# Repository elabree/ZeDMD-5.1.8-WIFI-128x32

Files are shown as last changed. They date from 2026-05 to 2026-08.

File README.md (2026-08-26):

# The Arcade — powered by ZeDMD (WiFi Fork, 128×32, ESP32-S3-N16R8)

> 🇩🇪 **Deutschsprachige Anleitung:** [LIESMICH.md](LIESMICH.md)

**The Arcade** is an ESP32-S3 firmware for a 128×32 HUB75 LED matrix. It turns a pinball DMD panel into a standalone smart display with:

- **Clock + weather** — live data from your own weather station via MQTT (WeeWx), with Open-Meteo as automatic fallback; configurable field names, visual fallback indicator
- **GIF screensaver** — animated GIFs from SD card, sorted alphabetically or shuffled, with optional synchronised MP3 audio per GIF
- **Webradio** — internet radio via I2S amplifier (MAX98357A); station logos, track title, equaliser, L/R swap
- **Web UI** — full configuration and control from any browser on your local network; no app, no account, no cloud

---

> 📝 *This README is a personal project diary rather than a complete guide. It documents what worked for me — your setup may differ. No claim to completeness; errors and omissions are possible.*

---

> **This started as a personal hobby fork of [PPUC/ZeDMD](https://github.com/PPUC/ZeDMD) v5.1.8**
> and has since grown well beyond it — the clock, weather, and webradio features are original
> work built on top, not part of upstream ZeDMD. What *is* inherited from upstream is the core
> DMD protocol handling and the HUB75 display driver — that foundation is why this project
> stays under the same GPLv2-or-later license as ZeDMD itself, and why it remains listed as a
> GitHub fork of it rather than a standalone repo.
> It is shared with the community in the hope that it might be useful — but it comes with **absolutely no support, no warranty, and no guarantee of any kind**.
> Issues and pull requests may not be responded to. Emails and messages regarding this project will likely go unanswered — not out of disrespect, but simply because this is a spare-time project maintained by one person.
> **Use entirely at your own risk.**

---

> ⚠️ **Panel size: only tested with 128×32 (2× chained 64×32 tiles).** The codebase already
> has build environments for larger panels (`256x64` / `S3-N16R8_256x64`, via `ZEDMD_HD`) and
> the core DMD rendering scales automatically with `TOTAL_WIDTH`/`TOTAL_HEIGHT` — but this has
> **not been built or tested**. The weather overlay and GIF screensaver have hardcoded pixel
> positions sized for 128×32 that would need adapting first.
>
> If you do try a larger panel: pay **significantly more attention to power supply sizing**
> than you would for 128×32. A single 64×32 HUB75 tile can draw up to ~25W (5V/5A) at full
> white; going to 256×64 roughly **quadruples the pixel count** versus this project's default
> 128×32 setup, and current draw scales accordingly. Undersized power supplies on large HUB75
> chains cause voltage drop, ghosting/dimming artifacts, and in the worst case connector or
> wiring damage — plan for adequate power injection points along the chain, not just a single
> feed at one corner.

---

https://github.com/jens-b/ZeDMD-5.1.8-WIFI-128x32/raw/main/docs/images/ZeDMD_WiFi_128x32_demo.mp4

---

### Screenshots

| Clock + Weather | Weather Forecast | GIF Screensaver |
|:-:|:-:|:-:|
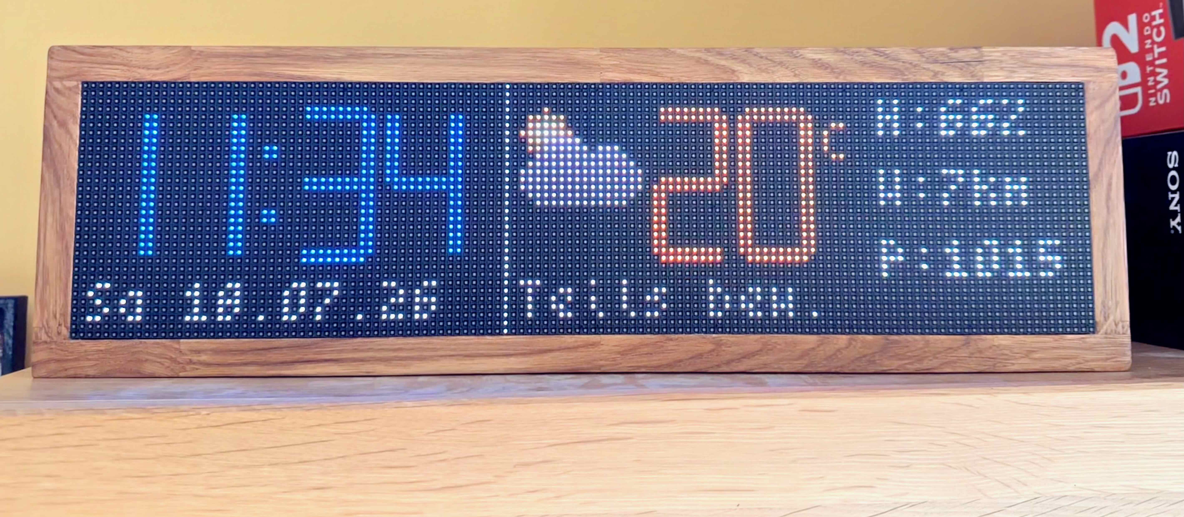
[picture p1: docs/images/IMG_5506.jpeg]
Clock
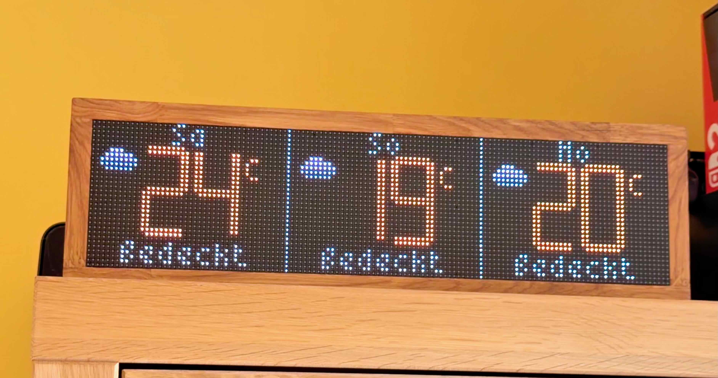
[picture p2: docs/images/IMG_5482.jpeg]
Forecast
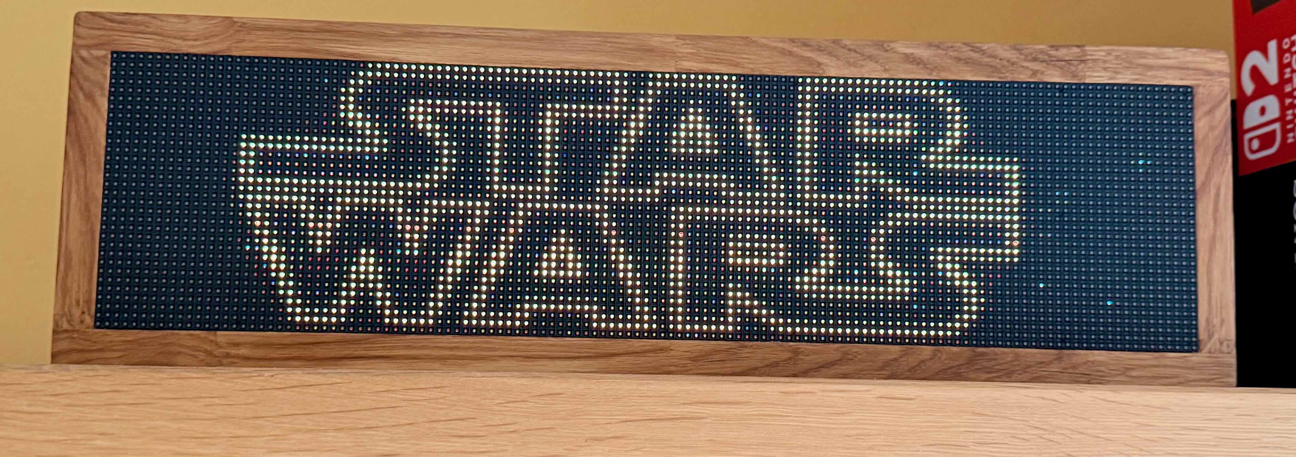
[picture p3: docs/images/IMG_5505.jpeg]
GIF
|  |  |  |

**Webradio — station name and logo on the display:**

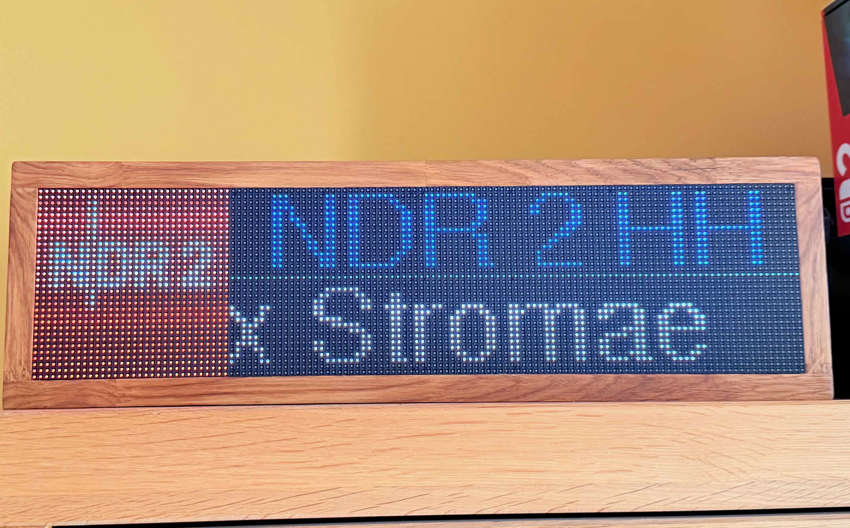
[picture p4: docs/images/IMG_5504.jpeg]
Webradio


**Internals / Back panel:**

| Inside | Back panel |
|:-:|:-:|
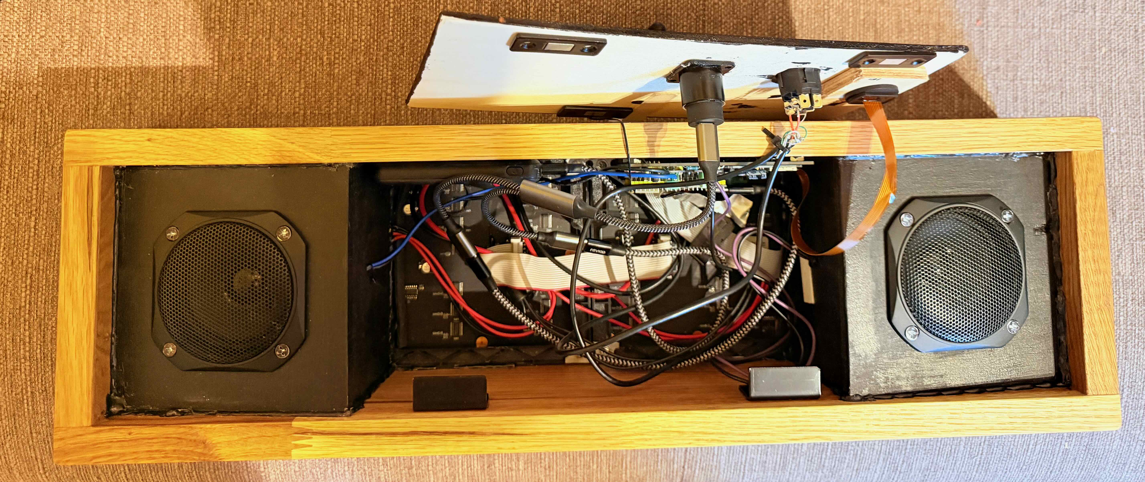
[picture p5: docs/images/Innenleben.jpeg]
Internals
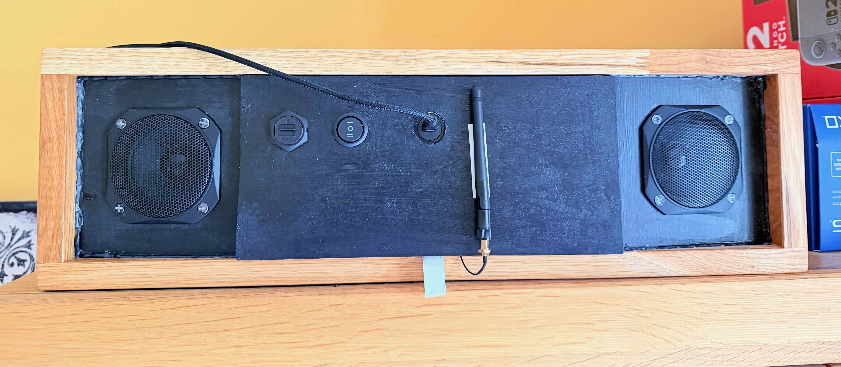
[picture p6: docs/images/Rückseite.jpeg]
Back panel
|  |  |

---

## 🆕 What's new in this release

### v1.7.0 *(this release)*

#### Critical stability fixes — watchdog now actively monitors the main task
A fundamental issue was present since the first WiFi firmware build: `enableLoopWDT()` was never called, meaning the Task Watchdog Timer (TWDT) never actually monitored the main loop task. All `esp_task_wdt_reset()` calls across the codebase were silent no-ops — the device relied only on the secondary IDLE-task starvation mechanism to detect hangs.

With `enableLoopWDT()` now correctly placed at the start of `setup()`, the TWDT actively monitors the loop task against the 5-second budget. This exposed three real hang points that are now fixed:

- **Large screensaver cache** — `TryLoadFolderCache()` reading 3 700+ lines without any watchdog reset caused a reboot loop on devices with many files. Fixed with a reset every 50 lines.
- **SoftAP countdown** — the 19-second WiFi-failure countdown ran without a single reset. Fixed.
- **NTP sync** — `clockInit()` calls `getLocalTime()` with a 5-second timeout, landing exactly on the WDT boundary. A reset is now issued before the call.

Devices that were showing repeated `TASK_WDT` reboot entries in `/diag` after upgrading from a previous firmware version should recover immediately with this release.

#### "The Arcade" startup logo
The boot logo has been updated from the generic PPUC logo to **The Arcade** branding. The crash-screen overlay was also corrected (it previously overwrote the logo during a first-boot crash sequence).

#### Radio icon reload fix
The **Reload Icons** action (`/icons_reload`) now also refreshes the radio icon slug cache. Previously, a newly uploaded station logo only appeared after a full reboot.

#### `/upload_asset` endpoint
A new endpoint accepts any PNG or RAW file and stores it directly in the LittleFS root. Useful for uploading custom boot logos or background assets without a full LittleFS flash.

#### Brightness save respects the display blank timer
Saving brightness via `/save_brightness` previously called `SetBrightness()` directly, which deactivated an active display-blank interval. It now goes through `ApplyBrightness()` and leaves the blank state untouched.

---

### v1.6.0

#### Weather icons — 17×17 pixel art, stored in LittleFS
The main weather icon (top-right of the clock/weather view) has been redrawn at **17×17** instead of 16×16. The odd size places the center on an exact pixel (8, 8) rather than between pixels — sun rays, moon crescent tips and fog lines are now perfectly symmetrical. Specific improvements per icon:

- **Sun** — cardinal rays narrowed to 1 px, lengthened to 3 px; diagonal rays extended toward the body for a more connected look
- **Moon** — wider crescent tips at top and bottom (3 px); crescent ends look rounded rather than pointed
- **Cloud bitmap** — extended from `uint16_t` (16 cols) to `uint32_t` (17 cols); all cloud-based icons benefit
- **Fog** — sixth stripe added at the bottom to fill the extra row
- **Rain / Drizzle / Showers** — drop positions adjusted for equal horizontal spacing

The 11 weather icons are now stored as **RGBA files in LittleFS** (`/icons_weather/`) instead of being hardcoded in the firmware. This means:
- Icons can be **replaced without reflashing** — upload new ones via `/upload_icon_weather`
- The icon set is consistent with the existing system (`/icons/` for emoji, `/icons_radio/` for station logos)
- First-time setup: upload the 11 `weather_*.rgba` files from `data/icons_weather/` after the initial flash

#### Temperature display — tighter minus sign
The minus sign for negative temperatures now **kerns closer to the digit**: for single-digit negatives (`−1` to `−9`) the minus is positioned where the tens digit would be; for two-digit negatives (`−10` to `−19`) it moves 2 px closer to the leading `1`. The result is a more natural, compact look on the 128×32 display.

#### Interactive weather location map
The **Weather (Open-Meteo)** section in `admin.html` now shows a **Leaflet / OpenStreetMap** map. Click anywhere on the map or drag the marker to set your coordinates — no manual lat/lon entry needed. City search is also available. The map initialises at the currently saved coordinates.

#### HUB75 library 3.0.14 + Line Decoder parameter
The ESP32-HUB75-MatrixPanel-DMA library has been updated from **3.0.12 to 3.0.14**. A new **Line Decoder** parameter is now exposed in the Panel section of the admin page — required for panels that use a shift-register-based row decoder instead of direct addressing (rare, but necessary for certain panel types). Default value is 0 (no effect on standard panels). Setting is saved to LittleFS and survives reboots.

#### Removed unused SDMMC build environment
The `S3-N16R8_128x32_wifi_sdmmc_webradio` PlatformIO environment has been removed from `platformio.ini`. It was not actively maintained and only added noise to the build configuration. The standard SPI SD build (`wifi_sd_webradio`) remains the only supported target.

#### 7-segment display styles
Four segment style presets are available under the **Display Settings** section of the web UI:

- **Default** — chamfered corners with junction clearing (original look)
- **Classic** — inner notch at segment junctions; chamfered inner corners
- **Classic 2** — early-build look: L-junction inner pixel + inner chamfer, "0" exempt
- **Modern** — plain rectangular segments, no chamfering

The active style is saved to LittleFS and survives reboots.

#### Glow effect *(beta)*
A **Glow β** button in Display Settings toggles a drop-shadow effect on the clock digits (2 px offset, 30 % brightness). Experimental — not persisted across reboots.

#### Equalizer range extended to ±12 dB
The Bass / Mid / Treble sliders now go from **−12 dB to +12 dB** (previously ±6 dB). Useful for speakers like the FRS8 where cutting bass and boosting treble significantly improves perceived audio clarity.

#### SD card firmware update
Place a `firmware.bin` in the `/UPDATE/` folder on the SD card — on the next boot it is flashed automatically and the file is deleted. A manual trigger button is also available on the **Admin** page for updating without a reboot.

---

### v1.5.3

#### Configurable MQTT field names
The JSON field names used to read weather data from your MQTT broker are now configurable in the admin panel — no reflash required. This matters if your WeeWx (or other weather station) uses non-standard field names. Default values match the standard WeeWx LOOP output: `outTemp_C`, `outHumidity`, `windSpeed_kph`, `barometer_mbar`. Settings are saved to LittleFS and survive reboots.

#### Visual fallback indicator for OpenMeteo data
When MQTT has been silent for more than 10 minutes, the weather display switches to Open-Meteo data as a fallback. All four weather values (temperature, humidity, wind, pressure) are now shown in **grey** instead of white during this fallback period — an immediate visual cue that the data is not coming from your local weather station. After 30 minutes without MQTT, the existing orange **"MQTT fehlt"** text appears as before.

#### Unknown weather code fallback icon
If Open-Meteo returns a WMO weather code that has no matching icon, the display now shows the **question mark icon** (`question.rgba` from the icon set) instead of the misleading cloudy icon that was used before. In practice this should never appear — all codes used by Open-Meteo are handled — but it makes the system more robust.

---

### v1.5.2

#### Tabbed Web UI
The main page has been reorganised into three tabs — **Screensaver**, **Display** and **Radio** — making it much easier to navigate on both desktop and mobile. SD card & storage info plus the Admin button remain always visible above the tabs.

#### Display Timer *(scheduled display off)*
Set a daily on/off schedule for the LED matrix — useful for automatically turning the display off at night. Configure From/Until times under the **Display** tab. A **"Display off / Display on"** button lets you instantly turn the display off and on without changing the timer settings.

#### Stereo / Mono toggle
The **Radio** tab now shows separate **Stereo** and **Mono** buttons next to the volume slider. Switch the audio output to mono without a firmware rebuild — useful if you only have one speaker connected or experience phase issues.

#### Station logos on the LED matrix
When a radio station starts playing, the matching station logo (if uploaded) is shown on the LED matrix alongside the station name and track title.

#### Boot text improvements
Status messages during boot ("booting", "loading...", "SD OK", "LittleFS OK") are now shown at the bottom-left of the display so they no longer overlap the boot logo.

#### Rescan buttons
A **Rescan** button appears in the screensaver file list and the GIF audio file list after an upload — or can be triggered manually at any time. Rescans the SD card and LittleFS without a reboot and updates the file list immediately.

#### SD card SPI speed — up to 40 MHz
On a proper PCB layout (no Dupont wires), the SD card is now initialised at 40 MHz first, with an automatic fallback chain (40 → 25 → 20 → 8 MHz). Previously the maximum was 8 MHz. Faster initialisation and file access, especially noticeable during GIF and audio scans.

#### Equalizer
A three-band **equaliser (Bass / Mid / Treble)** is now available in the **Radio** tab. Settings are saved to LittleFS and survive reboots and station switches.

#### Weather icons — further improvements
The 8×8 forecast icons (3-day view) have been completely redrawn. Three new icons added: drizzle, showers and snow now have their own symbols — previously they shared a generic rain icon. Total: 11 distinct weather icons.

#### L/R channel swap
If your left and right speakers are physically wired the wrong way around, a single **L/R Swap** button in the **Radio** tab swaps the audio channels in software — no rewiring needed. Settings survive reboots.

#### Custom branding
The boot screen and web UI header now show the **The Arcade** logo instead of the generic ZeDMD logo. The PPUC splash screen has been removed.

---

### v1.5.1

#### Weather Icons — native 16×16 pixel art
All 8 weather icons have been redrawn as native 16×16 pixel art — sharper and more detailed than the scaled-up 8×8 bitmaps used before. Each icon has a unique hand-crafted color gradient: sun with rays, crescent moon, cloud, rain drops, snow, lightning bolt, and partly-cloudy variants. The smaller 8×8 icons used in the 3-day forecast were further improved in v1.5.2.

#### SD Card — more robust initialisation
The SD card now retries with progressively slower SPI speeds (8 → 4 → 2 MHz, up to 6 attempts) before giving up. Previously a single failed mount attempt would mark the SD as unavailable for the entire session. This resolves intermittent boot failures with marginally connected or slow-to-mount SD cards.

#### Bug Fixes
- Emoji text: cursor position 0 was treated as falsy in JavaScript — the cursor is now correctly preserved when inserting an emoji at the very start of the input field
- Icon upload: interrupted uploads no longer leave orphaned `.tmp` files on LittleFS
- Icon folder scan: directory handle no longer leaks when a non-directory entry is encountered

---

### v1.5 and earlier

### Webradio
Stream internet radio stations directly through the ZeDMD's built-in speaker.
Requires a **MAX98357A I2S amplifier module** — see wiring below.

- Dedicated station manager at `/radio.html` — search stations via [radio-browser.info](https://www.radio-browser.info), save presets with logo icons
- **Country quick-select buttons** (🇩🇪 DE / 🇦🇹 AT / 🇨🇭 CH / 🇳🇱 NL / 🇫🇷 FR) load the top-100 stations for that country in one tap; Niedersachsen regional filter still available
- Station name, track title and station logo displayed in the web UI
- Volume control via slider on the main page and the radio page
- Station name and track title scroll on the LED matrix for 5 seconds when a station starts, then returns to the screensaver — tap "DMD 10s" to show it again
- Presets survive firmware updates (stored in LittleFS)
- Stable station switching — no more audio dropout on channel change
- Stream URLs from radio-browser.info are automatically normalised (removes `?ti=` playlist hints that caused the audio library to hang)
- **L/R channel swap** — if your left and right speakers are physically wired the wrong way around, a single button in the **Radio** tab swaps the audio channels in software — no rewiring needed

> **Technical note — audio library patch:** The L/R swap feature required modifying the `ESP32-audioI2S` library internally, because it does not provide this function out of the box. Rather than changing the library files by hand (which would be lost on every library update), a build-time patch script (`scripts/patch_audio_lib.py`) injects the change automatically on each compile. This script was developed with the help of **[Claude Code](https://claude.ai/code)** (AI coding assistant by Anthropic) — pinpointing the exact location inside the audio pipeline where samples could be swapped safely, and making the patch idempotent (safe to run repeatedly). I would not have attempted this alone.

> **⚠️ Weather API:** Open-Meteo is accessed via HTTP instead of HTTPS. TLS handshakes consistently caused memory-related crashes in the web radio build. Since Open-Meteo provides public data without requiring a login, HTTPS is not necessary here.

### GIF Preview in the browser
Click any GIF filename in the screensaver file list or the "currently shown" field to open a live animated preview directly in the browser — without touching the display. Favourite, ignore and play controls are available inside the preview.

> **Note:** Opening a GIF preview while webradio is playing may cause brief audio stuttering — SD card access and audio streaming share the same CPU core. This is a known limitation.

### GIF Audio
Play a matching MP3 file from the SD card in sync with an animated GIF screensaver. The filename must match the GIF (e.g. `demo.gif` → `demo.mp3`). Upload audio files via the main page or drop them in `/GifAudio/` on the SD card directly.

- File list is cached in LittleFS — after the first boot scan, subsequent reboots load instantly (same mechanism as the screensaver file cache)
- Paginated file list in the web UI with previous/next buttons (20 files per page)
- Scan can be aborted via the **"Cancel Scan"** button that appears after an upload

> ⚠️ **First-boot scan time:** Depending on how many files are in `/GifAudio/`, the initial scan over SPI can take a very long time. Progress is shown on the display ("GifAudio XXXX"). After the scan the list is cached in LittleFS — every subsequent reboot loads in seconds.

> **Note:** GIF audio plays once per GIF cycle — looping is not yet implemented.

### SDMMC Board Support *(not actively maintained)*
Added support for boards with an **onboard SD card via SDMMC interface** (1-bit mode) — no external SPI module required. See pin table below for the required HUB75 cable changes.

> **Note:** This build variant is not actively maintained. Development focus is on the standard SPI SD build (`wifi_sd_webradio`). The SDMMC variant may work but is not tested with each release.

### GIF Screensaver Order
- **A-Z toggle** — switch between alphabetical and random playback order directly on the main page
- **Reshuffle button** — re-randomise the GIF order at any time without a full reload

### Configurable Timezone
The NTP clock timezone can now be set directly on the admin page — no firmware rebuild required.
A dropdown covers the most common zones (Central Europe, UK, UTC, US East/Central/Mountain/Pacific); a **Custom** option accepts any POSIX timezone string for full flexibility. The setting is stored in LittleFS and survives reboots.

### SD Card Mount / Eject
The main page now shows a **Mount / Eject** toggle button next to the SD card status bar.
- **⏏ Eject** (grey) — safely unmounts the SD card so it can be removed while the device stays powered
- **⏻ Mount** (green) — remounts the card after reinsertion; updates the screensaver file list and GIF audio cache automatically

### Stability & Bug Fixes
This release includes a comprehensive overhaul of memory management and task safety:

- **Admin page no longer crashes** — root cause identified via coredump analysis: lwIP assertion in AsyncTCP 3.3.5 triggered by the Basic Auth handshake. Fixed by updating AsyncTCP to 3.4.10
- Fixed race condition on station switching — audio no longer reverts to the previous station
- Weather data (MQTT + HTTP) now safely synchronized between CPU cores
- SD card directory listing moved out of network callbacks — no more audio stuttering during web access
- Weather HTTP response buffered in PSRAM — eliminates large internal SRAM spike during fetch
- All file uploads are now atomic (`.tmp` + rename) — interrupted uploads no longer leave corrupt files
- `screensaverFiles` array protected by mutex against concurrent web access
- Audio task priority raised above the web server task — reduces stream dropouts under concurrent web traffic

---

## 🧪 Experimental Features

> These features are functional but still being polished. Use at your own risk and expect rough edges.

---

### Batocera WiFi streaming

By default, Batocera's DMD server only streams to a single USB-connected DMD. To stream to a WiFi ZeDMD at the same time, a second `dmdserver` instance needs to be set up manually.

A full step-by-step guide — including dual-DMD marquee control, attract/playing modes, and troubleshooting — is available here:

📄 **[docs/batocera-dual-dmd.md](docs/batocera-dual-dmd.md)** (EN) | **[docs/batocera-dual-dmd-DE.md](docs/batocera-dual-dmd-DE.md)** (DE)

> ⚠️ Tested with Batocera **v42**. Batocera **>v42** may have introduced changes that break this setup. Verify carefully before updating Batocera.

---

### Batocera game start/stop trigger

`scripts/batocera_game_start.sh` and `scripts/batocera_game_stop.sh` trigger GIF audio playback on ZeDMD when a game starts or stops on Batocera. The DMD itself continues to receive live frames from the emulator as usual — these scripts only control the audio layer.

> ⚠️ Not yet fully tested end-to-end — the `/gif_audio_play` endpoint works, but the Batocera-side trigger has not been verified in a real game session.

**How it works:**
- On game start: Batocera sends the ROM name to ZeDMD → ZeDMD plays the matching MP3 from `/GifAudio/` on the SD card
- On game stop: ZeDMD stops audio playback
- Naming convention: ROM filename without extension → `medieval_madness.zip` → `medieval_madness.mp3`

**Setup:**
1. Open both scripts and set `IP_ZEDMD` to your ZeDMD's fixed IP address
2. Copy to Batocera:
   ```bash
   scp scripts/batocera_game_start.sh root@batocera.local:/userdata/system/scripts/gameStart.sh
   scp scripts/batocera_game_stop.sh root@batocera.local:/userdata/system/scripts/gameStop.sh
   ```
3. Place matching MP3 files on the SD card under `/GifAudio/`

> ⚠️ **If a `gameStart.sh` already exists on Batocera** (e.g. from another project), do **not** replace it — append the `curl` call from the script to the existing file instead.

---

### Batocera audio extraction script

`scripts/extract_gif_audio.sh` extracts the first N seconds of audio from Batocera scraped game videos and saves them as MP3 files ready for ZeDMD.

> ⚠️ Tested on Batocera only. Requires `ffmpeg` and `python3` available on the Batocera system.

**Prerequisites:**
- Batocera with SSH access
- `ffmpeg` installed on Batocera (check: `which ffmpeg`)
- `python3` installed on Batocera (check: `which python3`)
- Scraped game videos in `gamelist.xml` (`/userdata/roms/<system>/`)

**Usage (run via SSH on Batocera):**
```bash
ssh root@batocera.local "bash /tmp/extract_gif_audio.sh [options]"
```

| Option | Default | Description |
|---|---|---|
| `--system` | `mame` | ROM system folder name |
| `--limit` | `10` | Max number of files to extract |
| `--duration` | `15` | Clip length in seconds |
| `--out` | `/userdata/zedmd/gif_audio` | Output directory |
| `--game` | *(all)* | Filter by partial game name |

**Workflow:**
1. Copy the script to Batocera: `scp scripts/extract_gif_audio.sh root@batocera.local:/tmp/`
2. Run it via SSH (see above)
3. Open the output folder in Finder: **Network → batocera → share → zedmd → gif_audio**
4. Upload the MP3 files via **`http://<ZeDMD-IP>/`** → GIF-Audio section

---

### Display Text

Send a custom text message to the LED matrix directly from the web UI.

- Static or scrolling display — short texts are shown centered, longer texts scroll automatically
- Color picker for free RGB color selection
- Configurable display duration (5–60 seconds)
- Instantly interrupts any running screensaver or GIF and restores it afterwards
- **Emoji picker** — 34 emojis (❤️ ⭐ 🔥 😊 🎉 and more) rendered as pixel-art icons directly in the scrolling text; icons are stored as RGBA files in LittleFS (`/icons/`)

---

### Stereo Audio

Stereo output using **two MAX98357A modules** — one for the left channel, one for the right.

The SD pin is a voltage-level channel-select strap. The values below were measured and confirmed to work with MAX98357A breakout boards that already have a **1 MΩ resistor from SD to Vin** onboard. If your board has a different onboard resistor, these values will not apply — always check your board's schematic and measure before connecting.

* **Module L (Left Channel):** Connect a **100 kΩ** resistor from SD to VCC **(5V)**.
* **Module R (Right Channel):** Connect a **390 kΩ** resistor from SD to VCC **(5V)**.

The ESP32-audioI2S library outputs stereo I2S natively when playing stereo source files. Each module automatically decodes its designated channel based on the SD pin voltage.

| MAX98357A Pin | ESP32-S3 | Notes |
|---|---|---|
| BCLK | **GPIO 9** | shared — both modules |
| LRC (WSEL) | **GPIO 14** | shared — both modules |
| DIN | **GPIO 21** | shared — both modules |
| SD — Module L | **100 kΩ to VCC** | → **Left channel** |
| SD — Module R | **390 kΩ to VCC** | → **Right channel** |
| VIN | **5V** *(recommended)* | each module separately |
| GND | **GND** | each module separately |

> ⚠️ The resistor values above are verified at **5V only**. For 3.3V supply the right-channel value changes to approx. **210 kΩ** (untested). 3.3V supply is **not recommended** — it increases distortion and loads the 3.3V rail.

> ⚠️ **DISCLAIMER:**
> These resistor values were determined experimentally with a specific MAX98357A breakout board variant that has a 1 MΩ onboard resistor from SD to Vin. Other board variants may require different values. **Always consult the MAX98357A datasheet, check your board's actual schematic, and measure voltages before connecting.**
> **Use entirely at your own risk — no warranty or liability of any kind.**

---

## 🔜 Planned Features

### Custom PCB by [elabree](https://github.com/elabree) ✅
A dedicated carrier board designed and built by [elabree](https://github.com/elabree) — tested and confirmed working with this firmware. The board hosts the ESP32-S3-DevKitC-1-N16R8, an SD card module socket, and two MAX98357A stereo amplifier sockets on a single clean PCB.

Two revisions are available:
- **Rev1.1** — for original Espressif ESP32-S3-DevKitC (0.9″ pin row spacing)
- **Rev1.2** — for most clone boards (1″ pin row spacing)

KiCad sources and Gerber files for ordering at JLCPCB: [KiCad/ZeDMD_WiFi/](https://github.com/jens-b/ZeDMD-5.1.8-WIFI-128x32/tree/main/KiCad/ZeDMD_WiFi) (included in this repository).

A big thank-you to elabree for designing and contributing this board to the project — this would not have happened without his work.

### Code cleanup *(on my list)*
The code has grown organically and is honestly a bit messy in places — I know. I'm planning to clean things up at some point, but no promises on when. It works, which counts for something.

---

## What's different from original ZeDMD

This fork is **WiFi-only** and targets the **ESP32-S3-N16R8** with a **128×32 LED matrix**.

### All added features

- **WiFi OTA firmware update** — flash new firmware directly via browser (`/admin.html`); firmware version with build ID and branch shown on admin page (format: `5.1.8-jb (date) [abc1234@main]`)
- **Screensaver** — GIF/RAW slideshow with clock and weather display (Open-Meteo, plain HTTP for RAM efficiency)
- **Screensaver management** — favorites, ignore list, alphabetical/random order, strict timer, pause/resume
- **GIF Preview** — click any filename to open an animated browser preview; favorite/ignore/play controls inside the preview
- **GIF Audio** — play a matching MP3 from `/GifAudio/` on the SD card in sync with the screensaver GIF; `scripts/extract_gif_audio.sh` extracts audio from Batocera video files
- **Improved web interface** — file management, per-file favorite/ignore buttons, pagination with wrap-around
- **Admin page** — WiFi, display, transport, MQTT, weather settings
- **Webradio** — internet radio via I2S amplifier (MAX98357A); station search via [radio-browser.info](https://www.radio-browser.info); preset management with logo icons; LED matrix shows station info for 5 s on start, "DMD 10s" button for on-demand display
- **Config Export/Import** — full configuration backup and restore via browser (`/config_transfer.html`)
- **Display Text** — send custom text with emojis to the LED matrix via the web UI; static or scrolling with color selection and configurable duration (5–60 s); 34 emojis available via built-in picker
- **LittleFS icon system** — three icon folders: `/icons/` (20×20 emoji/question), `/icons_weather/` (17×17 weather icons, uploadable via `/upload_icon_weather`), `/icons_radio/` (32×32 station logos); splash assets via `/upload_asset`
- **Display Timer** — schedule daily on/off times for the LED matrix (e.g. off at 23:00, on at 07:00); "Display off / Display on" button for instant manual control
- **Tabbed web UI** — main page organised into Screensaver / Display / Radio tabs; SD card & admin always visible
- **Stereo Audio** *(experimental)* — two MAX98357A modules for true stereo output; channel selection via SD-pin resistor strapping (5V only, values verified); Stereo/Mono toggle in the web UI

---

## Hardware — ESP32-S3-N16R8 Note

### 💡 Power supply

The ZeDMD can draw a noticeable amount of current — especially when bright GIFs are displayed, webradio is streaming, and WiFi is active all at once. A laptop USB port or a basic phone charger may not deliver enough stable power for this, which can lead to unexpected reboots or an unstable display.

**If things seem unreliable: use a decent 5V / 2A USB power adapter** (the kind that comes with a good phone or tablet). How much power is actually needed varies quite a bit depending on the content — dark GIFs with no audio use much less than a bright screensaver at full volume.

---

### 🧠 On the verge of a nervous breakdown — what this little chip is actually doing

At any given moment, the ESP32-S3 in this build is simultaneously:

- driving a 128×32 HUB75 LED matrix over DMA
- serving a full web UI with live updates over WiFi
- streaming and decoding webradio (MP3/AAC) over I2S in a dedicated FreeRTOS task
- reading and playing animated GIFs from an SD card
- playing matching MP3 files in sync with those GIFs
- fetching live weather data and rendering icons
- handling MQTT, OTA, file uploads, and a paginated file browser for 2 000+ files
- maintaining a LittleFS cache, crash logs, and boot diagnostics

All of this on a chip with **327 KB of internal SRAM** — of which the WiFi stack, TCP server, and audio buffers claim most at runtime, leaving sometimes less than **1 KB free** at peak load. The 8 MB PSRAM handles the large caches and pixel buffers, but anything touching WiFi or TCP must live in internal SRAM — and that is genuinely tight.

The firmware works hard to keep things stable: PSRAM-backed caches, careful buffer sizing, staggered HTTP requests, and a heap monitor that logs free memory every 30 seconds. But this is a device running at the edge of what its hardware class was designed for — and it shows, in the best possible way.

---

### ⚠️ Missing 5V on VIN pin (IN-OUT solder bridge)

Some ESP32-S3-N16R8 boards do not provide 5V on the VIN pin out of the box.
If your ZeDMD powers up but the LED matrix stays dark or behaves unexpectedly, check the **IN-OUT solder bridge** near the 5V/GND pins.

**Fix:** Close the IN-OUT bridge with a small solder blob to route 5V from USB to the VIN pin.

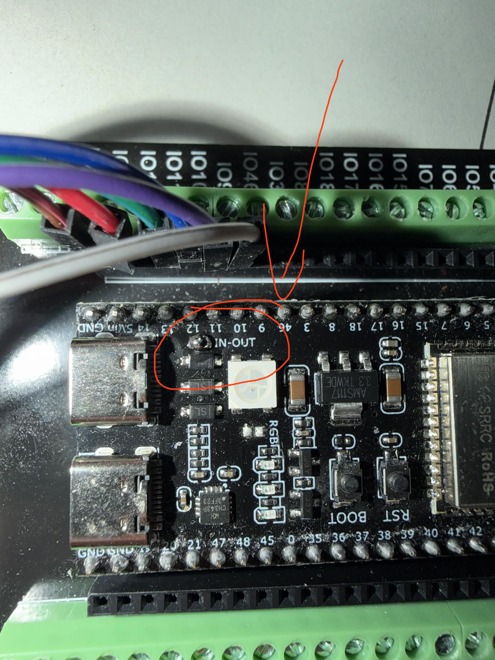
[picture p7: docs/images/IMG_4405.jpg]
IN-OUT bridge location

IN-OUT close-up

> ⚠️ Modifying hardware is at your own risk!

For other known hardware issues and general ZeDMD documentation see the **[original ZeDMD README](https://github.com/PPUC/ZeDMD#readme)**.

---

## SD Card

The screensaver GIF/RAW files can be stored on a microSD card connected via SPI.

**Tested module:**
[Micro SD Card Module SPI (Amazon)](https://www.amazon.de/dp/B0D8Q8N7NQ)

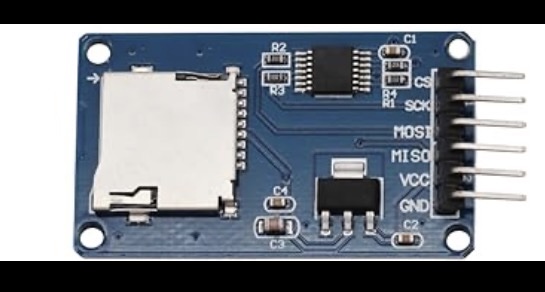
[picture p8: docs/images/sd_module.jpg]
SD Card Module


**Wiring ESP32-S3-N16R8:**

| SD Module | ESP32-S3 Pin |
|---|---|
| VCC | **3.3V** or **5V** ¹ |
| GND | GND |
| MISO | GPIO 13 |
| MOSI | GPIO 11 |
| SCK | GPIO 12 |
| CS | GPIO 10 |

> ¹ Most common SPI SD modules accept both 3.3V and 5V on VCC (they have an onboard regulator).
> Check your module's datasheet. If in doubt, use **3.3V** — the ESP32-S3 GPIO pins are **not** 5V-tolerant.

**Format:** FAT32, files in subfolders (e.g. `/MyGIFs/`). GIF and RAW files supported.

**First-boot scan performance**

> ⚠️ The first scan of a large GIF library can take a very long time — a folder with ~5 400 files takes approximately **35 minutes** over SPI. This is a fundamental SPI/FAT32 limitation: the Arduino SD library opens every file individually to read its name, and FAT32 directories with many entries cannot be indexed.
>
> **After the first scan the file list is cached in LittleFS** (`sc_*.bin`). Every subsequent reboot loads the cache in seconds — no SD scan needed.
>
> **Tips to keep scan times acceptable:**
> - Use **multiple smaller subfolders** instead of one large one (e.g. 5 × 1 000 files instead of 1 × 5 000) — each folder is scanned independently and cached separately.
> - Use a **dedicated upload folder** (small, freshly uploaded files only) — the web UI's "Upload folder" picker lets you target it specifically without touching the large library folder.
> - A planned future optimisation is an **SD-side index file** (`.index` per folder) that replaces directory traversal with a single sequential read — reducing scan time from minutes to under a second regardless of file count.

---

## Web Interface

Access via `http://<IP>/` (main page) and `http://<IP>/admin.html` (admin page).

### Admin page settings

| Section | Description |
|---|---|
| **Firmware Update (OTA)** | Flash new firmware via browser — no USB needed |
| **WiFi** | SSID, password, port |
| **Display** | RGB order, scaling mode, brightness |
| **Transport** | USB / WiFi UDP / TCP / SPI, UDP delay, USB packet size |
| **Panel** | Clock phase, I2S speed, latch blanking, refresh rate, driver |
| **MQTT** | Server IP and port for weather integration |
| **Weather (Open-Meteo)** | Latitude/longitude for local weather display |
| **Update Web Files** | Upload index.html / admin.html without full filesystem flash |
| **Upload Weather Icons** | Upload 17×17 RGBA icons to LittleFS `/icons_weather/` via `/upload_icon_weather` |
| **Upload Assets** | Upload PNG/RAW splash images to LittleFS root via `/upload_asset` |
| **Config Export/Import** | Full config backup/restore via `/config_transfer.html` |
| **Information** | Firmware version, build date and git hash, debug info |

---

## Pin Assignment ESP32-S3-N16R8

### HUB75 LED Matrix

| Signal | GPIO | Note |
|---|---|---|
| R1 | 4 | |
| G1 | 5 | |
| B1 | 6 | |
| R2 | 7 | |
| G2 | 15 | |
| B2 | 16 | |
| A | 18 | |
| B | 8 | |
| C | 3 | |
| D | 42 | |
| E | 1 | not used - only for 256×64 |
| OE | 2 | |
| LAT | 40 | `wifi_sd_webradio` |
| LAT | **46** | `wifi_sdmmc_webradio` — rewire! |
| CLK | 41 | `wifi_sd_webradio` |
| CLK | **17** | `wifi_sdmmc_webradio` — rewire! |

> HUB75 LAT/CLK only need to be moved on the **SDMMC board**, because GPIO 40/41 are used internally for the SD card there.

### SD Card

| Signal | GPIO | Build |
|---|---|---|
| CS | 10 | `wifi_sd_webradio` (SPI) |
| MOSI | 11 | `wifi_sd_webradio` (SPI) |
| SCK  | 12 | `wifi_sd_webradio` (SPI) |
| MISO | 13 | `wifi_sd_webradio` (SPI) |
| DATA | 40 | `wifi_sdmmc_webradio` (SDMMC onboard) |
| CLK  | 39 | `wifi_sdmmc_webradio` (SDMMC onboard) |
| CMD  | 38 | `wifi_sdmmc_webradio` (SDMMC onboard) |

### Buttons

| Function | GPIO |
|---|---|
| UP | 0  |
| DOWN | 45 |
| FORWARD  | 48 |
| BACKWARD | 47 |

### Webradio (optional)

Requires an **I2S amplifier module** and a small speaker.

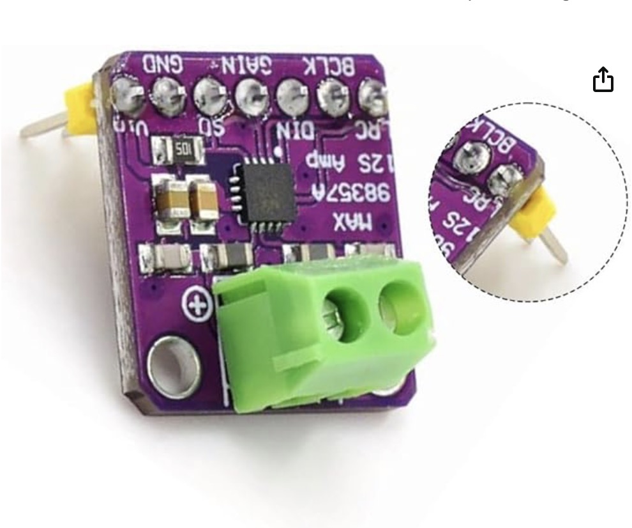
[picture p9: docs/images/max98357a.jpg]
MAX98357A module


**Tested amplifier: MAX98357A**
- Breakout module (e.g. Adafruit #3006 or common clones)
- Speaker: **8 Ω / 3 W** — e.g. **Visaton FSR 7** (77 mm, good sound for the size)
- Output power: up to 3 W — adequate for a cabinet at moderate volume

### MAX98357A Wiring — Mono (SD and SDMMC builds)

| MAX98357A Pin | ESP32-S3 | Notes |
|---|---|---|
| VIN | **5V** | 5V gives more headroom; 3.3V works but lower volume |
| GND | GND | |
| BCLK | **GPIO 9** | I2S Bit Clock |
| LRC (WSEL) | **GPIO 14**  | I2S Word Select (L/R) |
| DIN | **GPIO 21**  | I2S Data |
| GAIN | **GND** | GND = 15 dB gain (max); floating = 12 dB; 3.3V = 9 dB |
| SD (Shutdown) | 3.3V or floating | Floating = on; GND = mute |

> Class-D mono amplifier. Connect speaker to OUT+/OUT− only — **not** to GND (differential/BTL output).

### Build / Environment Overview

| Setup | Environment | Extra hardware |
|---|---|---|
| Existing board + SPI SD module | `S3-N16R8_128x32_wifi_sd_webradio` | Connect MAX98357A |

### Webradio — Configuration

Open `http://<IP>/` after flashing — radio controls appear directly on the main page:

| Control | Description |
|---|---|
| **▶ / ■** | Play last preset / Stop |
| **Station buttons** | Start a saved preset directly |
| **Volume** | Slider on the main page and on `/radio.html` |
| **DMD 10s** | Show station info on the LED matrix for 10 seconds; auto-hides after 5 s when a station starts |

Full preset management at **`http://<IP>/radio.html`**.
Presets are stored in LittleFS (`/radio_presets.json`) and survive firmware updates.
Config transfer between boards: `http://<IP>/config_transfer.html`

---

## Weather (Open-Meteo)

Weather and 3-day forecast fetched from [Open-Meteo](https://open-meteo.com/) — free, no API key required.
Set your coordinates in `admin.html` → **Weather (Open-Meteo)**.

### ⚠️ Why HTTP, not HTTPS

The audio codec (MP3/AAC) occupies ~50 KB of internal SRAM at runtime. A TLS handshake needs an additional ~30–40 KB of contiguous internal SRAM — a guaranteed out-of-memory crash on the webradio build. Since Open-Meteo serves fully public weather data with no authentication tokens, plain HTTP is completely safe here.

> `http://api.open-meteo.com/v1/forecast` — explicitly supported by Open-Meteo for embedded/IoT devices.

---

## Installation

### First flash (USB, one time only)

The first flash must include the LittleFS filesystem image — otherwise the web interface won't load after boot. Use the merged image approach:

```bash
pio run                              # build firmware
pio run -t buildfs                   # build LittleFS image from data/
python3 scripts/merge_firmware.py    # create merged flash image
```

Then flash the resulting `*_merged.bin` from `~/Desktop/Firmwares/`:

```bash
esptool.py --chip esp32s3 --port /dev/cu.usbmodem* --baud 460800 \
  write_flash --no-compress 0x0 "ZeDMD_..._merged.bin"
```

> ⚠️ **`--no-compress` is required.** The LittleFS partition occupies 6.5 MB of flash. Without `--no-compress`, esptool compresses the transfer — this causes a timeout on the large partition and the ESP hangs mid-flash. Always use `--no-compress` for the full merged image.

### After first boot

The web interface loads immediately. Upload updated HTML files if needed:
**`http://<IP>/admin.html`** → "Update Web Files"

### Future firmware updates (OTA, no USB needed)

Browser → **`http://<IP>/admin.html`** → "Firmware Update (OTA)"

---

## Credits

- **[Markus Kalkbrenner / PPUC](https://github.com/PPUC/ZeDMD)** — original ZeDMD project
- **[elabree](https://github.com/elabree)** — PCB design: carrier board for DevKit + SD + MAX98357A ([KiCad files](https://github.com/jens-b/ZeDMD-5.1.8-WIFI-128x32/tree/main/KiCad))
- **Niels (My Son)** — coding assistance & inspiration & moral support
- **[Claude Sonnet](https://anthropic.com)** — coding assistance

---

## Commercial Use

This project is licensed under GPL v2 — commercial use is permitted under those terms.

---

## License

Same as the original project — see [LICENSE](LICENSE).

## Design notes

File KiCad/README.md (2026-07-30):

# ZeDMD_WiFi PCB
This is a carrier board for the ESP32-S3-DevKitC-1-N16R8 with the following features:
- ZeDMD compatible HUB75 connector for RGB Matrix Panels and 4 push-buttons
- 5V terminal block with 2 different use cases:
  - Output for the RGB panels, using power from USB-C (a jumper on J5 selects between the DevKit or USB-C breakout at J8)
  - Input for the DevKit, in case the RGB panels are on an external supply (jumper on J6)
- A socket (J2) for a Micro SD Card module. Note that this module needs to have a 5V - 3.3V regulator. Always check that the pinout of your module corresponds to the [schematics diagram](ZeDMD_WiFi/docs/ZeDMD_WiFi.pdf)
- Two sockets (J1 and J3) for MAX98357A amplifier modules (Adafruit i2s class-d mono-amp). A jumper on J4 selects between 3 power options (Devkit 3.3V, Devkit USB-C 5V, USB-C breakout at J8).
- A socket ()J8 for a USB-C breakout board for MAX98357A power. It can also be used if there is no other power source for the Devkit, or to power the RGB panels when selected by a jumper on J5.

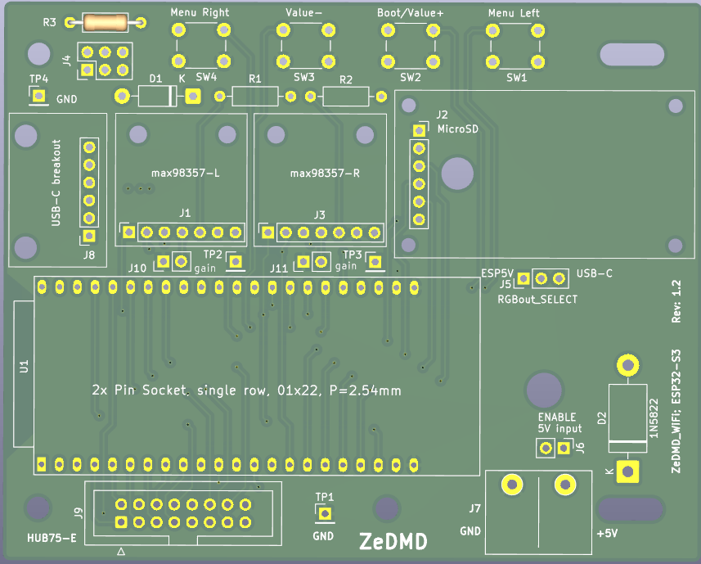
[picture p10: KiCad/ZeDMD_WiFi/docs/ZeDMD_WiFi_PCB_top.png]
ZeDMD_WiFi_PCB_top


## Power budget
The power supply voltage is +5V.

### USB-C limitation
The maximum current USB-C can deliver at 5V is 3A (Pmax = 15W). It does not matter that a USB-C PD port is able to deliver more power because that means using a higher voltage. This is not possible with this design!

### RGB matrix panel
Two 64x32 RGB matrix panels draw 5A (25W) at 100% intensity. Since these panels are designed for daylight operation, this intensity is really high. Usually no more than 50% is needed (2.5A, 12.5W). This leaves sufficient power (0.5A; 2.5W) for the DevKit and SD card.

### MAX98357A modules
The required power for the amplifiers depends on the supply voltage (3.3V or 5V) and the connected speakers. If there is insufficient power avalable, the supply may dip during loud sounds causing clipping at the output. This may damage the speakers. Also, the amplifiers have a volume dependent distortion which is less at 5V for the same volume.

#### Power needs for 2 MAX98357A modules:
| Vin | Rspeaker | Pout_max | Iin (Pin)  |
| --- | --- | --- | --- |
| 3.3V| 8 ohm | 0.9 W | 0.6 A (2 W) |
| 3.3V| 4 ohm | 1.6 W | 1.1 A (3.6 W) |
| 5V  | 8 ohm | 1.8 W | 0.9 A (4.5 W) |
| 5V  | 4 ohm | 3.2 W | 1.6 A (8 W) |

### Power supply Recommendations
1. If USB-C is the preferred way to power everything: Then it is best to use the USB-C breakout power the RGB matrix panel (3W for the LED's); place a jumper at J5 2-3. A second USB-C cable on the DevKit powers the SD card and the amplifier modules; place a jumper at J4 3-4.
2. The best alternative is a 5V Meanwell (clone) switchmode power supply (SMPS). Connect the RGB matrix panels directly to this supply. If the DevKit is powered with USB-C there must be no jumpers on J5 & J6, the USB-C breakout is not needed, choose a 25W power supply in this case.
3. It is also an option to use a 5V SMPS for everything in case there is no USB-C connection. Then, J7 is used as the +5V supply input for the DevKit, SD card and amplifier modules. A 40W power supply feeds the RGB matrix panels directly, with an additional cable to J7. Place a jumper at J6, no jumper at J5!
*Note that options 2 and 3 allow full brighness of the RGB panels*

## Options
The general recommendation is: only mount the parts you will be using. So, if you don't need speaker outputs, don't mount the amplifier modules. If you don't use the push buttons, there is no need to mount them.

### RGBout at J7
Diode D2 will cause a voltage drop of 0.7 V to reduce voltage at the panels. The main reason is that some RGB panels do not work correctly at 5V. If the RGB panels work correctly at 5V, a wire bridge can be used instead of the diode.
A jumper on J5 is needed to select the power source.

### 5Vin at J7
As explained a jumper (or wire bridge) at J6 is only needed if the DevKit does not have an USB-C connection. In that case J7 becomes the 5V input.

### MAX_Vin
J4 selects the power source for the amplifier modules. The best option is a jumper between pins 3-4 (+5V from DevKit)

### MAX98357A gain
J10 and J11 can be used to select the amplifier gain. The default gain is 9dB if nothing is connected. For 12dB place a jumper or wire bridge. A 100k resistor can be placed for even more gain (15dB).
*Note that this only adjusts the volume, it will not increase the maximum output power.* TP2 and TP3 are connected to Vin. These testpoints are normally not needed. But these can be used to decrease the gain if needed...

## More information
[Licensed under the TAPR Open Hardware License (www.tapr.org/OHL)](LICENSE.txt)
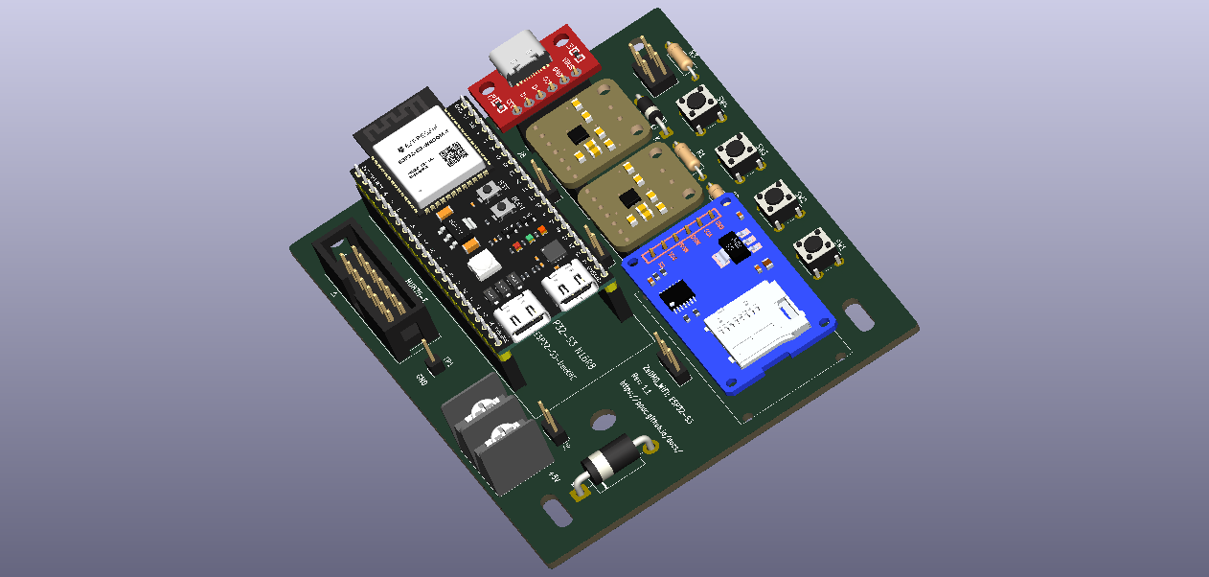
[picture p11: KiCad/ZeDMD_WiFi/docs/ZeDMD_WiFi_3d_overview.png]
ZeDMD_WiFi_PCB_top

[info](ZeDMD_WiFi/docs)

## Gerber and Drill files for PCB ordering
1. The Espressif ESP32-S3-DevKitC has 0.9" distance between rows: [production_Rev1.1.zip](/KiCad/ZeDMD_WiFi/production_Rev1.1.zip)
2. Most clones have 1" distance between rows: [production_Rev1.2.zip](/KiCad/ZeDMD_WiFi/production_Rev1.2.zip)
Example [ordering information](ZeDMD_WiFi/docs/ZeDMD_WiFi_JLCPCB_ordering.png)

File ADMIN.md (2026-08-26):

# ZeDMD Developer Reference

Entwickler-Dokumentation für das ZeDMD-5.1.8 WiFi 128×32 Projekt.

---

## Hardware

| Komponente | Details |
|---|---|
| SoC | ESP32-S3-N16R8 (16 MB Flash, 8 MB PSRAM) |
| Display | 128×32 HUB75 LED-Matrix (RGB888, 3 Byte/Pixel = 12.288 Byte/Frame) |
| SD-Karte | SPI-Bus: SCK=12, MISO=13, MOSI=11, CS=10 |
| Audio (I2S) | **2× MAX98357A (Stereo)**, Pins: BCK=9, WS=14, DATA=21 — Kanalwahl per SD-Pin-Widerstand gegen 5V: L=100 kΩ, R=390 kΩ (Breakout-Boards haben 1 MΩ onboard SD→Vin) |
| Display-Bus | ESP32-S3 LCD-Peripheral mit DMA (kein Software-Bitbanging) |

### Entwickler-Board v2

Abweichende SD/I2S-Pins — in `platformio_override.ini` als separates Environment `wifi_sd_webradio_devboard_v2` definiert (nicht im Repo).

---

## Flash-Partitionen

```
nvs        data/nvs        0x9000     20 KB   WiFi-Credentials, NVS-Variablen
otadata    data/ota        0xE000      8 KB   OTA-Boot-Slot-Auswahl
app0       app/ota_0      0x10000   3200 KB   Firmware-Slot A
app1       app/ota_1     0x330000   3200 KB   Firmware-Slot B (OTA-Target)
spiffs     data/spiffs   0x650000   9916 KB   LittleFS (Icons, HTML, Settings)
coredump   data/coredump 0xFDF000    128 KB   Panic-Coredump (fest reserviert)
```

---

## Build-System

### Umgebungen

```bash
pio run          # beide Environments bauen (default_envs in platformio_override.ini)
```

Niemals `-e` verwenden — immer beide Environments bauen.

### Build-Workflow (Pflicht-Reihenfolge)

```bash
# 1. Test-Build: prüft Kompilierung
pio run

# 2. Commit (erst nach grünem Build)
git commit -m "..."

# 3. Release-Build: bettet korrekten Git-Hash ein
pio run

# 4. Firmware kopieren
HASH=$(git rev-parse --short HEAD)
BRANCH=$(git rev-parse --abbrev-ref HEAD | sed 's|/|-|g')
cp .pio/build/S3-N16R8_128x32_wifi_sd_webradio/firmware.bin \
   ~/Desktop/Firmwares/ZeDMD_5.1.8-jb_S3-N16R8_128x32_wifi_sd_webradio_${BRANCH}_${HASH}.bin
cp .pio/build/S3-N16R8_128x32_wifi_sd_webradio/firmware.elf \
   ~/Desktop/Firmwares/ZeDMD_5.1.8-jb_S3-N16R8_128x32_wifi_sd_webradio_${BRANCH}_${HASH}.elf
# analog für devboard_v2
ls -t ~/Desktop/Firmwares/*.elf | tail -n +3 | xargs rm -f   # max 2 ELFs behalten
```

> **Warum ELF archivieren?** Coredumps sind nur mit dem ELF der exakt gleichen Firmware analysierbar. Nach jedem Rebuild wird das ELF überschrieben.

### Upload-Regeln

| Was | Wie |
|---|---|
| Firmware (`src/`) | PlatformIO flashen via USB |
| HTML/CSS/JS (`data/`) | `POST /upload_file` im Browser — kein Datenverlust, kein PlatformIO |
| Einzelne LittleFS-Dateien (`.raw`, `.png`, `.html`, …) | **ESP Connect Tool** — verbindet direkt mit LittleFS, lädt einzelne Dateien hoch ohne Datenverlust. Kein `uploadfs` (löscht alle Einstellungen!) |
| Icons (`data/icons/`) | `POST /upload_icon` oder `/upload_icon_small` |
| GIFs/Screensaver | `POST /upload_screensaver` oder direkt auf SD |

---

## Architektur

### Speicher-Strategie

```
Interner Heap (~214 KB dynamisch):
  - HTTP-Server-Puffer, FreeRTOS-Task-Stacks
  - Temporäre Puffer (<10 KB pro Allokation)
  - NIEMALS String += in Schleifen — führt zu Fragmentierung

PSRAM (8 MB, ~7.4 MB frei):
  - renderBuffer[]      3×  12.288 Byte  (~36 KB, Triple-Buffering Pixel-Daten RGB888)
  - screensaverFiles    N×    128 Byte   (~350 KB bei 2800 GIFs, via heap_caps_realloc wachsend)
  - cachedSDFolders     variabel JSON    (wenige KB, SD-Ordnerliste)
  - cachedGifAudioFiles variabel JSON    (bis ~300 KB während Scan, danach realloc auf Exactgröße)
  - logBuffer           80×   120 Byte  (~10 KB Ringpuffer)
  - uncompressBuffer         2.048 Byte  (UDP-Dekompression)
  - gifReadAheadBuf          4.096 Byte  (nur während GIF-Wiedergabe aktiv)
```

**Regel:** Alle Caches und Listen die >10 KB sein können → `heap_caps_malloc(..., MALLOC_CAP_SPIRAM)`.  
JSON-Aufbau in Schleifen → direkt per `snprintf` in PSRAM-Puffer, nie per Arduino `String +=`.

### Display-Pipeline

```
UDP/TCP-Paket → Dekodierung → renderBuffer[currentRenderBuffer]
                                      ↓
                              FillPanelRaw(buf)
                                      ↓
                          DMA → HUB75 LED-Matrix
```

- `NUM_RENDER_BUFFERS = 3` (Triple-Buffering für ruckelfreie Ausgabe)
- `currentRenderBuffer` / `lastRenderBuffer` — kein Mutex in `loop()` (bewusste Design-Entscheidung für maximale FPS)
- `renderBuffer[]` wird **vor** `LittleFS.begin()` allokiert (PSRAM-Allokation früh, vor Display-Init)

### FreeRTOS

| Task | Core | Prio | Stack | Beschreibung |
|---|---|---|---|---|
| loopTask (Arduino) | Core 1 | 1 | 32 KB | setup() + loop(), HTTP-Responses, Screensaver, Display |
| radioTask | Core 0 | 11 | 16 KB | ESP32-audioI2S Webradio-Streaming (intern) |
| async_tcp | Core 0 | 10 | ~8 KB | AsyncWebServer / AsyncTCP |
| mqttTask | Core 0 | 1 | 8 KB | MQTT-Reconnect + mqttClient.loop() |
| Task_ReadSerial | Core 0/1 | 1 | 4–8 KB | Serielle ZeDMD-Protokoll-Kommunikation |
| Display-Refresh | Core 0 | — | — | DMA-gesteuert, kein FreeRTOS-Task |

**WDT-Budget:** `CONFIG_ESP_TASK_WDT_PANIC=y` — TASK_WDT löst Panic aus.  
In `setup()` nach jeder längeren Operation `esp_task_wdt_reset()` aufrufen.  
LittleFS-Writes können auch ohne Schleife >5 s dauern (Flash-Fragmentierung).

### Screensaver-Cache

```cpp
char (*screensaverFiles)[128]  // PSRAM, via heap_caps_realloc wachsend
uint16_t screensaverCount      // aktuelle Anzahl
```

Wird in `loop()` nach `screensaverReloadNeeded == true` via `LoadScreensaver()` befüllt.  
Kein Mutex für Lese-Zugriff in `loop()` — bewusst (ruckelfreie GIF-Wiedergabe + UDP-Throughput).  
Mutex nur für Web-Handler-Zugriff (`screensaverFilesMutex`).

### GIF-Audio-Cache

```cpp
char* cachedGifAudioFiles  // PSRAM, JSON-String: [{"name":"foo.mp3","size":12345},...]
```

Wird **nicht** in `loop()` befüllt, sondern einmalig beim Start via `TryLoadGifAudioCache()` aus LittleFS (`/gif_audio_cache.bin`) geladen. Nur bei Cache-Miss: vollständiger SD-Scan in `BuildGifAudioCache()` (~130 s bei 1958 Dateien), danach `SaveGifAudioCache()` schreibt kompaktes `name|size\n`-Format zurück nach LittleFS.

**Besonderheiten:**
- `/gif_audio_files`-Endpoint sendet `cachedGifAudioFiles` **direkt** als HTTP-Response — kein Serialisierungsschritt
- Alphabetische Sortierung erfolgt **clientseitig** per `localeCompare` in `gifAudioLoad()` (FAT-Verzeichnisreihenfolge ≠ alpha)
- `f.name()` muss via `strncpy` **vor** `f.close()` kopiert werden — SdFat2 invalidiert den internen Namenspuffer beim Close
- Architektur-Unterschied zu Screensaver: kein struct-Array, kein wahlfreier Index-Zugriff — geplantes Refactoring: P4 #58

**Invalidierung:**
- `InvalidateGifAudioCache()` löscht `/gif_audio_cache.bin` auf LittleFS → nächster `TryLoadGifAudioCache()`-Aufruf schlägt fehl → Neu-Scan
- RAM-Pointer `cachedGifAudioFiles` bleibt bis zum abgeschlossenen Scan mit alten Daten (oder `"[]"`) gefüllt

---

## Boot-Sequenz

```
setup()
  ├─ renderBuffer[] allokieren (PSRAM, vor LittleFS)
  ├─ LittleFS.begin() + lfsTotal/lfsUsed cachen (verhindert TASK_WDT via /fs_info)
  ├─ diagBoot()               — Crash-Log schreiben falls letzter Boot ein Crash war
  ├─ esp_task_wdt_reset()
  ├─ Display-Init + DisplayLogo() + "booting"-Text   — Logo sofort sichtbar (~2s)
  ├─ esp_task_wdt_reset()
  ├─ CleanupTmpFiles()
  ├─ Load*() × 8              — Settings aus LittleFS (kann 10+ s dauern)
  ├─ esp_task_wdt_reset()
  ├─ LoadIcons()              — RGBA-Icons aus LittleFS + radioIconSlugsLoad() (~6s bei 219 Icons)
  ├─ InitSDCard()
  ├─ GetSDFolders()           — SD-Ordner in PSRAM cachen
  └─ screensaverReloadNeeded = true

loop()
  ├─ screensaverReloadNeeded → LoadScreensaver()
  ├─ Screensaver-Tick
  ├─ Radio-Update
  ├─ Wetter-Update
  └─ sdFoldersRefreshNeeded → GetSDFolders()
```

---

## LittleFS-Inhalt (`data/`-Ordner)

Der `data/`-Ordner wird via `pio run -t buildfs` in `littlefs.bin` gepackt und ist Teil der Merged Firmware. Ein frisches Gerät bekommt damit alles auf einmal.

| Pfad | Inhalt | Anzahl |
|---|---|---|
| `data/index.html` | Web-UI Hauptseite | 1 Datei |
| `data/radio.html` | Web-UI Radio-Sektion | 1 Datei |
| `data/icons/` | 20×20 RGBA Emoji-Icons (Lauftext, Wetter) | 38 Dateien |
| `data/icons_small/` | 10×10 RGBA Emoji-Icons (kleine Darstellung) | 38 Dateien |
| `data/icons_radio/` | 32×32 RGBA Sender-Logos | 219 Dateien |

> **Wichtig:** Alle Icons und Logos liegen im Repo unter `data/`. Das Merged-Image enthält alles — kein manueller Upload nach dem Erstflash nötig.

---

## Scripts (`scripts/`-Ordner)

| Script | Sprache | Was es tut |
|---|---|---|
| `merge_firmware.py` | Python | Erstellt All-in-One Flash-Image (Bootloader + Partitionen + Firmware + LittleFS) für Erstflash per USB. Aufruf: `python3 scripts/merge_firmware.py [ENV]` |
| `upload_icons.sh` | Bash | Lädt alle RGBA-Icons aus `data/icons/`, `data/icons_small/` und `data/icons_radio/` per HTTP auf ein laufendes Gerät hoch. Aufruf: `./scripts/upload_icons.sh <IP>` |
| `convert_icons.py` | Python | Konvertiert Emoji-GIFs (aus `~/Downloads/zedmd-emoji-gifs/`) und Wetter-GIFs in RGBA-Binärdateien für `data/icons/` und `data/icons_small/`. Benötigt Pillow. |
| `make_radio_logos.py` | Python | Konvertiert DAB+-Logos (ZIPs, radioart-Ordner, manuelle PNGs) in 32×32 RGBA-Dateien für `data/icons_radio/`. Mapping via `radioart_map.csv`. |
| `extract_gif_audio.sh` | Bash | Läuft direkt auf Batocera per SSH. Extrahiert Audio-Clips aus gescrapten Spielvideos als MP3 für den `/GifAudio/`-Ordner auf der SD-Karte. |
| `batocera_game_start.sh` | Bash | Ablage auf Batocera als `/userdata/system/scripts/gameStart.sh`. Triggert beim Spielstart den `/gif_audio_play`-Endpoint des ZeDMD. IP im Script anpassen. |
| `batocera_game_stop.sh` | Bash | Ablage auf Batocera als `/userdata/system/scripts/gameStop.sh`. Stoppt GIF-Audio beim Spielende. |
| `copy_firmware.py` | Python | PlatformIO `extra_scripts`-Hook: bettet Git-Hash und Branch als C-Defines in den Build ein. Wird automatisch von PlatformIO aufgerufen, nie manuell. |
| `patch_audio_lib.py` | Python | PlatformIO `extra_scripts`-Hook: patcht `ESP32-audioI2S` bei GCC14 (min()-Typkonflikt). Wird automatisch aufgerufen. |
| `adjust_raw_img.py` | Python | Hilfstool: lädt eine 256×64 RGB-RAW-Datei und erlaubt Bildanpassungen. Für Entwicklung/Debug. |
| `display_raw_img.py` | Python | Hilfstool: zeigt eine 128×32 RGB-RAW-Datei an (ppuc.raw). Für Entwicklung/Debug. |
| `radioart_map.csv` | CSV | Mapping-Tabelle DAB+-Service-ID (hex) → Slug für `make_radio_logos.py`. |

---

## Icons

### Große Icons (20×20 RGBA)

- Pfad auf LittleFS: `/icons/<name>.rgba`
- Geladen beim Boot via `LoadIcons()` in `iconTable[]` (PSRAM)
- Genutzt für: Emoji-Lauftext, Wetter-Icons

### Kleine Icons (10×10 RGBA)

- Pfad auf LittleFS: `/icons_small/<name>.rgba`
- Werden **nicht** beim Boot geladen (zu viele, werden nicht genutzt)
- Dateien bleiben auf LittleFS, können on-demand gelesen werden

### Wetter-Icons — WMO-Code-Mapping

OpenMeteo liefert einen `weather_code` (WMO-Standard, Teilmenge). Das Display wählt daraus ein Icon:

| WMO-Code(s) | Beschreibung | Icon-Nr | Icon-Datei |
|---|---|---|---|
| 0, 1 (Tag) | Sonnig / Heiter | 0 | *(gezeichnet)* |
| 0, 1 (Nacht) | Klar | 6 | *(Mond, gezeichnet)* |
| 2 (Tag) | Teils bewölkt | 1 | *(gezeichnet)* |
| 2 (Nacht) | Teils bew. (Nacht) | 7 | *(Mond+Wolke, gezeichnet)* |
| 3 | Bedeckt | 2 | *(gezeichnet)* |
| 45, 48 | Nebel | 10 | *(gezeichnet)* |
| 51–57 | Nieselregen | 3 | *(gezeichnet)* |
| 61–67 | Regen | 8 | *(gezeichnet)* |
| 71–77 | Schnee | 4 | *(gezeichnet)* |
| 80–82 | Schauer | 9 | *(gezeichnet)* |
| 85–86 | Schneeschauer | 4 | *(gezeichnet)* |
| 95+ | Gewitter | 5 | *(gezeichnet)* |
| alle anderen | Unbekannt | 255 | `icons/question.rgba` |

Der aktuelle `weather_code` erscheint im Log als `Wetter: Code=<n> isDay=<0/1>` bei jedem OpenMeteo-Fetch (~alle 15 Min.).

**Priorität:** MQTT liefert Temperatur, Luftfeuchtigkeit, Wind, Druck mit höchster Priorität. OpenMeteo liefert immer: `weather_code` (Icon) + Forecast. OpenMeteo liefert Messwerte nur wenn MQTT >10 Min. still war (grau auf Display) oder nicht konfiguriert ist.

### Radio-Icons (on-demand)

- Pfad auf **LittleFS**: `/icons_radio/<slug>.rgba`
- Slug-Liste wird beim Boot via `radioIconSlugsLoad()` in PSRAM gecacht (256 × 32 Byte)
- Beim Senderwechsel: Fuzzy-Match gegen PSRAM-Cache, dann einzelnes RGBA-File-Read aus LittleFS
- Slug aus Sendername: Kleinbuchstaben, Sonderzeichen → `_`

---

## Crash-Analyse

### Diagnose-Endpoints

```bash
curl http://<IP>/diag                  # Boot-Statistik + verfügbare Crash-Slots
curl http://<IP>/crashlog?n=0          # Crash-Log Slot 0 (letzter Serial-Log des Absturz-Boots)
curl -o coredump.bin http://<IP>/coredump   # Roher ELF-Coredump
```

### Coredump analysieren

```bash
~/.platformio/penv/bin/python -m esp_coredump info_corefile \
  --core coredump.bin --core-format raw \
  --gdb ~/.platformio/tools/toolchain-xtensa-esp-elf/bin/xtensa-esp32s3-elf-gdb \
  ~/Desktop/Firmwares/ZeDMD_5.1.8-jb_S3-N16R8_128x32_wifi_sd_webradio_main_<HASH>.elf
```

> Coredump und ELF **müssen von derselben Firmware-Version** stammen — SHA256 muss übereinstimmen.

### addr2line für Backtrace-Adressen

```bash
~/.platformio/tools/toolchain-xtensa-esp-elf/bin/xtensa-esp32s3-elf-addr2line \
  -e ~/Desktop/Firmwares/<name>.elf -f 0x<ADRESSE>
```

### Diagnose-Reset

```bash
curl -X POST http://<IP>/reset_diag       # Boot-Zähler zurücksetzen
curl -X POST http://<IP>/delete_crashlogs # Crash-Logs löschen
```

> **Coredump-Partition:** Immer 128 KB reserviert. Löschen gibt keinen Flash-Platz frei — nächster Crash überschreibt automatisch.

---

## Bekannte Constraints & Design-Entscheidungen

| Thema | Entscheidung | Grund |
|---|---|---|
| Kein Mutex in `loop()` für screensaverFiles | Bewusst | Ruckelfreie GIF-Wiedergabe + UDP-Throughput |
| `icons_small` nicht beim Boot laden | Bewusst | 38 Dateien × ~200 ms = 8 s Boot-Overhead, aktuell nicht genutzt |
| `delay()` in SD-Scan vermeiden | Pflicht | SPI-Kontextverlust bei `vTaskDelay()` → Scan-Hänger |
| Arduino `String +=` in Schleifen | Verboten | Heap-Fragmentierung → OOM-Crashes bei 1000+ Dateien |
| `#define` in `.cpp` für Bibliotheks-Konfiguration | Funktioniert nicht | Immer `build_flags` in `platformio.ini` nutzen |
| SD-Scan alle 50 Dateien `esp_task_wdt_reset()` | Pflicht | WDT-Budget bei großen Sammlungen |
| `f.name()` vor `f.close()` via `strncpy` kopieren | Pflicht | SdFat2-internen Puffer invalidiert `f.close()` — `const char*` danach ungültig (Bug: 1958 Dateien → nur 805 gespeichert) |

---

## API-Referenz (Web-Endpoints)

### Diagnose

| Endpoint | Methode | Beschreibung |
|---|---|---|
| `/diag` | GET | Boot-Zähler, Reset-Grund, Crash-Slots (JSON) |
| `/crashlog?n=0` | GET | Crash-Log Slot 0–9 |
| `/coredump` | GET | Roher ELF-Coredump (128 KB) |
| `/debug_info` | GET | IP, SSID, Heap, PSRAM, Uptime |
| `/log` | GET | Letzter In-Memory-Ringpuffer |
| `/fs_info` | GET | LittleFS-Speicherinfo (JSON) |
| `/sd_info` | GET | SD-Karten-Info (JSON) |

### Wartung

| Endpoint | Methode | Beschreibung |
|---|---|---|
| `/reset_diag` | POST | Diagnose-Zähler zurücksetzen |
| `/delete_crashlogs` | POST | Alle Crash-Logs löschen |
| `/restart` | POST | Gerät neu starten |
| `/reset_wifi` | POST | WLAN löschen → Access Point |
| `/eject_sd` | POST | SD sicher auswerfen |
| `/mount_sd` | POST | SD neu einbinden |

### Konfiguration

| Endpoint | Methode | Beschreibung |
|---|---|---|
| `/export_config` | GET | Alle Einstellungen als JSON |
| `/import_config` | POST | Einstellungen aus JSON wiederherstellen |
| `/get_version` | GET | Firmware-Version + Git-Hash |
| `/ota` | POST | OTA-Firmware-Update (Binary als Body) |

### Dateiverwaltung

| Endpoint | Methode | Beschreibung |
|---|---|---|
| `/upload_file` | POST | Datei in LittleFS (HTML, Icons, Logo) |
| `/upload_screensaver` | POST | GIF auf SD |
| `/upload_sd` | POST | Beliebige Datei auf SD |
| `/upload_icon` | POST | 20×20 RGBA Icon in LittleFS |
| `/upload_icon_small` | POST | 10×10 RGBA Icon in LittleFS |
| `/upload_icon_radio` | POST | Sender-Icon auf SD |
| `/delete_screensaver?file=` | GET | GIF von SD löschen |
| `/delete_sd_file?file=` | GET | SD-Datei löschen |
| `/sd_files?folder=` | GET | Dateiliste eines SD-Ordners |
| `/sd_folders` | GET | Alle SD-Ordner (aus PSRAM-Cache) |

### Display & Screensaver

| Endpoint | Methode | Beschreibung |
|---|---|---|
| `/screensaver_status` | GET | Aktueller Pfad, Index, Gesamtanzahl |
| `/screensaver_files?offset=0` | GET | Dateiliste paginiert (20/Seite) |
| `/screensaver_folder_count` | GET | Anzahl geladener Dateien |
| `/screensaver_pause` | POST | Anhalten / Fortsetzen |
| `/screensaver_reshuffle` | POST | Zufallsreihenfolge neu mischen |
| `/screensaver_rescan` | POST | Alle Ordner-Caches invalidieren + Neu-Scan erzwingen |
| `/set_screensaver_paths` | POST | Aktive Quellen konfigurieren |
| `/display_text` | POST | Text anzeigen (`text=`, `r=`, `g=`, `b=`, `scroll=`, `duration=`) |
| `/display_text_stop` | POST | Text-Anzeige beenden |
| `/display_timer` | GET | Timer-Status lesen (`enabled`, `from`, `until`, `blank`) |
| `/display_timer` | POST | Timer konfigurieren (`enabled=1`, `from=23:00`, `until=07:00`) |
| `/display_blank` | POST | Display sofort aus/ein (`blank=1` / `blank=0`; ohne Parameter: Toggle) |
| `/play_file` | POST | GIF/RAW direkt abspielen |
| `/gif_preview?file=` | GET | Erstes Frame als PNG |

### GIF-Audio

| Endpoint | Methode | Beschreibung |
|---|---|---|
| `/gif_audio_files` | GET | Dateiliste (JSON aus PSRAM) |
| `/gif_audio_upload` | POST | MP3 in `/GifAudio/` auf SD |
| `/gif_audio_delete` | POST | MP3 löschen |
| `/gif_audio_rescan` | POST | Cache invalidieren + Neu-Scan erzwingen |
| `/cancel_gif_audio_scan` | POST | Laufenden Scan abbrechen |

---

*Letzte Aktualisierung: 2026-07-17*

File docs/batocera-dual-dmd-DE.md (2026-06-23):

# Batocera Dual-DMD Einrichtung — USB + WiFi ZeDMD

> ⚠️ **Experimentell** — getestet mit Batocera **v42**. Vor einem Batocera-Update sorgfältig prüfen.
>
> Diese Anleitung ist ein persönliches Setup-Protokoll. Es funktioniert auf meinem Cabinet — Hardware und Batocera-Version können bei dir abweichen. Keine Garantie, kein Support.

---

## Übersicht

Batoceras eingebauter DMD-Server (`dmd_real`) unterstützt standardmäßig nur ein einzelnes USB-DMD. Diese Anleitung fügt eine **zweite dmdserver-Instanz** hinzu, die gleichzeitig an ein WiFi-ZeDMD (128×32) streamt.

```
USB-DMD   → 256×64 px, Standard-Port   (dmd-play --hd)
WiFi-DMD  → 128×32 px, Port 9001       (dmd-play -p 9001)
```

Beide DMDs zeigen beim Durchblättern das Marquee des gewählten Spiels. Beim Spielstart übernimmt `zedmd_marquee.sh` mit Arcade-typischem Verhalten (Insert Coin, Now Playing usw.).

---

## Benötigte Dateien

**Scripts:**

| Datei | Zweck |
|---|---|
| `postshare.sh` | Boot-Script — startet beide dmdserver + Screensaver |
| `zedmd_marquee.sh` | Marquee-Steuerung (gameStart/gameStop-Hook) |
| `game-selected.sh` | Marquee beim Durchblättern der Spielliste |
| `system-selected.sh` | Marquee beim Durchblättern der Systemliste |

**GIF-Animationen:**

| Datei | Größe | Verwendung |
|---|---|---|
| `screensaver.gif` | beliebig | Bootbild (automatisch skaliert auf beiden DMDs) |
| `insert-coin.gif` | 256×64 | Attract-Modus — USB-DMD |
| `now-playing-128x32.gif` | 128×32 | Spielmodus — WiFi-DMD |
| `press1or2.gif` | 256×64 | Credit-Anzeige — USB-DMD |
| `press1or2_128x32.gif` | 128×32 | Credit-Anzeige — WiFi-DMD (optional) |

**Config:**

| Datei | Zweck |
|---|---|
| `config_real2.ini` | Konfiguration für die zweite dmdserver-Instanz (WiFi-DMD) |

---

## Ordnerstruktur auf Batocera

```
/boot/
└── postshare.sh

/userdata/system/
├── scripts/
│   └── zedmd_marquee.sh
├── services/
│   └── (dmd_real2 existiert nicht — WiFi-dmdserver wird von postshare.sh gestartet)
└── dmd/
    ├── screensaver.gif
    ├── insert_coin/
    │   ├── insert-coin.gif               (256×64)
    │   └── now-playing-128x32.gif        (128×32)
    ├── press1or2.gif                     (256×64)
    ├── press1or2_128x32.gif              (128×32, optional)
    ├── systems/
    │   └── mame.png / snes.png ...
    └── games/
        └── mame/
            ├── dkong.gif                 ← Spielmarquee USB-DMD (256×64)
            └── 128x32/
                └── dkong.gif             ← Spielmarquee WiFi-DMD (128×32)

/userdata/system/configs/emulationstation/scripts/
├── game-selected/
│   └── game-selected.sh
└── system-selected/
    └── system-selected.sh

/userdata/system/configs/dmdserver/
└── config_real2.ini                      ← WiFi-DMD-Server-Config
```

---

## Schritt 1 — Zweiten DMD-Service einrichten (WiFi-DMD)

> ℹ️ **Aktuelle Implementierung:** Das Service-Script `/userdata/system/services/dmd_real2` wird **nicht verwendet**. Der WiFi-dmdserver wird ausschließlich von `postshare.sh` gestartet (Schritt 2). In `batocera.conf` steht `dmd_real2` als aktivierter Service — das ist harmloser Ballast, da kein Script vorhanden ist.
>
> **Warum kein Service-Script?** User-Services starten über `S99userservices` — viel zu spät. `postshare.sh` läuft als `S12` und zeigt damit Inhalte schon während des Bootens. Ein reines Service-Script würde das WiFi-DMD beim Boot stumm lassen.
>
> Der folgende Abschnitt dokumentiert den Service-Script-Ansatz als **Referenz** für ein späteres Neuaufsetzen oder eine Migration auf Batocera >v42.

**Original-Service kopieren:**
```bash
cp /usr/share/batocera/services/dmd_real /userdata/system/services/dmd_real2
```

**`dmd_real2` bearbeiten:**
```bash
nano /userdata/system/services/dmd_real2
```

```sh
#!/bin/sh
PIDFILE=/var/run/dmd_server_real2.pid

start() {
    echo -n "Starting second dmd-server (WiFi): "
    ARGS="-c /userdata/system/configs/dmdserver/config_real2.ini"
    start-stop-daemon -S -b -q -m -p $PIDFILE --exec /usr/bin/dmdserver -- ${ARGS} >/dev/null &
    echo "done"
}

stop() {
    echo -n "Stopping second dmd-server (WiFi): "
    /usr/bin/dmd-play --port 9001 --clear
    start-stop-daemon -K -q -p $PIDFILE
    echo "done"
}

status() {
    start-stop-daemon --status -q -p $PIDFILE && echo "started" || echo "stopped"
}

case "$1" in
    start)  start  ;;
    stop)   stop   ;;
    status) status ;;
esac
```

> ⚠️ Der Port (9001) wird in `config_real2.ini` definiert, **nicht** als Kommandozeilen-Argument.

**Config-Datei erstellen** unter `/userdata/system/configs/dmdserver/config_real2.ini` — Port 9001 und die WiFi-IP des ZeDMD eintragen.

**Service aktivieren:**
Batocera-Menü → System-Einstellungen → Services → `dmd_real2` aktivieren

---

## Schritt 2 — Boot-Script (`postshare.sh`)

Das Boot-Script sorgt dafür, dass beide DMDs direkt beim Start ein Bild anzeigen. Es läuft als `S12` — früh im Boot-Prozess, lange vor `S99` wo die Services starten.

`/boot/postshare.sh`:

```bash
#!/bin/bash
LOGFILE="/userdata/system/dmd.log"
echo "postshare started" >> "$LOGFILE"

# Auf USB-DMD-Gerät warten (ttyACM)
TIMEOUT=10
COUNTER=0
PATTERN="/dev/ttyACM*"
while [ -z "$(ls $PATTERN 2>/dev/null)" ] && [ $COUNTER -lt $TIMEOUT ]; do
  sleep 1; ((COUNTER++))
done

if [ -z "$(ls $PATTERN 2>/dev/null)" ]; then
  echo "Error: no ttyACM device found." >> "$LOGFILE"
  exit 1
fi

DEVICE=$(ls $PATTERN | head -n 1)
echo "Device $DEVICE ready" >> "$LOGFILE"

# USB-DMD-Server starten
pkill dmdserver
sleep 1
/usr/bin/dmdserver &
echo "dmdserver (USB) started" >> "$LOGFILE"
sleep 2

# WiFi-DMD-Server starten (mit PID-Datei — verhindert Doppelstart durch Service)
WLAN_PIDFILE=/var/run/dmd_server_real2.pid
if ! start-stop-daemon --status -q -p $WLAN_PIDFILE 2>/dev/null; then
    start-stop-daemon -S -b -q -m -p $WLAN_PIDFILE \
        --exec /usr/bin/dmdserver -- \
        -c /userdata/system/configs/dmdserver/config_real2.ini >/dev/null
    echo "dmdserver (WiFi) started" >> "$LOGFILE"
    sleep 2
else
    echo "dmdserver (WiFi) already running" >> "$LOGFILE"
fi

# Screensaver auf beiden DMDs
nohup /usr/bin/dmd-play --hd -f /userdata/system/dmd/screensaver.gif >/dev/null 2>&1 &
echo "bootlogo USB sent" >> "$LOGFILE"

nohup /usr/bin/dmd-play -p 9001 -f /userdata/system/dmd/screensaver.gif >/dev/null 2>&1 &
echo "bootlogo WiFi sent" >> "$LOGFILE"
```

```bash
chmod +x /boot/postshare.sh
```

> Der WiFi-dmdserver wird hier mit der **gleichen PID-Datei** wie der `dmd_real2`-Service gestartet. Wenn `S99userservices` später versucht `dmd_real2` zu starten, findet `start-stop-daemon` die vorhandene PID-Datei und überspringt den Start — verhindert eine doppelte Instanz.

---

## Schritt 3 — Marquee-Scripts

### `game-selected.sh` — beim Durchblättern der Spielliste

Pfad: `/userdata/system/configs/emulationstation/scripts/game-selected/game-selected.sh`

Sucht ein Marquee in dieser Reihenfolge:
1. `/userdata/system/dmd/games/<system>/<rom>.gif/png` (exakter Name)
2. `/userdata/system/dmd/games/<system>/<rommin>.gif/png` (vereinfachter Name)
3. Batocera-API (gescraptes Marquee)
4. Spielname als Text
5. Leeren (blank)

Für das WiFi-DMD wird zusätzlich nach einer optimierten 128×32-Version im Unterordner `128x32/` gesucht.

> ⚠️ Wenn `/tmp/zedmd_mode` existiert (Spiel läuft), lässt `game-selected.sh` das WiFi-DMD in Ruhe — `zedmd_marquee.sh` hat die Kontrolle.

### `system-selected.sh` — beim Durchblättern der Systemliste

Pfad: `/userdata/system/configs/emulationstation/scripts/system-selected/system-selected.sh`

Sucht nach:
1. `/userdata/system/dmd/systems/<system>.gif/png`
2. Batocera-API (System-Logo)
3. Leeren (blank)

---

## Schritt 4 — Marquee-Steuerung (`zedmd_marquee.sh`)

Pfad: `/userdata/system/scripts/zedmd_marquee.sh`
```bash
chmod +x /userdata/system/scripts/zedmd_marquee.sh
```

> ℹ️ **Wie wird das Script aufgerufen?** Nicht über ES-Hooks (`game-start` / `game-end`), sondern durch Batoceras **`emulatorlauncher`** — dieser ruft beim Spielstart und -ende automatisch alle ausführbaren Scripts in `/userdata/system/scripts/` auf:
>
> ```
> Spielstart:  zedmd_marquee.sh gameStart <system> <systemname> <emulator> <rompath>
> Spielende:   zedmd_marquee.sh gameStop
> ```
>
> Beispiel MAME: `zedmd_marquee.sh gameStart mame mame mame /userdata/roms/mame/1942.zip`
>
> Im Script relevant: `$1` = Aktion, `$2` = System, `$5` = ROM-Pfad. Das Script läuft als Hintergrundprozess und überwacht per `evtest` die Joystick-Eingaben bis zum Spielende.

**Marquee-Suchreihenfolge — USB-DMD:**
1. `/userdata/system/dmd/games/<system>/<rom>.gif/png`
2. `/userdata/roms/<system>/images/<rom>-marquee.png`
3. `/userdata/roms/<system>/images/<rom>.png`
4. `/userdata/system/dmd/systems/<system>.png`

**Marquee-Suchreihenfolge — WiFi-DMD (128×32):**
1. `/userdata/system/dmd/games/<system>/128x32/<rom>.gif/png` ← bevorzugt
2. `/userdata/system/dmd/games/<system>/<rom>.gif/png`
3. Fallback: gleiches Bild wie USB-DMD (automatisch skaliert)

---

## Anzeigemodi

### ATTRACT-Modus *(Spiel gestartet, noch kein Credit)*
| DMD | Anzeige |
|-----|---|
| USB-DMD | wechselt alle 4s: Spielmarquee ↔ `insert-coin.gif` |
| WiFi-DMD | zeigt: Spielmarquee (128×32 wenn verfügbar) |

### CREDIT-Modus *(Münze eingeworfen)*
| DMD | Anzeige |
|-----|---|
| USB-DMD | `press1or2.gif` |
| WiFi-DMD | `press1or2_128x32.gif` (Fallback: `press1or2.gif`) |

Vorheriger Zustand (ATTRACT/PLAYING) wird gespeichert und nach dem Credit wiederhergestellt.

### PLAYING-Modus *(Start gedrückt, Credit vorhanden)*
| DMD | Anzeige |
|-----|---|
| USB-DMD | Spielmarquee (statisch) |
| WiFi-DMD | wechselt alle 4s: `now-playing-128x32.gif` ↔ Spielmarquee |

---

## Zustandsautomat

```
ATTRACT ──[Münze]──► CREDIT ──[Start, Credits > 0]──► PLAYING
   ▲                   │                                  │
   └──[Start,          │                                  │
   Credits=0,          │ [Start, Credits=0,               │
   war ATTRACT]        │  war ATTRACT]                    │
                       └──────────────────────────────────┘

PLAYING ──[Münze]──► CREDIT ──[Start, Credits > 0]──► PLAYING
                       │
                       │ [Start, Credits=0, war PLAYING]
                       └──────────────────────────────► PLAYING
```

`/tmp/zedmd_prev_mode` speichert den Zustand vor dem Wechsel in CREDIT.

---

## Controller-Belegung

| Taste | Aktion |
|---|---|
| `BTN_BASE3` | Münze einwerfen (Credit +1) |
| `BTN_BASE4` / `BTN_START` | Spiel starten (Credit −1 → PLAYING); kein Credit → zurück zu ATTRACT oder PLAYING |

---

## Temporäre Laufzeit-Dateien

| Datei | Zweck |
|---|---|
| `/tmp/zedmd_lock` | Verhindert mehrere Script-Instanzen |
| `/tmp/zedmd_mode` | Aktueller Zustand (ATTRACT / CREDIT / PLAYING) |
| `/tmp/zedmd_prev_mode` | Zustand vor dem letzten CREDIT |
| `/tmp/zedmd_path` | Marquee-Pfad — USB-DMD |
| `/tmp/zedmd_path_128` | Marquee-Pfad — WiFi-DMD (128×32) |
| `/tmp/zedmd_credit_log` | Credits (eine Zeile = 1 Credit) |

Alle Dateien werden beim Spielende automatisch gelöscht.

---

## Abhängigkeiten

| Tool | Zweck |
|---|---|
| `dmd-play` | DMD-Wiedergabe-Tool |
| `dmdserver` | DMD-Server (läuft zweimal: USB + WiFi) |
| `evtest` | Joystick-Event-Auslesen |
| `udevadm` | Geräteerkennung |
| `nc` | Port-Check (netcat) |
| `wget` + `jq` | Batocera-API-Abfragen (Marquee-Pfade) |

---

## Fehlerbehebung

### Doppelte WiFi-dmdserver-Instanz
**Ursache:** `postshare.sh` und `dmd_real2`-Service versuchen beide den Server zu starten.
**Lösung:** `postshare.sh` nutzt die gleiche PID-Datei wie der Service → zweiter Start wird automatisch übersprungen.

### gameStop räumt `/tmp/zedmd_*` nicht auf
**Ursache:** `pkill -9 -f zedmd_marquee.sh` hat das Script beendet bevor `rm` laufen konnte.
**Lösung:** Immer erst aufräumen, dann beenden — oder `/tmp/zedmd_lock` nutzen um Mehrfachstarts zu verhindern.

### Mehrere Script-Instanzen laufen gleichzeitig
**Ursache:** Batocera ruft Scripts mehrfach auf (z.B. bei ROM-Varianten).
**Lösung:** Lock-Mechanismus über `/tmp/zedmd_lock`.

### WiFi-DMD zeigt falsches Bild während das Spiel läuft
**Ursache:** `game-selected.sh` und `zedmd_marquee.sh` senden gleichzeitig.
**Lösung:** `game-selected.sh` prüft `/tmp/zedmd_mode` → überspringt WiFi-DMD wenn Spiel läuft.

### Kein Marquee für Spiele ohne eigene DMD-Datei
**Lösung:** `find_marquee_path()` durchsucht auch Batoceras Standard-Medienpfade:
`/userdata/roms/<system>/images/<rom>-marquee.png`

### WiFi-DMD friert ein (GIF endet, kein Loop)
**Ursache:** `--once`-Flag in `dmd-play` → GIF wird nur einmal abgespielt.
**Lösung:** `--once` entfernen → GIF läuft in Dauerschleife.

---

## Logging

```bash
# Boot-Log
cat /userdata/system/dmd.log

# Laufende Prozesse
ps aux | grep dmdserver | grep -v grep
ps aux | grep dmd-play  | grep -v grep
ps aux | grep zedmd     | grep -v grep

# Beide dmdserver-Instanzen unterscheiden sich nur am Argument:
#   /usr/bin/dmdserver                            ← USB-DMD  (Port 6789, dmd_real Service)
#   /usr/bin/dmdserver -c .../config_real2.ini    ← WiFi-DMD (Port 9001, postshare.sh)
#
# Nur die WiFi-Instanz prüfen:
pgrep -a -f config_real2.ini

# Aktueller Zustand
cat /tmp/zedmd_mode
cat /tmp/zedmd_path
cat /tmp/zedmd_credit_log

# Port 9001 prüfen
nc -z localhost 9001 && echo "OK" || echo "ERROR"

# WiFi-DMD manuell testen
dmd-play -p 9001 -f /userdata/system/dmd/screensaver.gif

# Temporäre Dateien zurücksetzen
rm -f /tmp/zedmd_*
```

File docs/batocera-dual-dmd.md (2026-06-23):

# Batocera Dual-DMD Setup — USB + WiFi ZeDMD

> ⚠️ **Experimental** — tested with Batocera **v42**. Verify carefully before updating Batocera.
>
> This guide is a personal setup diary. It worked on my cabinet — your hardware and Batocera version may differ. No warranty, no support.

---

## Overview

Batocera's built-in DMD server (`dmd_real`) supports only a single USB-connected DMD out of the box. This guide adds a **second DMD server instance** that streams to a WiFi ZeDMD (128×32) in parallel.

```
USB-DMD   → 256×64 px, default port   (dmd-play --hd)
WiFi-DMD  → 128×32 px, port 9001      (dmd-play -p 9001)
```

Both DMDs show the selected game's marquee while browsing. On game start, `zedmd_marquee.sh` takes over with arcade-style behaviour (Insert Coin, Now Playing, etc.).

---

## Required Files

**Scripts:**

| File | Purpose |
|---|---|
| `postshare.sh` | Boot script — starts both DMD servers + screensaver |
| `zedmd_marquee.sh` | Marquee controller (gameStart/gameStop hook) |
| `game-selected.sh` | Marquee when scrolling the game list |
| `system-selected.sh` | Marquee when scrolling the system list |

**GIF animations:**

| File | Size | Usage |
|---|---|---|
| `screensaver.gif` | any | Boot screen (auto-scaled on both DMDs) |
| `insert-coin.gif` | 256×64 | Attract mode — USB-DMD |
| `now-playing-128x32.gif` | 128×32 | Playing mode — WiFi-DMD |
| `press1or2.gif` | 256×64 | Credit display — USB-DMD |
| `press1or2_128x32.gif` | 128×32 | Credit display — WiFi-DMD (optional) |

**Config:**

| File | Purpose |
|---|---|
| `config_real2.ini` | Config for the second DMD server (WiFi-DMD) |

---

## Folder Structure on Batocera

```
/boot/
└── postshare.sh

/userdata/system/
├── scripts/
│   └── zedmd_marquee.sh
├── services/
│   └── (dmd_real2 does not exist — WiFi dmdserver is started by postshare.sh)
└── dmd/
    ├── screensaver.gif
    ├── insert_coin/
    │   ├── insert-coin.gif               (256×64)
    │   └── now-playing-128x32.gif        (128×32)
    ├── press1or2.gif                     (256×64)
    ├── press1or2_128x32.gif              (128×32, optional)
    ├── systems/
    │   └── mame.png / snes.png ...
    └── games/
        └── mame/
            ├── dkong.gif                 ← game marquee USB-DMD (256×64)
            └── 128x32/
                └── dkong.gif             ← game marquee WiFi-DMD (128×32)

/userdata/system/configs/emulationstation/scripts/
├── game-selected/
│   └── game-selected.sh
└── system-selected/
    └── system-selected.sh

/userdata/system/configs/dmdserver/
└── config_real2.ini                      ← WiFi DMD server config
```

---

## Step 1 — Set Up the Second DMD Service (WiFi-DMD)

> ℹ️ **Actual implementation:** The service script `/userdata/system/services/dmd_real2` is **not used** in the current setup. The WiFi dmdserver is started exclusively by `postshare.sh` (Step 2). The entry `dmd_real2` in `batocera.conf` as an enabled service is harmless leftover — since no script file exists, nothing happens at boot.
>
> **Why no service script?** User services start via `S99userservices` — far too late in the boot process. `postshare.sh` runs as `S12` and therefore displays content during the very early boot phase. A pure service-script approach would leave the WiFi-DMD blank until EmulationStation is nearly ready.
>
> The section below documents the service-script approach as a **reference** for a future reinstall or migration to Batocera >v42.

**Copy the original service:**
```bash
cp /usr/share/batocera/services/dmd_real /userdata/system/services/dmd_real2
```

**Edit `dmd_real2`:**
```bash
nano /userdata/system/services/dmd_real2
```

```sh
#!/bin/sh
PIDFILE=/var/run/dmd_server_real2.pid

start() {
    echo -n "Starting second dmd-server (WiFi): "
    ARGS="-c /userdata/system/configs/dmdserver/config_real2.ini"
    start-stop-daemon -S -b -q -m -p $PIDFILE --exec /usr/bin/dmdserver -- ${ARGS} >/dev/null &
    echo "done"
}

stop() {
    echo -n "Stopping second dmd-server (WiFi): "
    /usr/bin/dmd-play --port 9001 --clear
    start-stop-daemon -K -q -p $PIDFILE
    echo "done"
}

status() {
    start-stop-daemon --status -q -p $PIDFILE && echo "started" || echo "stopped"
}

case "$1" in
    start)  start  ;;
    stop)   stop   ;;
    status) status ;;
esac
```

> ⚠️ The port (9001) is defined in `config_real2.ini`, **not** as a command-line argument.

**Create the config file** at `/userdata/system/configs/dmdserver/config_real2.ini` — enter port 9001 and your ZeDMD's WiFi IP address.

**Enable the service:**
Batocera menu → System Settings → Services → enable `dmd_real2`

---

## Step 2 — Boot Script (`postshare.sh`)

The boot script ensures both DMDs show an image right from startup. It runs as `S12` — early in the boot process, long before `S99` where services start.

`/boot/postshare.sh`:

```bash
#!/bin/bash
LOGFILE="/userdata/system/dmd.log"
echo "postshare started" >> "$LOGFILE"

# Wait for USB-DMD device (ttyACM)
TIMEOUT=10
COUNTER=0
PATTERN="/dev/ttyACM*"
while [ -z "$(ls $PATTERN 2>/dev/null)" ] && [ $COUNTER -lt $TIMEOUT ]; do
  sleep 1; ((COUNTER++))
done

if [ -z "$(ls $PATTERN 2>/dev/null)" ]; then
  echo "Error: no ttyACM device found." >> "$LOGFILE"
  exit 1
fi

DEVICE=$(ls $PATTERN | head -n 1)
echo "Device $DEVICE ready" >> "$LOGFILE"

# Start USB-DMD server
pkill dmdserver
sleep 1
/usr/bin/dmdserver &
echo "dmdserver (USB) started" >> "$LOGFILE"
sleep 2

# Start WiFi-DMD server (with PID file — prevents double-start by service)
WLAN_PIDFILE=/var/run/dmd_server_real2.pid
if ! start-stop-daemon --status -q -p $WLAN_PIDFILE 2>/dev/null; then
    start-stop-daemon -S -b -q -m -p $WLAN_PIDFILE \
        --exec /usr/bin/dmdserver -- \
        -c /userdata/system/configs/dmdserver/config_real2.ini >/dev/null
    echo "dmdserver (WiFi) started" >> "$LOGFILE"
    sleep 2
else
    echo "dmdserver (WiFi) already running" >> "$LOGFILE"
fi

# Screensaver on both DMDs
nohup /usr/bin/dmd-play --hd -f /userdata/system/dmd/screensaver.gif >/dev/null 2>&1 &
echo "bootlogo USB sent" >> "$LOGFILE"

nohup /usr/bin/dmd-play -p 9001 -f /userdata/system/dmd/screensaver.gif >/dev/null 2>&1 &
echo "bootlogo WiFi sent" >> "$LOGFILE"
```

```bash
chmod +x /boot/postshare.sh
```

> The WiFi dmdserver is started here using the **same PID file** as the `dmd_real2` service. When `S99userservices` later tries to start `dmd_real2`, `start-stop-daemon` finds the existing PID file and skips the start — preventing a duplicate instance.

---

## Step 3 — Marquee Scripts

### `game-selected.sh` — while scrolling the game list

Path: `/userdata/system/configs/emulationstation/scripts/game-selected/game-selected.sh`

Searches for a marquee in this order:
1. `/userdata/system/dmd/games/<system>/<rom>.gif/png` (exact name)
2. `/userdata/system/dmd/games/<system>/<rommin>.gif/png` (simplified name)
3. Batocera API (scraped marquee)
4. Game name as text
5. Clear (blank)

For the WiFi-DMD, it additionally checks for an optimised 128×32 version in the `128x32/` subfolder.

> ⚠️ If `/tmp/zedmd_mode` exists (game is running), `game-selected.sh` leaves the WiFi-DMD alone — `zedmd_marquee.sh` is in control.

### `system-selected.sh` — while scrolling the system list

Path: `/userdata/system/configs/emulationstation/scripts/system-selected/system-selected.sh`

Searches for:
1. `/userdata/system/dmd/systems/<system>.gif/png`
2. Batocera API (system logo)
3. Clear (blank)

---

## Step 4 — Marquee Controller (`zedmd_marquee.sh`)

Path: `/userdata/system/scripts/zedmd_marquee.sh`
```bash
chmod +x /userdata/system/scripts/zedmd_marquee.sh
```

> ℹ️ **How is the script called?** Not via ES hooks (`game-start` / `game-end`), but by Batocera's **`emulatorlauncher`** — which automatically calls all executable scripts in `/userdata/system/scripts/` on game start and end:
>
> ```
> Game start:  zedmd_marquee.sh gameStart <system> <systemname> <emulator> <rompath>
> Game end:    zedmd_marquee.sh gameStop
> ```
>
> Example for MAME: `zedmd_marquee.sh gameStart mame mame mame /userdata/roms/mame/1942.zip`
>
> In the script: `$1` = action, `$2` = system, `$5` = ROM path. The script runs as a background daemon and monitors joystick input via `evtest` until the game ends.

**Marquee search order — USB-DMD:**
1. `/userdata/system/dmd/games/<system>/<rom>.gif/png`
2. `/userdata/roms/<system>/images/<rom>-marquee.png`
3. `/userdata/roms/<system>/images/<rom>.png`
4. `/userdata/system/dmd/systems/<system>.png`

**Marquee search order — WiFi-DMD (128×32):**
1. `/userdata/system/dmd/games/<system>/128x32/<rom>.gif/png` ← preferred
2. `/userdata/system/dmd/games/<system>/<rom>.gif/png`
3. Fallback: same image as USB-DMD (auto-scaled)

---

## Display Modes

### ATTRACT mode *(game started, no credit yet)*
| DMD | Display |
|-----|---|
| USB-DMD | alternates every 4s: game marquee ↔ `insert-coin.gif` |
| WiFi-DMD | shows: game marquee (128×32 if available) |

### CREDIT mode *(coin inserted)*
| DMD | Display |
|-----|---|
| USB-DMD | `press1or2.gif` |
| WiFi-DMD | `press1or2_128x32.gif` (fallback: `press1or2.gif`) |

Previous state (ATTRACT/PLAYING) is saved and restored after credit.

### PLAYING mode *(start pressed, credit available)*
| DMD | Display |
|-----|---|
| USB-DMD | game marquee (static) |
| WiFi-DMD | alternates every 4s: `now-playing-128x32.gif` ↔ game marquee |

---

## State Machine

```
ATTRACT ──[Coin]──► CREDIT ──[Start, Credits > 0]──► PLAYING
   ▲                  │                                  │
   └──[Start,         │                                  │
   Credits=0,         │ [Start, Credits=0,               │
   was ATTRACT]       │  was ATTRACT]                    │
                      └──────────────────────────────────┘

PLAYING ──[Coin]──► CREDIT ──[Start, Credits > 0]──► PLAYING
                      │
                      │ [Start, Credits=0, was PLAYING]
                      └──────────────────────────────► PLAYING
```

`/tmp/zedmd_prev_mode` stores the state before entering CREDIT.

---

## Controller Mapping

| Button | Action |
|---|---|
| `BTN_BASE3` | Insert coin (Credit +1) |
| `BTN_BASE4` / `BTN_START` | Start game (Credit −1 → PLAYING); no credit → back to ATTRACT or PLAYING |

---

## Runtime Temp Files

| File | Purpose |
|---|---|
| `/tmp/zedmd_lock` | Prevents multiple script instances |
| `/tmp/zedmd_mode` | Current state (ATTRACT / CREDIT / PLAYING) |
| `/tmp/zedmd_prev_mode` | State before last CREDIT |
| `/tmp/zedmd_path` | Marquee path — USB-DMD |
| `/tmp/zedmd_path_128` | Marquee path — WiFi-DMD (128×32) |
| `/tmp/zedmd_credit_log` | Credits (one line = 1 credit) |

All files are automatically deleted on gameStop.

---

## Dependencies

| Tool | Purpose |
|---|---|
| `dmd-play` | DMD playback tool |
| `dmdserver` | DMD server (runs twice: USB + WiFi) |
| `evtest` | Joystick event reading |
| `udevadm` | Device detection |
| `nc` | Port check (netcat) |
| `wget` + `jq` | Batocera API queries (marquee paths) |

---

## Troubleshooting

### Duplicate WiFi dmdserver instance
**Cause:** `postshare.sh` and `dmd_real2` service both try to start the server.
**Fix:** `postshare.sh` uses the same PID file as the service → second start is skipped automatically.

### gameStop doesn't clean up `/tmp/zedmd_*`
**Cause:** `pkill -9 -f zedmd_marquee.sh` killed the script before `rm` could run.
**Fix:** Always clean up first, then kill — or use `/tmp/zedmd_lock` to prevent multiple starts.

### Multiple script instances running simultaneously
**Cause:** Batocera calls scripts multiple times (e.g. ROM variants).
**Fix:** Lock mechanism via `/tmp/zedmd_lock`.

### WiFi-DMD shows wrong image while game is running
**Cause:** `game-selected.sh` and `zedmd_marquee.sh` sending simultaneously.
**Fix:** `game-selected.sh` checks `/tmp/zedmd_mode` → skips WiFi-DMD if game is running.

### No marquee for games without a custom DMD file
**Fix:** `find_marquee_path()` also searches Batocera's standard media paths:
`/userdata/roms/<system>/images/<rom>-marquee.png`

### WiFi-DMD freezes (GIF ends, no loop)
**Cause:** `--once` flag in `dmd-play` → GIF plays only once.
**Fix:** Remove `--once` → GIF loops continuously.

---

## Logging

```bash
# Boot log
cat /userdata/system/dmd.log

# Running processes
ps aux | grep dmdserver | grep -v grep
ps aux | grep dmd-play  | grep -v grep
ps aux | grep zedmd     | grep -v grep

# Both dmdserver instances differ only by argument:
#   /usr/bin/dmdserver                            ← USB-DMD  (port 6789, dmd_real service)
#   /usr/bin/dmdserver -c .../config_real2.ini    ← WiFi-DMD (port 9001, postshare.sh)
#
# Check only the WiFi instance:
pgrep -a -f config_real2.ini

# Current state
cat /tmp/zedmd_mode
cat /tmp/zedmd_path
cat /tmp/zedmd_credit_log

# Check port 9001
nc -z localhost 9001 && echo "OK" || echo "ERROR"

# Manual WiFi-DMD test
dmd-play -p 9001 -f /userdata/system/dmd/screensaver.gif

# Reset temp files
rm -f /tmp/zedmd_*
```

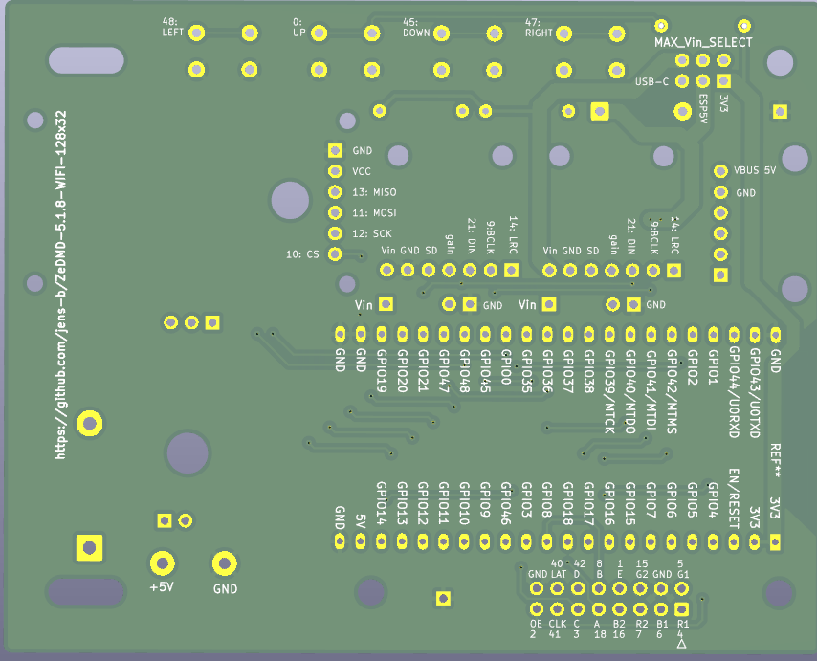
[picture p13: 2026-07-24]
KiCad/ZeDMD_WiFi/docs/ZeDMD_WiFi_PCB_bottom.png

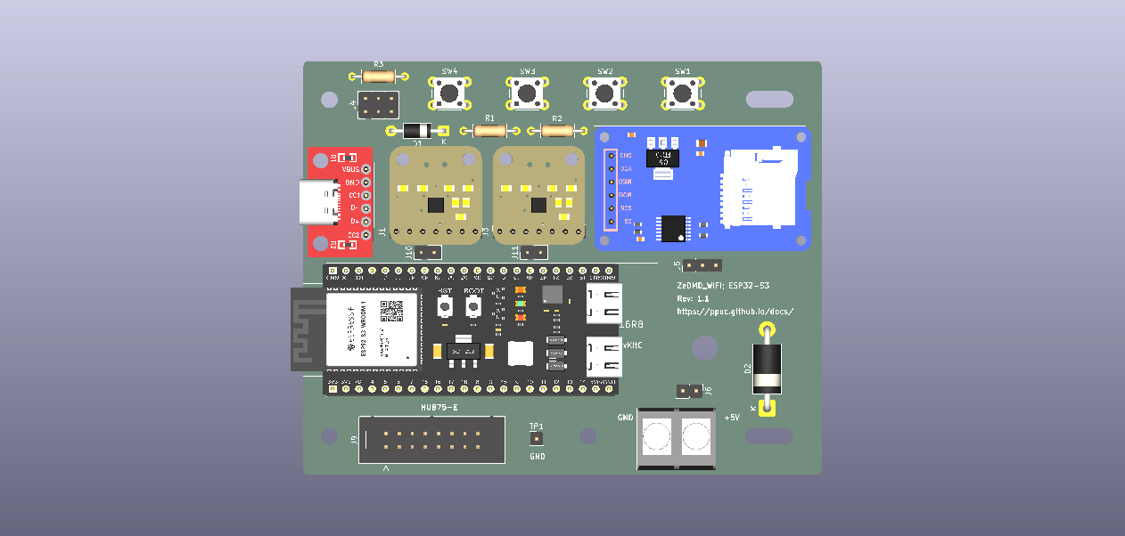
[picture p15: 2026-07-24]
KiCad/ZeDMD_WiFi/docs/ZeDMD_WiFi_3d_top.png

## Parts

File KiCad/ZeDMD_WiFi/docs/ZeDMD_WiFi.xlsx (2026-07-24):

Reference | Qty | Value | DNP | Footprint | Beschrijving | LCSC
D1 | 1 | 1N5819 |  | Diode_THT:D_DO-41_SOD81_P10.16mm_Horizontal | 40V 1A Schottky Barrier Rectifier Diode, DO-41
D2 | 1 | 1N5822 |  | Diode_THT:D_DO-201AD_P15.24mm_Horizontal | 40V 3A Schottky Barrier Rectifier Diode, DO-201AD
J1 | 1 | max98357-L |  | Connector_PinSocket_2.54mm:PinSocket_1x07_P2.54mm_Vertical | Pin socket, single row, 01x07, P=2.54mm
J2 | 1 | MicroSD |  | Connector_PinSocket_2.54mm:PinSocket_1x06_P2.54mm_Vertical | Pin socket, single row, 01x06, P=2.54mm
J3 | 1 | max98357-R |  | Connector_PinSocket_2.54mm:PinSocket_1x07_P2.54mm_Vertical | Pin socket, single row, 01x07, P=2.54mm
J4 | 1 | MAX_Vin_SELECT |  | Connector_PinHeader_2.54mm:PinHeader_2x03_P2.54mm_Vertical | Pin header, P=2.54mm, double row, 02x03, odd/even pin numbering scheme (row 1 odd numbers, row 2 even numbers)
J5 | 1 | RGBout_SELECT |  | Connector_PinHeader_2.54mm:PinHeader_1x03_P2.54mm_Vertical | Pin header, single row, 01x03, P=2.54mm
J6 | 1 | 5Vin_OPTION |  | Connector_PinHeader_2.54mm:PinHeader_1x02_P2.54mm_Vertical | Pin header, single row, 01x02, P=2.54mm
J7 | 1 | KF7.62 Barrier Terminal Block 2P |  | ZeDMD_WiFi:KF7.62_2P | Generic screw terminal, single row, 01x02, script generated (kicad-library-utils/schlib/autogen/connector/)
J8 | 1 | USB-C breakout |  | Connector_PinSocket_2.54mm:PinSocket_1x06_P2.54mm_Vertical | Pin socket, single row, 01x06, P=2.54mm
J9 | 1 | Conn_02x08_Odd_Even |  | Connector_IDC:IDC-Header_2x08_P2.54mm_Vertical | 2x8p IDC Boxed Header, vertical, P=2.54mm
J10,J11 | 2 | Conn_01x02_Pin |  | Connector_PinHeader_2.54mm:PinHeader_1x02_P2.54mm_Vertical | Generic connector, single row, 01x02, script generated
R1 | 1 | 100k |  | Resistor_THT:R_Axial_DIN0207_L6.3mm_D2.5mm_P10.16mm_Horizontal | Resistor
R2 | 1 | 390k |  | Resistor_THT:R_Axial_DIN0207_L6.3mm_D2.5mm_P10.16mm_Horizontal | Resistor
R3 | 1 | 10k |  | Resistor_THT:R_Axial_DIN0207_L6.3mm_D2.5mm_P10.16mm_Horizontal | Resistor
SW1 | 1 | Menu Left |  | Button_Switch_THT:SW_PUSH_6mm | Tactile Pushbutton Switch Momentary 4pin 6*6*6mm
SW2 | 1 | Boot/Value+ |  | Button_Switch_THT:SW_PUSH_6mm | Tactile Pushbutton Switch Momentary 4pin 6*6*6mm
SW3 | 1 | Value- |  | Button_Switch_THT:SW_PUSH_6mm | Tactile Pushbutton Switch Momentary 4pin 6*6*6mm
SW4 | 1 | Menu Right |  | Button_Switch_THT:SW_PUSH_6mm | Tactile Pushbutton Switch Momentary 4pin 6*6*6mm
TP1,TP4 | 2 | GND |  | Connector_PinHeader_2.54mm:PinHeader_1x01_P2.54mm_Vertical | test point
TP2,TP3 | 2 | Vin |  | Connector_PinHeader_2.54mm:PinHeader_1x01_P2.54mm_Vertical | test point
U1 | 1 | ESP32-S3-DevKitC |  | PCM_Espressif:ESP32-S3-DevKitC | 2x Pin Socket, single row, 01x22, P=2.54mm

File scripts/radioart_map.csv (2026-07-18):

# Mapping: DAB+ Service-ID (hex) → Slug (muss zum ICY-Sendernamen passen)
# Slug-Regel: Sendername lowercase | Sonderzeichen → '_' | führende/nachfolgende '_' entfernen
# Fuzzy-Matcher in der Firmware toleriert Abweichungen (Token-Splitting | threshold ≥ 100 Punkte)
#
# Format: hex_id | slug
# Hex-IDs aus DAB+-Ensembles (Quelle: wohnort.org + Radioart-Ordner)
# === NRW / WDR-Ensemble ===
DF95 | wdr_maus
D391 | 1live
DF91 | 1live_diggi
D592 | wdr_2_owl
D792 | wdr_2_rhein_ruhr
D393 | wdr_3
D794 | wdr_4_rhein_ruhr
D395 | wdr_5
DF96 | wdr_event
D496 | wdrcosmo
# === Niedersachsen / NDR ===
D381 | ndr_1_niedersachsen
D881 | ndr_1_nds_bs
D481 | ndr_1_nds_han
D581 | ndr_1_nds_lg
D681 | ndr_1_nds_ol
D781 | ndr_1_nds_os
D382 | ndr_2
D882 | ndr_2_nds
D383 | ndr_kultur
D384 | ndr_info
D884 | ndr_info_nds
DF84 | ndr_info_spezial
D387 | ndr_schlager
D354 | ndr_blue
D385 | n_joy
# Privatradios Niedersachsen
D388 | ffn
D788 | ffn
D389 | antenne_nds
D38A | radio_21
D0DB | 89_0_rtl
1A85 | antenne_schlager
# === Bundesweit — Deutschlandradio ===
D210 | dlf
D220 | dlf_kultur
D230 | dlf_nova
D240 | dradio_dok_deb
# === Bundesweit — DR Deutschland (Block 5C) ===
17FA | absolut_relax
1A45 | energy
1A64 | erf_plus
D75B | klassik_radio
15DD | radio_bob
D01C | radio_horeb
10C3 | schlagerparadies
100D | schwarzwaldradio
15DC | sunshine_live
# === Bundesweit — Antenne Deutschland ===
1057 | 80s80s
12E9 | 90s90s
1219 | absolut_bella
121C | absolut_germany
DC1A | absolut_hot
121A | absolut_oldie
1218 | absolut_top_2000
1259 | aidaradio
12C8 | ballermann_radio
1258 | beats_radio
1299 | brillux_radio
122A | nostalgie
121D | oldie_antenne
121B | rock_antenne
1229 | rtl_radio
1298 | toggo_radio

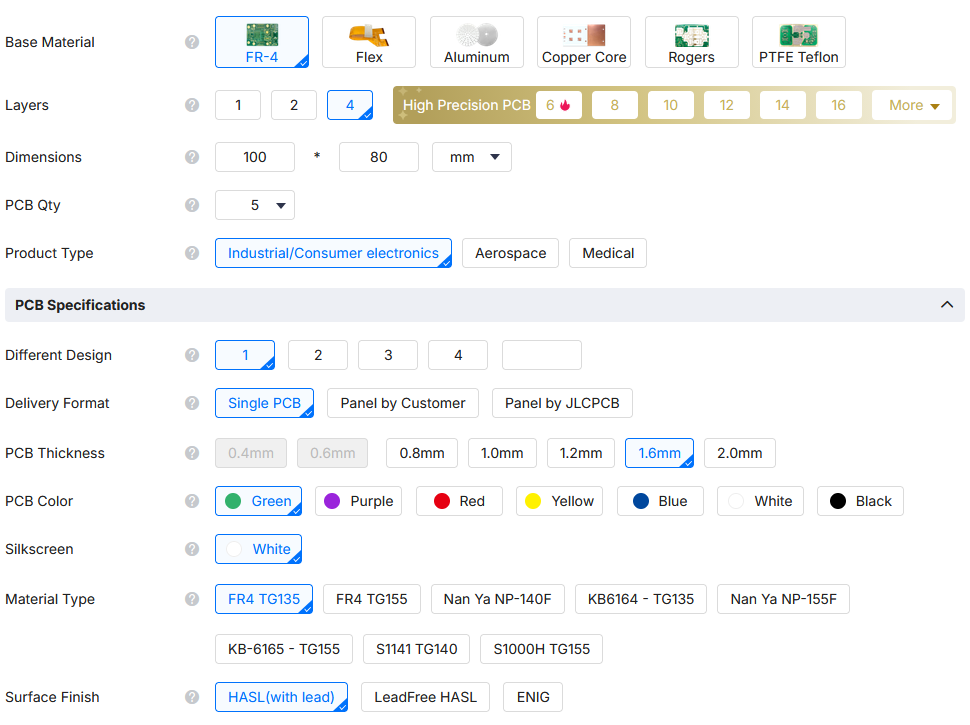
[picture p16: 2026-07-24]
KiCad/ZeDMD_WiFi/docs/ZeDMD_WiFi_JLCPCB_ordering.png

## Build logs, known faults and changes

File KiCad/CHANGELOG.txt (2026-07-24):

2026-06-21  elabree	Rev1.1	Initial Version
2026-07-12  elabree	Rev1.2	Changed spacing between the DevKit pinheader rows from 0.9"to 1"

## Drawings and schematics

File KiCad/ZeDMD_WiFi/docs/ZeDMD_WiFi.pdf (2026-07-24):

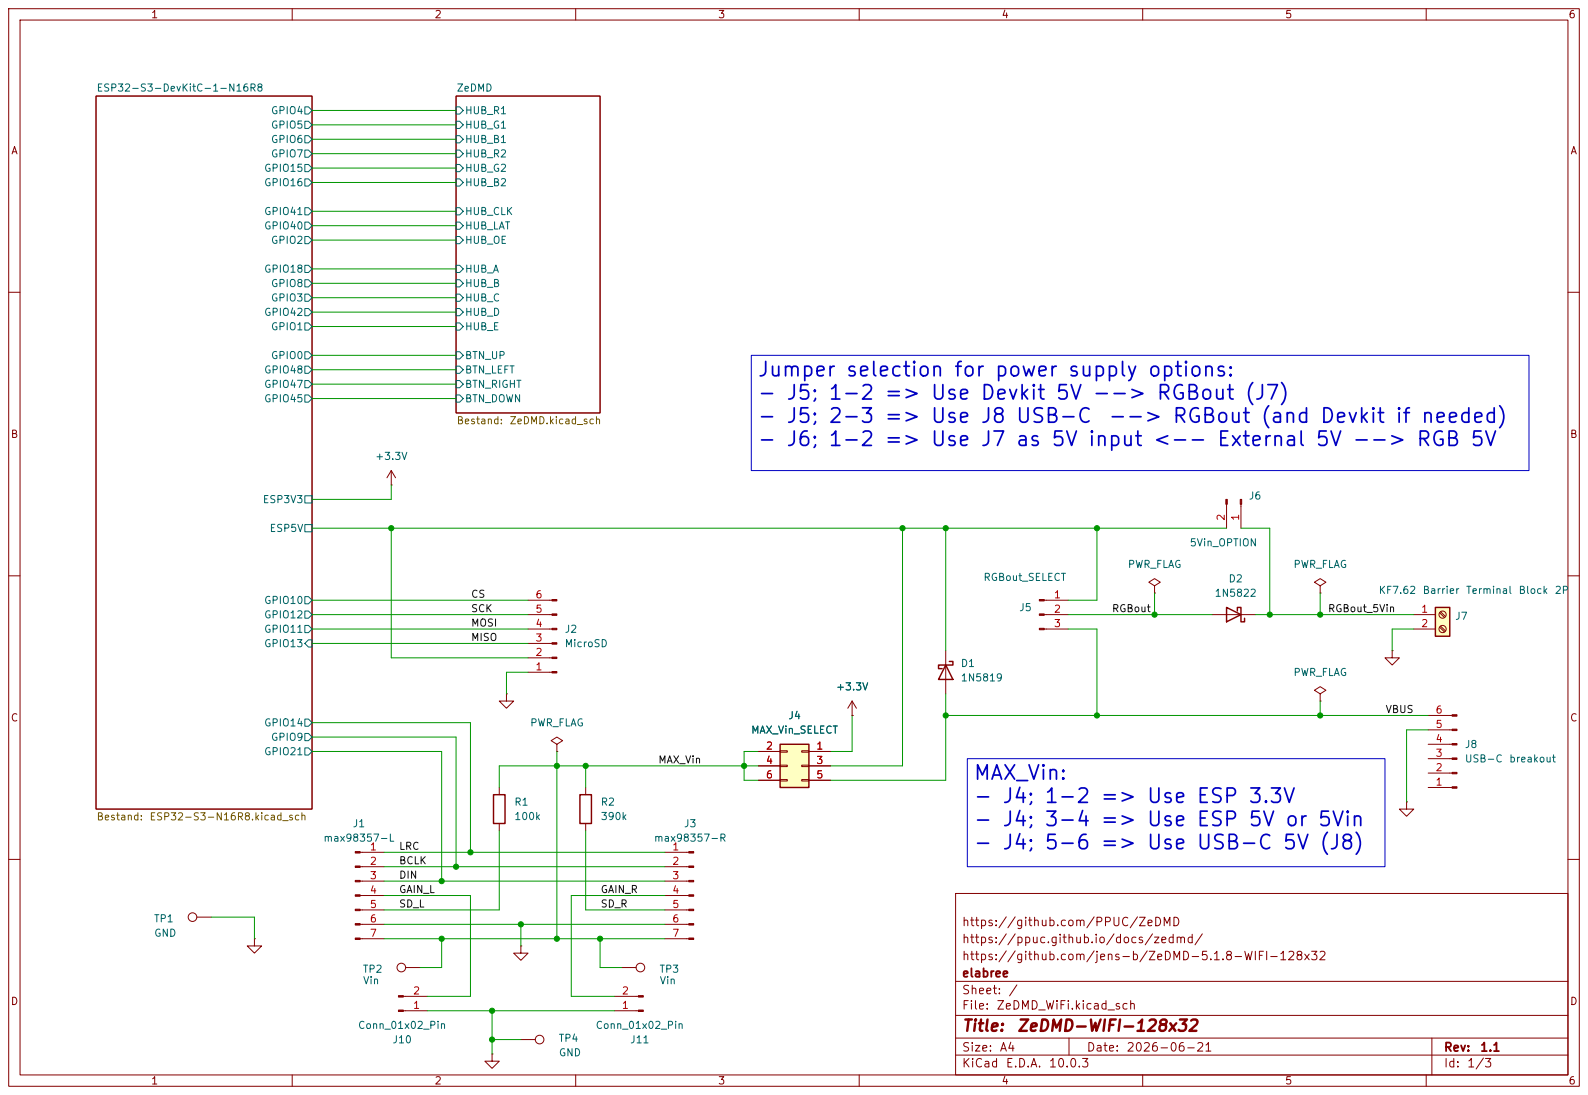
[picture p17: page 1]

Jumper selection for power supply options: - J5; 1-2 => Use Devkit 5V --> RGBout (J7) - J5; 2-3 => Use J8 USB-C --> RGBout (and Devkit if needed) - J6; 1-2 => Use J7 as 5V input <-- External 5V --> RGB 5V

J4 MAX_Vin_SELECT+3.3V

4 4 | | 3 3

https://github.com/PPUC/ZeDMD
https://ppuc.github.io/docs/zedmd/
https://github.com/jens-b/ZeDMD-5.1.8-WIFI-128x32
elabree
Sheet: /
File: ZeDMD_WiFi.kicad_sch
Title: ZeDMD-WIFI-128x32

Size: A4 | Rev: 1.1
KiCad E.D.A. 10.0.3 | Id: 1/3

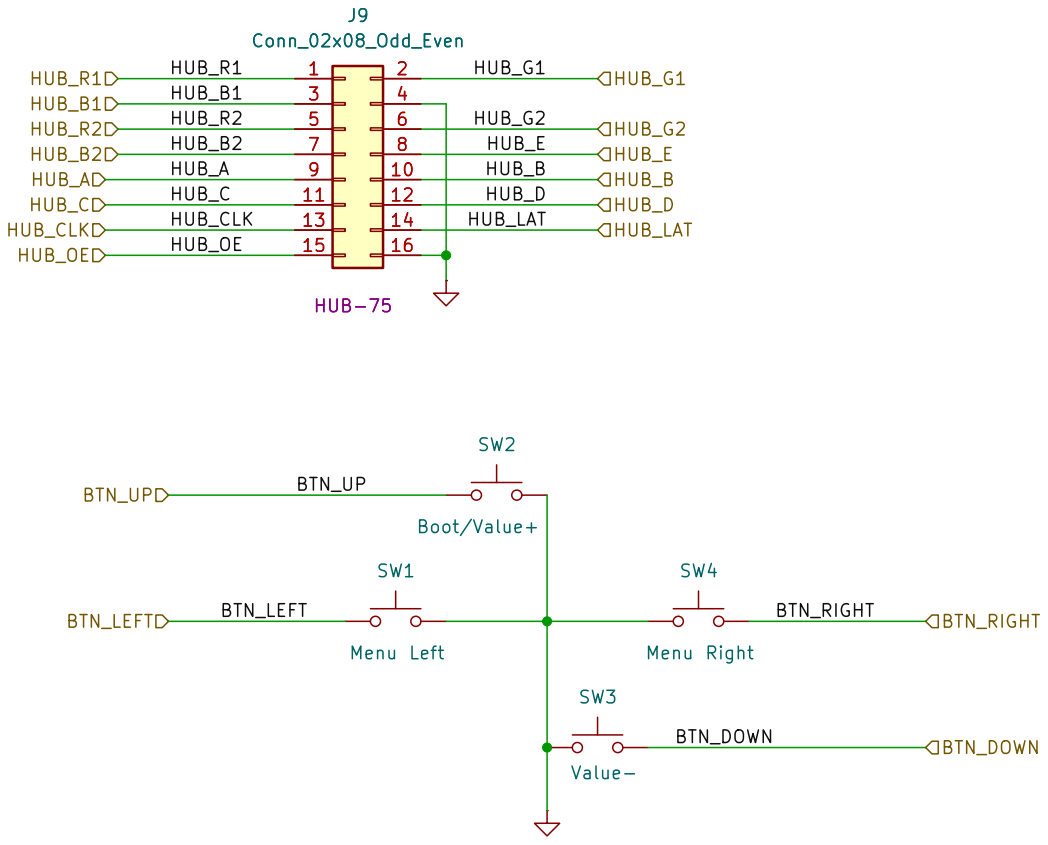
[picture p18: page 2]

https://github.com/PPUC/ZeDMD
https://ppuc.github.io/docs/zedmd/
https://github.com/jens-b/ZeDMD-5.1.8-WIFI-128x32
elabree
Sheet: /ZeDMD/
File: ZeDMD.kicad_sch
Title: HUB75

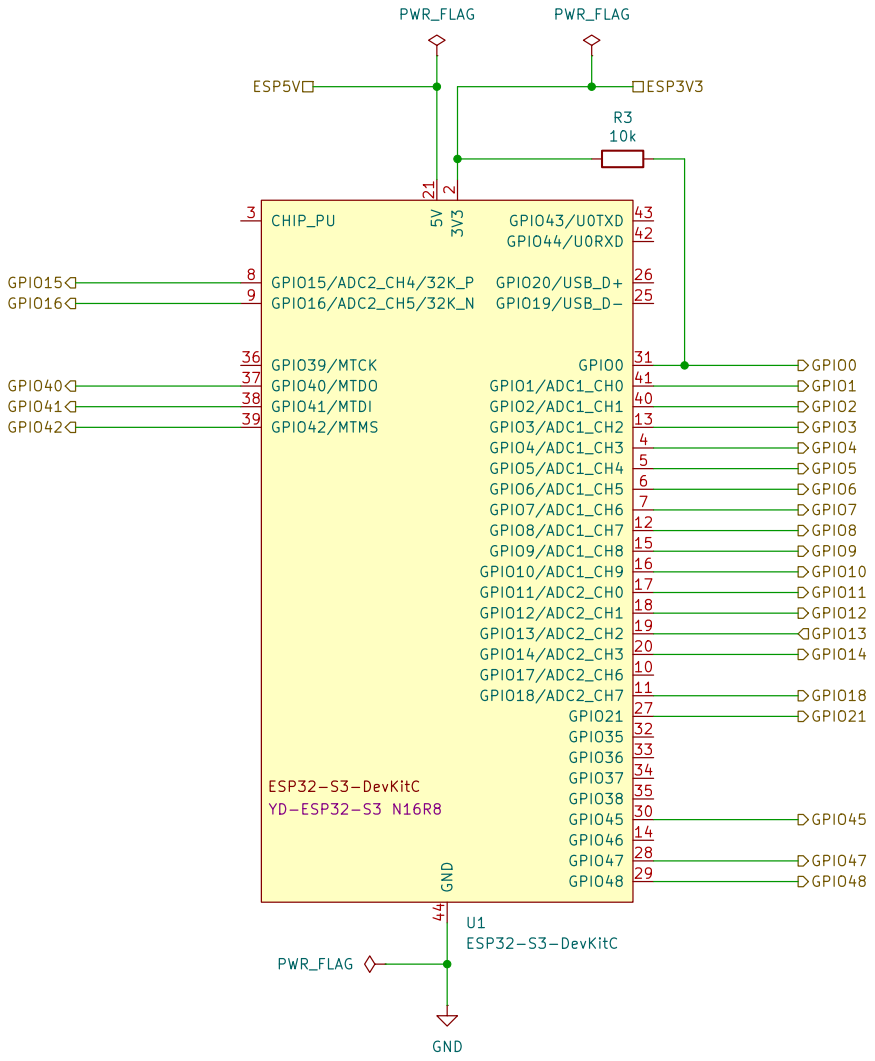
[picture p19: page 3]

https://github.com/PPUC/ZeDMD
https://ppuc.github.io/docs/zedmd/
https://github.com/jens-b/ZeDMD-5.1.8-WIFI-128x32
elabree
Sheet: /ESP32-S3-DevKitC-1-N16R8/
File: ESP32-S3-N16R8.kicad_sch
Title: YD-ESP32-S3 N16R8

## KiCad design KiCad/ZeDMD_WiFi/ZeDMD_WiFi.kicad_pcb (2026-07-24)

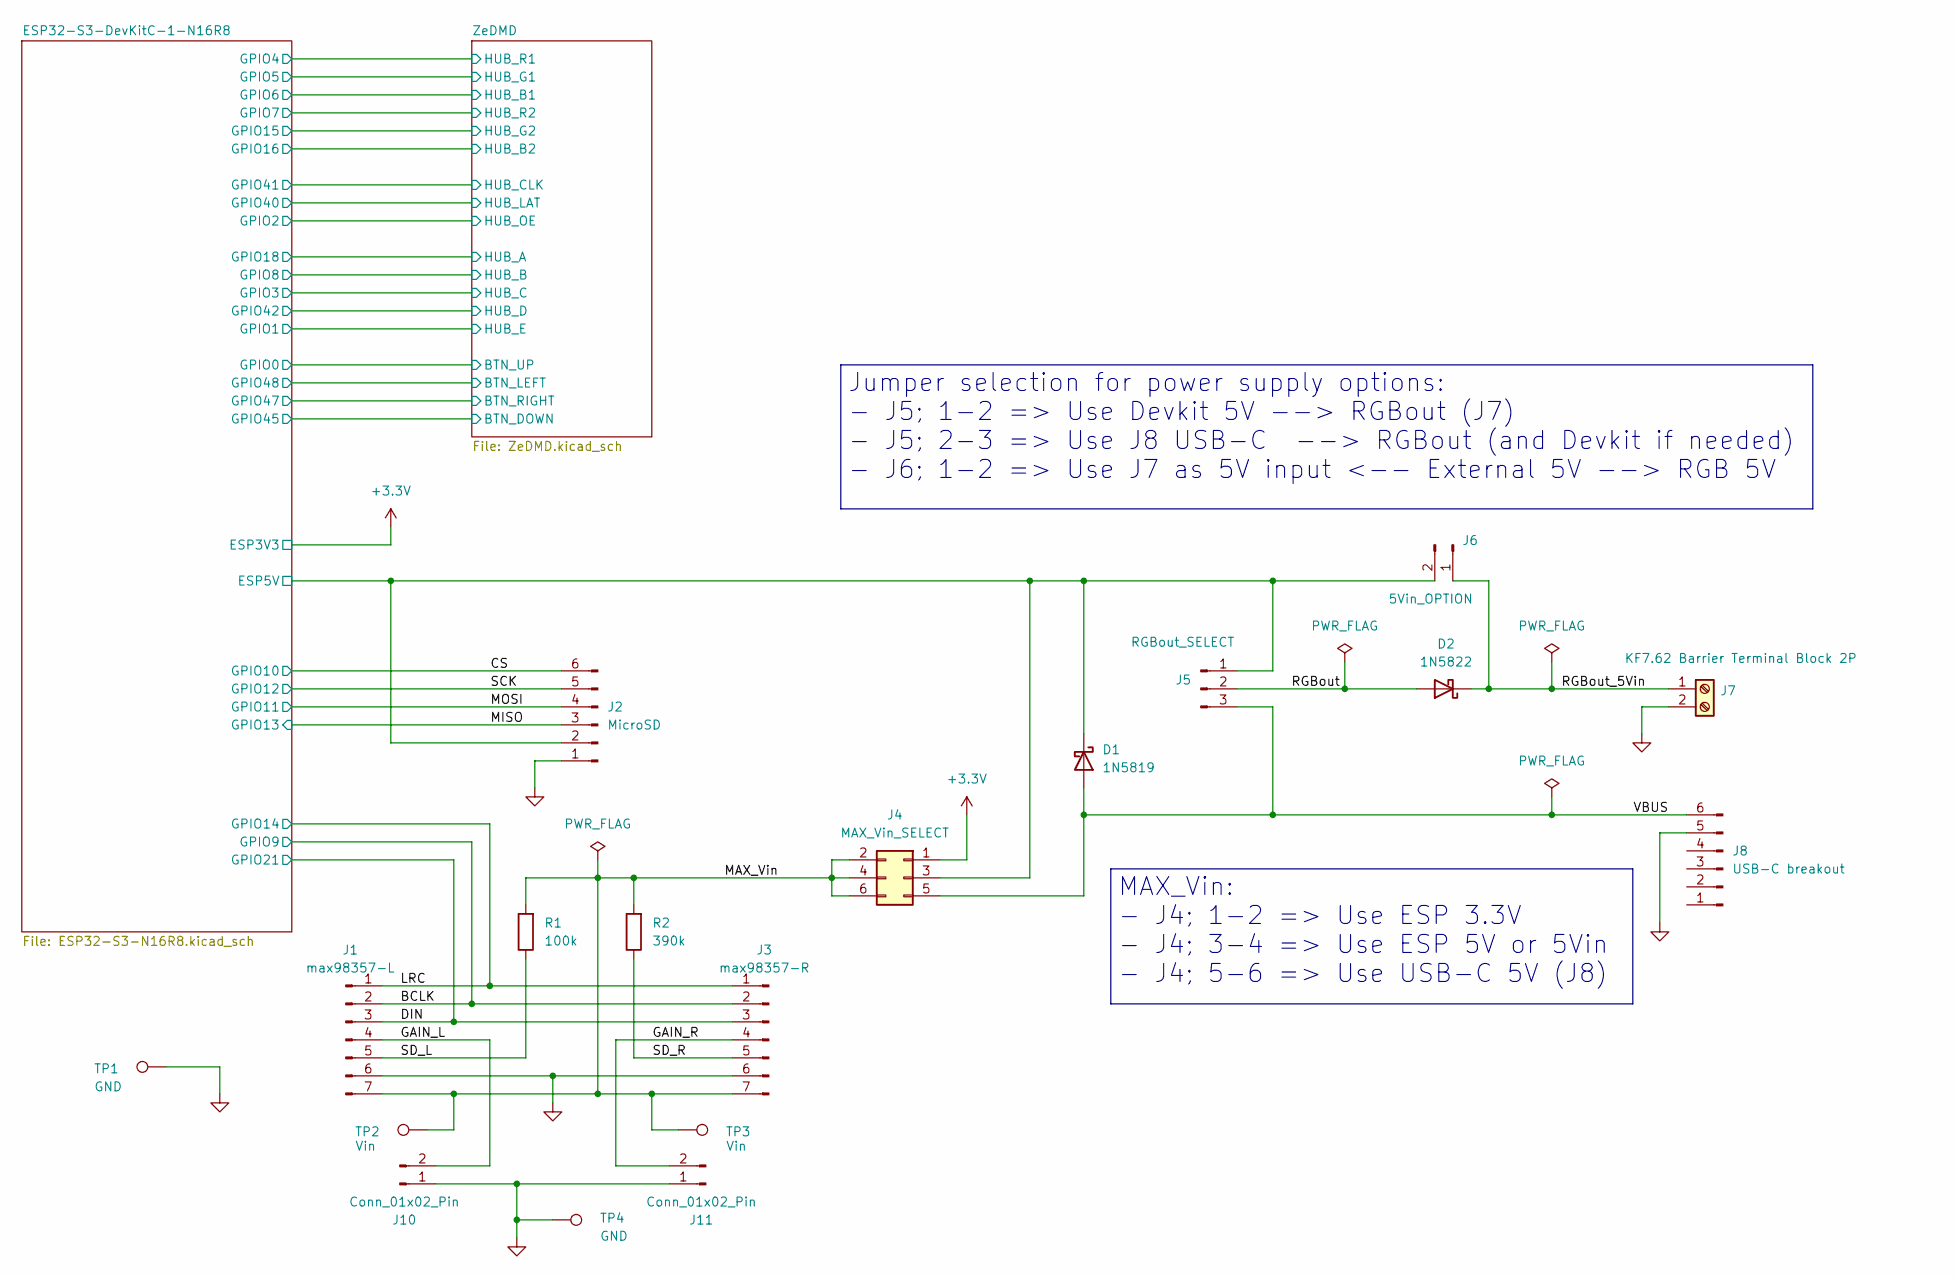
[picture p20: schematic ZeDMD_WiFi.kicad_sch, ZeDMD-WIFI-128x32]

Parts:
D1: 1N5819; D_DO-41_SOD81_P10.16mm_Horizontal
D2: 1N5822; D_DO-201AD_P15.24mm_Horizontal
J1: max98357-L; PinSocket_1x07_P2.54mm_Vertical
J2: MicroSD; PinSocket_1x06_P2.54mm_Vertical
J3: max98357-R; PinSocket_1x07_P2.54mm_Vertical
J4: MAX_Vin_SELECT; PinHeader_2x03_P2.54mm_Vertical
J5: RGBout_SELECT; PinHeader_1x03_P2.54mm_Vertical
J6: 5Vin_OPTION; PinHeader_1x02_P2.54mm_Vertical
J7: KF7.62 Barrier Terminal Block 2P; KF7.62_2P; Voltage 5V
J8: USB-C breakout; PinSocket_1x06_P2.54mm_Vertical
J10, J11: Conn_01x02_Pin; PinHeader_1x02_P2.54mm_Vertical
R1: 100k; R_Axial_DIN0207_L6.3mm_D2.5mm_P10.16mm_Horizontal
R2: 390k; R_Axial_DIN0207_L6.3mm_D2.5mm_P10.16mm_Horizontal
TP1, TP4: GND; PinHeader_1x01_P2.54mm_Vertical
TP2, TP3: Vin; PinHeader_1x01_P2.54mm_Vertical

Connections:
+3.3V: J4.1; also elsewhere on the board
/BCLK: J1.2, J3.2; also elsewhere on the board
/CS: J2.6 (CS); also elsewhere on the board
/DIN: J1.3, J3.3; also elsewhere on the board
/ESP32-S3-DevKitC-1-N16R8/ESP5V: D1.1 (K), J2.2 (VCC), J4.3, J5.1, J6.2; also elsewhere on the board
/GAIN_L: J1.4, J10.2
/GAIN_R: J3.4, J11.2
/LRC: J1.1, J3.1; also elsewhere on the board
/MAX_Vin: J1.7, J3.7, J4.2, J4.4, J4.6, R1.2, R2.2, TP2.1 (1_1), TP3.1 (1_1)
/MISO: J2.3 (MISO); also elsewhere on the board
/MOSI: J2.4 (MOSI); also elsewhere on the board
/RGBout: D2.2 (A), J5.2
/RGBout_5Vin: D2.1 (K), J6.1, J7.1
/SCK: J2.5 (SCK); also elsewhere on the board
/SD_L: J1.5, R1.1
/SD_R: J3.5, R2.1
/VBUS: D1.2 (A), J4.5, J5.3, J8.6
GND: J1.6, J2.1 (GND), J3.6, J7.2, J8.5, J10.1, J11.1, TP1.1 (1_1), TP4.1 (1_1); also elsewhere on the board

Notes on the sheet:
MAX_Vin: - J4; 1-2 => Use ESP 3.3V - J4; 3-4 => Use ESP 5V or 5Vin - J4; 5-6 => Use USB-C 5V (J8)
Jumper selection for power supply options: - J5; 1-2 => Use Devkit 5V --> RGBout (J7) - J5; 2-3 => Use J8 USB-C --> RGBout (and Devkit if needed) - J6; 1-2 => Use J7 as 5V input <-- External 5V --> RGB 5V

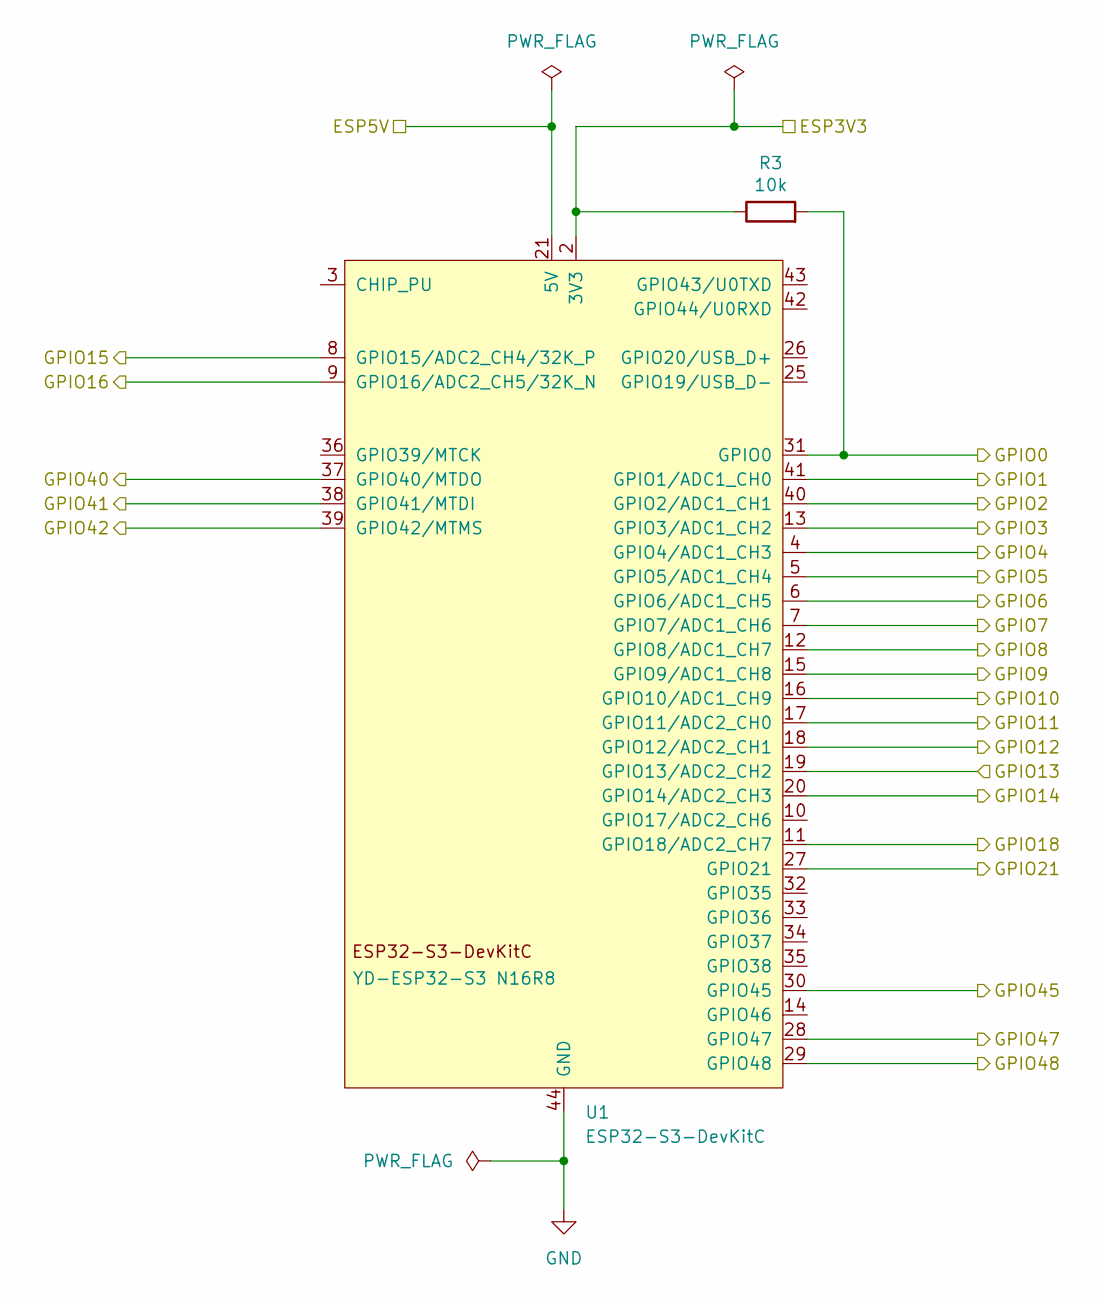
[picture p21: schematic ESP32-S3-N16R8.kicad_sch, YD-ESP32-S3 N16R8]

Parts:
R3: 10k; R_Axial_DIN0207_L6.3mm_D2.5mm_P10.16mm_Horizontal
U1: ESP32-S3-DevKitC

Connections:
+3.3V: R3.1, U1.1 (3V3), U1.2 (3V3); also elsewhere on the board
/BCLK: U1.15 (GPIO9/ADC1_CH8); also elsewhere on the board
/CS: U1.16 (GPIO10/ADC1_CH9); also elsewhere on the board
/DIN: U1.27 (GPIO21); also elsewhere on the board
/ESP32-S3-DevKitC-1-N16R8/ESP5V: U1.21 (5V); also elsewhere on the board
/LRC: U1.20 (GPIO14/ADC2_CH3); also elsewhere on the board
/MISO: U1.19 (GPIO13/ADC2_CH2); also elsewhere on the board
/MOSI: U1.17 (GPIO11/ADC2_CH0); also elsewhere on the board
/SCK: U1.18 (GPIO12/ADC2_CH1); also elsewhere on the board
/ZeDMD/BTN_DOWN: U1.30 (GPIO45); also elsewhere on the board
/ZeDMD/BTN_LEFT: U1.29 (GPIO48); also elsewhere on the board
/ZeDMD/BTN_RIGHT: U1.28 (GPIO47); also elsewhere on the board
/ZeDMD/BTN_UP: R3.2, U1.31 (GPIO0); also elsewhere on the board
/ZeDMD/HUB_A: U1.11 (GPIO18/ADC2_CH7); also elsewhere on the board
/ZeDMD/HUB_B: U1.12 (GPIO8/ADC1_CH7); also elsewhere on the board
/ZeDMD/HUB_B1: U1.6 (GPIO6/ADC1_CH5); also elsewhere on the board
/ZeDMD/HUB_B2: U1.9 (GPIO16/ADC2_CH5/32K_N); also elsewhere on the board
/ZeDMD/HUB_C: U1.13 (GPIO3/ADC1_CH2); also elsewhere on the board
/ZeDMD/HUB_CLK: U1.38 (GPIO41/MTDI); also elsewhere on the board
/ZeDMD/HUB_D: U1.39 (GPIO42/MTMS); also elsewhere on the board
/ZeDMD/HUB_E: U1.41 (GPIO1/ADC1_CH0); also elsewhere on the board
/ZeDMD/HUB_G1: U1.5 (GPIO5/ADC1_CH4); also elsewhere on the board
/ZeDMD/HUB_G2: U1.8 (GPIO15/ADC2_CH4/32K_P); also elsewhere on the board
/ZeDMD/HUB_LAT: U1.37 (GPIO40/MTDO); also elsewhere on the board
/ZeDMD/HUB_OE: U1.40 (GPIO2/ADC1_CH1); also elsewhere on the board
/ZeDMD/HUB_R1: U1.4 (GPIO4/ADC1_CH3); also elsewhere on the board
/ZeDMD/HUB_R2: U1.7 (GPIO7/ADC1_CH6); also elsewhere on the board
GND: U1.22 (GND), U1.23 (GND), U1.24 (GND), U1.44 (GND); also elsewhere on the board

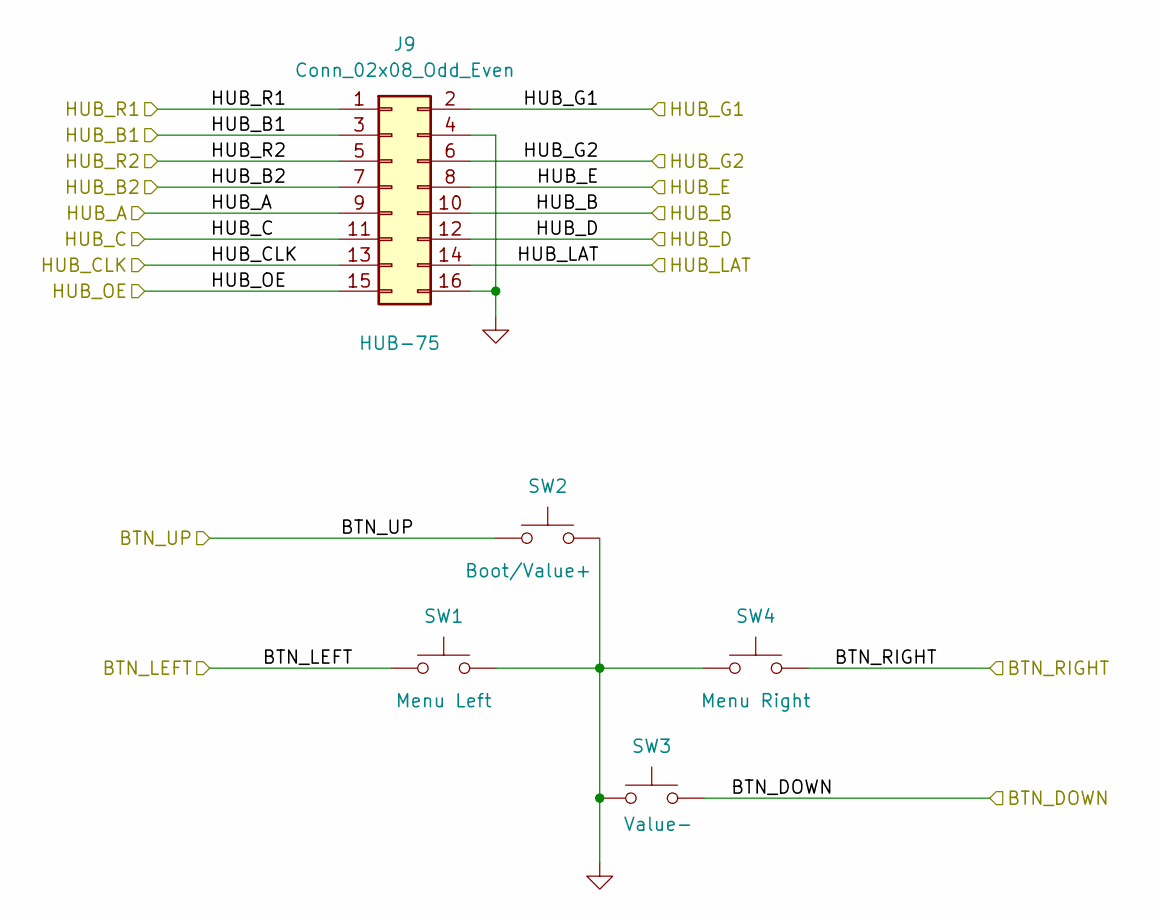
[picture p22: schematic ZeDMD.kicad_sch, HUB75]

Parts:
J9: Conn_02x08_Odd_Even; IDC-Header_2x08_P2.54mm_Vertical; JLCPCB Rotation Offset 270
SW1: Menu Left; SW_PUSH_6mm
SW2: Boot/Value+; SW_PUSH_6mm
SW3: Value-; SW_PUSH_6mm
SW4: Menu Right; SW_PUSH_6mm

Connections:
/ZeDMD/BTN_DOWN: SW3.1; also elsewhere on the board
/ZeDMD/BTN_LEFT: SW1.1; also elsewhere on the board
/ZeDMD/BTN_RIGHT: SW4.1; also elsewhere on the board
/ZeDMD/BTN_UP: SW2.1; also elsewhere on the board
/ZeDMD/HUB_A: J9.9; also elsewhere on the board
/ZeDMD/HUB_B: J9.10; also elsewhere on the board
/ZeDMD/HUB_B1: J9.3; also elsewhere on the board
/ZeDMD/HUB_B2: J9.7; also elsewhere on the board
/ZeDMD/HUB_C: J9.11; also elsewhere on the board
/ZeDMD/HUB_CLK: J9.13; also elsewhere on the board
/ZeDMD/HUB_D: J9.12; also elsewhere on the board
/ZeDMD/HUB_E: J9.8; also elsewhere on the board
/ZeDMD/HUB_G1: J9.2; also elsewhere on the board
/ZeDMD/HUB_G2: J9.6; also elsewhere on the board
/ZeDMD/HUB_LAT: J9.14; also elsewhere on the board
/ZeDMD/HUB_OE: J9.15; also elsewhere on the board
/ZeDMD/HUB_R1: J9.1; also elsewhere on the board
/ZeDMD/HUB_R2: J9.5; also elsewhere on the board
GND: J9.4, J9.16, SW1.2, SW2.2, SW3.2, SW4.2; also elsewhere on the board

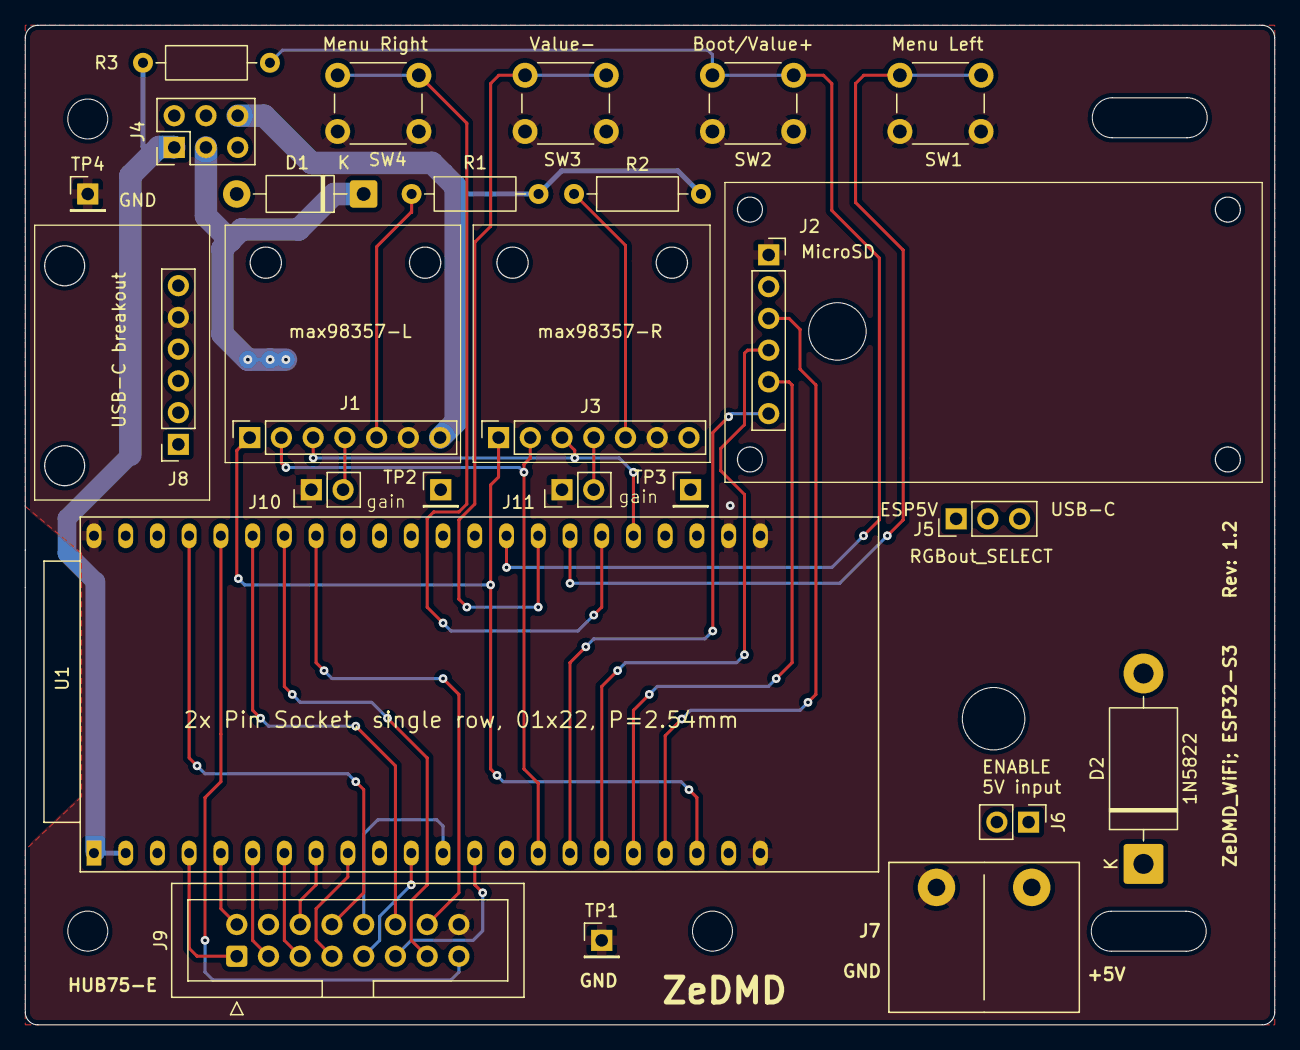
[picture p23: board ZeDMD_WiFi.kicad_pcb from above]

Board: 4 copper layers, 100.0 x 80.0 mm, 25 parts (0 on the bottom side), 36 nets.

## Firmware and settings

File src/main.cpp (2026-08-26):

#include <Arduino.h>
#include <algorithm>
#include <memory>
#include <AsyncUDP.h>
#include <Bounce2.h>
#include <ESPAsyncWebServer.h>
#include <ESPmDNS.h>
#include <LittleFS.h>
#include <WiFi.h>
#include <HTTPClient.h>
#ifdef ZEDMD_WIFI
#include <PubSubClient.h>
#include <Update.h>
#endif

#include <cstring>
#include <AnimatedGIF.h>
#ifdef WEBRADIO_ENABLED
#include "radio.h"
#endif
#ifdef ZEDMD_WIFI
#include "weather.h"
#include "clock.h"
#endif
#include "sd_interface.h"
#ifdef SD_MMC_BUILD
  #define SD_MMC_CLK_PIN  39
  #define SD_MMC_CMD_PIN  38
  #define SD_MMC_DATA_PIN 40
#else
  #include <SPI.h>
  // SD card SPI pins
  #ifdef CONFIG_IDF_TARGET_ESP32S3
    // ESP32-S3 pins (HUB75 occupies other pins) — overridable via build_flags
    #ifndef SD_MOSI
    #define SD_MOSI 11
    #endif
    #ifndef SD_MISO
    #define SD_MISO 13
    #endif
    #ifndef SD_SCK
    #define SD_SCK  12
    #endif
    #ifndef SD_CS
    #define SD_CS   10
    #endif
  #elif defined(ZEDMD_WIFI)
    // Standard ESP32 WiFi Build
    #define SD_MOSI 18
    #define SD_MISO 21
    #define SD_SCK  2
    #define SD_CS   33
  #else
    // Standard ESP32 USB build — no SD card
    #define SD_MOSI 18
    #define SD_MISO 21
    #define SD_SCK  2
    #define SD_CS   33
  #endif
#endif

#include "displayDriver.h"  // Base class for all display drivers
#include "esp_log.h"
#include "esp_partition.h"
#include "esp_task_wdt.h"
#include "freertos/FreeRTOS.h"
#include "freertos/portmacro.h"
#include "freertos/semphr.h"
#include "freertos/task.h"
#include "miniz/miniz.h"
#include "panel.h"
#include "version.h"
#include <time.h>  // NTP / time

// To save RAM only include the driver we want to use.
#ifdef DISPLAY_RM67162_AMOLED
#include "displays/Rm67162Amoled.h"
#else
#include "displays/LEDMatrix.h"
#endif

#define N_FRAME_CHARS 5
#define N_CTRL_CHARS 5
#define N_ACK_CHARS (N_CTRL_CHARS + 1)
#define N_INTERMEDIATE_CTR_CHARS 4
#ifdef BOARD_HAS_PSRAM
#define NUM_BUFFERS 128  // Number of buffers
#ifdef DISPLAY_RM67162_AMOLED
// @fixme double buffering doesn't work on Lilygo Amoled
#define NUM_RENDER_BUFFERS 1
#else
#define NUM_RENDER_BUFFERS 2
#endif
#define BUFFER_SIZE 1152
#else
#define NUM_BUFFERS 12  // Number of buffers
#define NUM_RENDER_BUFFERS 1
#define BUFFER_SIZE 1152
#endif
#if defined(ARDUINO_ESP32_S3_N16R8) || defined(DISPLAY_RM67162_AMOLED)
// USB CDC
#define SERIAL_BAUD 115200
#define USB_PACKAGE_SIZE 512
#else
#define SERIAL_BAUD 921600
#define USB_PACKAGE_SIZE 32
#endif
#define SERIAL_TIMEOUT \
  8  // Time in milliseconds to wait for the next data chunk.

#define CONNECTION_TIMEOUT 5000

#ifdef ARDUINO_ESP32_S3_N16R8
#define UP_BUTTON_PIN 0
#define DOWN_BUTTON_PIN 45
#define FORWARD_BUTTON_PIN 48
#define BACKWARD_BUTTON_PIN 47
#elif defined(DISPLAY_RM67162_AMOLED)
#define UP_BUTTON_PIN 0
#define FORWARD_BUTTON_PIN 21
#else
#define UP_BUTTON_PIN 21
#define FORWARD_BUTTON_PIN 33
#endif

#define LED_CHECK_DELAY 1000  // ms per color

#define RC 0
#define GC 1
#define BC 2

enum {
  TRANSPORT_USB = 0,
  TRANSPORT_WIFI_UDP = 1,
  TRANSPORT_WIFI_TCP = 2,
  TRANSPORT_SPI = 3
};

const uint8_t FrameChars[5]
    __attribute__((aligned(4))) = {'F', 'R', 'A', 'M', 'E'};
const uint8_t CtrlChars[6]
    __attribute__((aligned(4))) = {'Z', 'e', 'D', 'M', 'D', 'A'};
uint8_t numCtrlCharsFound = 0;

AsyncWebServer *server;
AsyncServer *tcp;
AsyncUDP *udp;
DisplayDriver *display;

// Buffers for storing data
uint8_t *buffers[NUM_BUFFERS];
mz_ulong bufferSizes[NUM_BUFFERS] __attribute__((aligned(4))) = {0};
bool bufferCompressed[NUM_BUFFERS] __attribute__((aligned(4))) = {0};

// The uncompress buffer should be bug enough
uint8_t* uncompressBuffer = nullptr;  // allocated in PSRAM (setup)
uint8_t *renderBuffer[NUM_RENDER_BUFFERS];
uint8_t currentRenderBuffer __attribute__((aligned(4)));
uint8_t lastRenderBuffer __attribute__((aligned(4)));
char tmpStringBuffer[33] __attribute__((aligned(4))) = {0};
bool payloadCompressed __attribute__((aligned(4)));
uint16_t payloadSize __attribute__((aligned(4)));
uint16_t payloadMissing __attribute__((aligned(4)));
uint8_t headerBytesReceived __attribute__((aligned(4)));
uint8_t command __attribute__((aligned(4)));
uint8_t currentBuffer __attribute__((aligned(4)));
uint8_t lastBuffer __attribute__((aligned(4)));
uint8_t processingBuffer __attribute__((aligned(4)));

// Init display on a low brightness to avoid power issues, but bright enough to
// see something.
#ifdef DISPLAY_RM67162_AMOLED
uint8_t brightness = 5;
#else
uint8_t brightness = 2;
int8_t rgbMode = 0;
uint8_t rgbModeLoaded = 0;
int8_t yOffset = 0;
#ifdef DISPLAY_LED_MATRIX
uint8_t panelClkphase = 0;
uint8_t panelDriver = 0;
uint8_t panelLineDecoder = 0;
uint8_t panelI2sspeed = 8;
uint8_t panelLatchBlanking = 2;
uint8_t panelMinRefreshRate = 30;
#endif

// I needed to change these from RGB to RC (Red Color), BC, GC to prevent
// conflicting with the TFT_SPI Library.
const uint8_t rgbOrder[3 * 6] = {
    RC, GC, BC,  // rgbMode 0
    BC, RC, GC,  // rgbMode 1
    GC, BC, RC,  // rgbMode 2
    RC, BC, GC,  // rgbMode 3
    GC, RC, BC,  // rgbMode 4
    BC, GC, RC   // rgbMode 5
};

#endif
uint8_t usbPackageSizeMultiplier = USB_PACKAGE_SIZE / 32;
uint8_t settingsMenu = 0;
uint8_t debug = 0;
uint8_t udpDelay = 5;

String ssid;
String pwd;
uint16_t port = 3333;
uint8_t ssid_length;
uint8_t pwd_length;
bool wifiActive;
#ifdef ZEDMD_WIFI
int8_t transport = TRANSPORT_WIFI_UDP;
#else
int8_t transport = TRANSPORT_USB;
#endif
// ── Log Ring-Buffer ───────────────────────────────────────────────────────────
#define LOG_LINES        80
#define LOG_LINE_LEN     120
#define RTC_LOG_LINES    40
#define RTC_LINE_LEN     100
#define CRASH_LOG_SLOTS  10

static char (*logBuffer)[LOG_LINE_LEN] = nullptr;  // allocated in PSRAM (setup)
static uint8_t logHead = 0;
static uint8_t logCount = 0;
static portMUX_TYPE logMux = portMUX_INITIALIZER_UNLOCKED;

// RTC memory: survives Watchdog/Exception resets
RTC_DATA_ATTR static char rtcLog[RTC_LOG_LINES][RTC_LINE_LEN];
RTC_DATA_ATTR static uint8_t rtcLogHead = 0;
RTC_DATA_ATTR static uint8_t rtcLogCount = 0;
RTC_DATA_ATTR static bool     rtcLogValid   = false;
RTC_DATA_ATTR static uint32_t rtcLastUptime = 0;   // seconds of last stable run; 0 after POWERON

void logMsg(const char* fmt, ...) {
  char tmp[LOG_LINE_LEN];
  va_list args;
  va_start(args, fmt);
  vsnprintf(tmp, sizeof(tmp), fmt, args);
  va_end(args);
#ifdef WEBRADIO_ENABLED
  if (!radioIsPlaying) Serial.println(tmp);
#else
  Serial.println(tmp);
#endif
  uint32_t ms = millis();
  char line[LOG_LINE_LEN];
  snprintf(line, sizeof(line), "[%lu.%03lu] %s", ms / 1000, ms % 1000, tmp);
  portENTER_CRITICAL(&logMux);
  if (logBuffer) {
    strncpy(logBuffer[logHead], line, LOG_LINE_LEN - 1);
    logHead = (logHead + 1) % LOG_LINES;
    if (logCount < LOG_LINES) logCount++;
  }
  // Also write to RTC memory
  strncpy(rtcLog[rtcLogHead], line, RTC_LINE_LEN - 1);
  rtcLog[rtcLogHead][RTC_LINE_LEN - 1] = '\0';
  rtcLogHead = (rtcLogHead + 1) % RTC_LOG_LINES;
  if (rtcLogCount < RTC_LOG_LINES) rtcLogCount++;
  rtcLogValid = true;
  portEXIT_CRITICAL(&logMux);
}
// ── Crash diagnostics (LittleFS, consistent with settings pattern) ───────────

// File-scope: no C++ guard needed, safe after PANIC reset
static constexpr int kRsnN = 9;
static const struct { esp_reset_reason_t r; const char* name; } kRsn[kRsnN] = {
  { ESP_RST_POWERON,    "POWERON"    },
  { ESP_RST_SW,         "SW"         },
  { ESP_RST_PANIC,      "PANIC"      },
  { ESP_RST_INT_WDT,    "INT_WDT"    },
  { ESP_RST_TASK_WDT,   "TASK_WDT"   },
  { ESP_RST_WDT,        "WDT"        },
  { ESP_RST_BROWNOUT,   "BROWNOUT"   },
  { ESP_RST_PWR_GLITCH, "PWR_GLITCH" },
  { ESP_RST_CPU_LOCKUP, "CPU_LOCKUP" },
};

static uint32_t diagBootCount = 0;

static uint32_t diagReadUInt(const char* json, const char* key, uint32_t def) {
  char needle[32];
  snprintf(needle, sizeof(needle), "\"%s\":", key);
  const char* p = strstr(json, needle);
  if (!p) return def;
  p += strlen(needle);
  while (*p == ' ') p++;
  return (uint32_t)strtoul(p, nullptr, 10);
}

// Call directly after LittleFS.begin() — before LoadSettingsMenu() and the
// esp_reset_reason() switch in setup(). On dump the RTC buffer contains
// exactly 1 new "=== ZeDMD booting ===" entry; the rest is pre-crash log.
static void diagBoot() {
  // static: no stack pressure after PANIC (stack might be partially corrupted)
  esp_task_wdt_reset();  // 3× flash writes (crash log + diag.json) can take >2s on fragmented LFS
  static char jsonBuf[600];
  strcpy(jsonBuf, "{}");
  {
    File rf = LittleFS.open("/diag.json", "r");
    if (rf) {
      size_t n = rf.readBytes(jsonBuf, sizeof(jsonBuf) - 1);
      jsonBuf[n] = '\0';
      rf.close();
    }
  }

  // ── Save pre-crash state BEFORE logMsg() — dump condition is based on it ──
  bool    preLogValid = rtcLogValid;
  uint8_t preLogCount = rtcLogCount;
  uint8_t preLogHead  = rtcLogHead;
  // zero rtcLastUptime immediately — bootloop guard: next reboot sees 0
  uint32_t lastUp     = rtcLastUptime;
  rtcLastUptime       = 0;
  logMsg("diagBoot: preLog snapped valid=%d count=%d lastUp=%us",
         (int)preLogValid, (int)preLogCount, (unsigned)lastUp);

  diagBootCount        = diagReadUInt(jsonBuf, "boots",      0) + 1;
  uint8_t  crashNext   = (uint8_t)(diagReadUInt(jsonBuf, "crashNext", 0) % CRASH_LOG_SLOTS);
  uint32_t otherCount  = diagReadUInt(jsonBuf, "boots_OTHER", 0);
  uint32_t counts[kRsnN];

  esp_reset_reason_t reason     = esp_reset_reason();
  const char*        reasonName = "OTHER";
  for (int i = 0; i < kRsnN; i++) {
    char key[20];
    snprintf(key, sizeof(key), "boots_%s", kRsn[i].name);
    counts[i] = diagReadUInt(jsonBuf, key, 0);
    if (kRsn[i].r == reason) { counts[i]++; reasonName = kRsn[i].name; }
  }
  if (strcmp(reasonName, "OTHER") == 0) otherCount++;
  logMsg("diagBoot: reason=%s boots=%u", reasonName, (unsigned)diagBootCount);

  logMsg("Boot #%u | Reset: %s | Heap: %u | lastUp: %us",
         (unsigned)diagBootCount, reasonName,
         (unsigned)esp_get_free_heap_size(), (unsigned)lastUp);

  // Dump only if: valid pre-crash log, no clean reboot.
  // Bootloop guard (lastUp > 60) only for BROWNOUT/PWR_GLITCH — real crashes
  // (PANIC, WDT) always dump, even if the previous boot was short.
  bool isCleanReset = (reason == ESP_RST_POWERON ||
                       reason == ESP_RST_SW       ||
                       reason == ESP_RST_DEEPSLEEP);
  bool isBrownout   = (reason == ESP_RST_BROWNOUT ||
                       reason == ESP_RST_PWR_GLITCH);
  bool isPanicOrWdt = !isCleanReset && !isBrownout;
  // PANIC/WDT: always dump (even with only 1 log line — early crash)
  // BROWNOUT/other: only dump if enough log present and no short boot
  bool shouldDump   = preLogValid && !isCleanReset && (
                        isPanicOrWdt ||
                        (preLogCount > 1 && (!isBrownout || lastUp > 60)));

  logMsg("diagBoot: valid=%d count=%d dump=%d reason=%s",
         (int)preLogValid, (int)preLogCount, (int)shouldDump, reasonName);

  if (shouldDump) {
    if (!LittleFS.exists("/crashlogs")) LittleFS.mkdir("/crashlogs");
    char fname[32];
    snprintf(fname, sizeof(fname), "/crashlogs/crash-%u.txt", (unsigned)crashNext);
    File f = LittleFS.open(fname, "w");
    if (f) {
      char hdr[80];
      snprintf(hdr, sizeof(hdr), "=== Crash %u | Reset: %s | Boot#%u | uptime: %us ===\n",
               (unsigned)crashNext, reasonName, (unsigned)diagBootCount, (unsigned)lastUp);
      f.print(hdr);
      uint8_t start = (preLogCount < RTC_LOG_LINES) ? 0 : preLogHead;
      for (uint8_t i = 0; i < preLogCount; i++)
        f.println(rtcLog[(start + i) % RTC_LOG_LINES]);
      f.close();
      crashNext   = (uint8_t)((crashNext + 1) % CRASH_LOG_SLOTS);
      rtcLogValid = false;
      rtcLogCount = 0;
      rtcLogHead  = 0;
      logMsg("Crash-Dump: %s (uptime war %us)", fname, (unsigned)lastUp);
    } else {
      logMsg("diagBoot: FEHLER - %s konnte nicht geoeffnet werden", fname);
    }
  }

  esp_task_wdt_reset();  // Between crash-log write and diag.json write — both together >5s on fragmented LFS
  File wf = LittleFS.open("/diag.json.tmp", "w");
  if (wf) {
    wf.printf("{\n  \"boots\": %u,\n  \"lastReset\": \"%s\",\n  \"crashNext\": %u",
              (unsigned)diagBootCount, reasonName, (unsigned)crashNext);
    for (int i = 0; i < kRsnN; i++)
      wf.printf(",\n  \"boots_%s\": %u", kRsn[i].name, (unsigned)counts[i]);
    wf.printf(",\n  \"boots_OTHER\": %u\n}\n", (unsigned)otherCount);
    wf.close();
    LittleFS.rename("/diag.json.tmp", "/diag.json");
  }
}

// ─────────────────────────────────────────────────────────────────────────────
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
void loop() {
  esp_task_wdt_reset();

  // Keep uptime in RTC for boot-loop protection — no flash write, µs overhead
  {
    static uint32_t lastUptimeUpdate = 0;
    uint32_t nowSec = millis() / 1000;
    if (nowSec - lastUptimeUpdate >= 5) {
      lastUptimeUpdate = nowSec;
      rtcLastUptime    = nowSec;
    }
  }

  // Heap monitor: log internal SRAM heap every 30s — stored in RTC ring buffer
  // so the next crash log shows heap history before the crash.
  {
    static uint32_t lastHeapLog = 0;
    uint32_t now = millis();
    if (now - lastHeapLog >= 30000) {
      lastHeapLog = now;
      logMsg("Heap: free=%u minEver=%u PSRAM=%u",
             (uint32_t)ESP.getFreeHeap(),
             (uint32_t)ESP.getMinFreeHeap(),
             (uint32_t)ESP.getFreePsram());
    }
    if (now - displayTimerLastCheck >= 60000) {
      displayTimerLastCheck = now;
      CheckDisplayTimer();
    }
  }

  CheckMenuButton();

  if (sdUpdatePending) {
    sdUpdatePending = false;
    checkSdFirmwareUpdate();
  }

  // Reload screensaver files when path changed
  // screensaverLoadRunning prevents re-entrant calls on rapid path changes
  if (screensaverReloadNeeded && !screensaverLoadRunning) {
    screensaverReloadNeeded = false;
    screensaverLoadRunning  = true;
    SaveScreensaverPaths();
    display->DisplayText("loading...", 0, 26, 180, 180, 180);
    Render();
    LoadScreensaverFiles();
    screensaverLoadRunning = false;
    if (screensaverCount > 0 && sdCardAvailable) {
      display->DisplayText("SD OK     ", 0, 26, 0, 255, 100);
    } else {
      display->DisplayText("LittleFS OK", 0, 26, 180, 180, 180);
    }
    Render();
    vTaskDelay(pdMS_TO_TICKS(800));
  }

  // SD Karte refreshen und Cache aktualisieren
  if (sdRefreshNeeded) {
    sdRefreshNeeded = false;
#ifdef SD_MMC_BUILD
    SD_MMC.end();
#else
    SD.end();
    spiSD.end();
#endif
    vTaskDelay(pdMS_TO_TICKS(100));
    InitSDCard();
    GetSDFolders();
  }

  // GIF-Audio-Dateiliste cachen (statt SD-I/O im Webserver-Callback)
  if (gifAudioRefreshNeeded && sdCardAvailable) {
    gifAudioRefreshNeeded = false;
    if (!TryLoadGifAudioCache()) {
      logMsg("GifAudio: scanne %s ...", GIF_AUDIO_DIR);
      if (!SD.exists(GIF_AUDIO_DIR)) SD.mkdir(GIF_AUDIO_DIR);
      File dir = SD.open(GIF_AUDIO_DIR);
      // PSRAM-Puffer: max ~3000 Dateien × 100 Byte/Eintrag — kein String-Heap
      const size_t gifBufSize = 300 * 1024;
      char* jsonBuf = (char*)heap_caps_malloc(gifBufSize, MALLOC_CAP_SPIRAM | MALLOC_CAP_8BIT);
      size_t jsonPos = 0;
      if (jsonBuf) jsonBuf[jsonPos++] = '[';
      bool first = true;
      uint16_t gifAudioCount = 0;
      bool cancelled = false;
      while (File f = dir.openNextFile()) {
        if (cancelSdScan) {
          f.close();
          cancelled = true;
          cancelSdScan = false;
          break;
        }
        char name[256];
        strncpy(name, f.name(), sizeof(name) - 1);
        name[sizeof(name) - 1] = '\0';
        bool isDir = f.isDirectory();
        uint32_t sz = f.size();
        f.close();
        if (name[0] != '.' && !strstr(name, ".tmp") && !isDir && jsonBuf && jsonPos + 128 < gifBufSize) {
          if (!first) jsonBuf[jsonPos++] = ',';
          jsonPos += snprintf(jsonBuf + jsonPos, gifBufSize - jsonPos - 4,
                              "{\"name\":\"%s\",\"size\":%u}", name, sz);
          first = false;
          gifAudioCount++;
          if ((gifAudioCount % 50) == 0) {
#ifdef WEBRADIO_ENABLED
            if (!radioIsPlaying) {
#endif
              char msg[24];
              snprintf(msg, sizeof(msg), "GifAudio %-5d", gifAudioCount);
              display->DisplayText(msg, 0, 13, 255, 180, 0);
              Render();
#ifdef WEBRADIO_ENABLED
            }
#endif
          }
        }
        esp_task_wdt_reset();
      }
      dir.close();
      if (cancelled) {
        logMsg("GifAudio: Scan abgebrochen nach %d Dateien", gifAudioCount);
        if (jsonBuf) heap_caps_free(jsonBuf);
      } else if (jsonBuf) {
        jsonBuf[jsonPos++] = ']';
        jsonBuf[jsonPos] = '\0';
        char* exact = (char*)heap_caps_realloc(jsonBuf, jsonPos + 1, MALLOC_CAP_SPIRAM | MALLOC_CAP_8BIT);
        if (exact) jsonBuf = exact;
        char* old = cachedGifAudioFiles;
        cachedGifAudioFiles = jsonBuf;
        if (old) heap_caps_free(old);
        logMsg("GifAudio: %d Dateien gefunden, Cache gespeichert", gifAudioCount);
        SaveGifAudioCache();
      }
    }
  }

  // Cache-Invalidierungen aus Webserver-Task (eject, Ordnerwechsel) — nur loop() darf psramCacheSet aufrufen
  if (sdFoldersInvalidateNeeded) {
    sdFoldersInvalidateNeeded = false;
    psramCacheSet(&cachedSDFolders, String("[]"));
    sdFoldersRefreshNeeded = true;
  }
  if (sdFoldersRefreshNeeded && sdCardAvailable) {
    sdFoldersRefreshNeeded = false;
    GetSDFolders();
  }
  if (sdFilesInvalidateNeeded) {
    sdFilesInvalidateNeeded = false;
    psramCacheSet(&cachedSdFiles, String("[]"));
  }

  if (iconsReloadNeeded) {
    iconsReloadNeeded = false;
    esp_task_wdt_reset();
    LoadIcons();
    radioIconSlugsLoad();  // Negative-Cache leeren — neues Logo sonst erst nach Reboot sichtbar
  }

  // Cache SD file list for the selected folder
  if (sdFilesRefreshNeeded && sdCardAvailable && cachedSdFilesFolder[0] != '\0') {
    sdFilesRefreshNeeded = false;
    String json = "[";
    File dir = SD.open(cachedSdFilesFolder);
    if (dir && dir.isDirectory()) {
      bool first = true;
      uint16_t fileCount = 0;
      File f = dir.openNextFile();
      while (f) {
        if (!f.isDirectory()) {
          const char* fname = f.name();
          if (fname && fname[0] != '.') {
            if (!first) json += ",";
            json += "\"" + String(fname) + "\"";
            first = false;
          }
        }
        if ((++fileCount % 50) == 0) esp_task_wdt_reset();
        f.close();
        f = dir.openNextFile();
      }
      dir.close();
    }
    json += "]";
    psramCacheSet(&cachedSdFiles, json);
  }

  // WiFi reconnect on lost connection — at most every 5s, no delay/return so
  // screensaver and GIF playback continue during reconnect
  static uint32_t lastReconnectMs = 0;
  if (wifiActive && WiFi.status() != WL_CONNECTED) {
    uint32_t now = millis();
    if (now - lastReconnectMs >= 5000) {
      lastReconnectMs = now;
      WiFi.reconnect();
    }
  }


  if (!transportActive) {
    static bool weatherIconTestRendered = false;
    if (weatherIconTestActive) {
      if (!weatherIconTestRendered) {
        weatherIconTest();
        weatherIconTestRendered = true;
      }
      return;
    }
    weatherIconTestRendered = false;

    static bool weatherSmallIconTestRendered = false;
    if (weatherSmallIconTestActive) {
      if (!weatherSmallIconTestRendered) {
        weatherSmallIconTest();
        weatherSmallIconTestRendered = true;
      }
      return;
    }
    weatherSmallIconTestRendered = false;

    if (wifiActive && !serverRunning) {
      // @see https://github.com/ESP32Async/ESPAsyncWebServer/issues/21
      // StartServer();
    }

    // ── Screensaver / Clock Logik ─────────────────────────────────────────
    // Guard BEFORE counter increment: prevents DisplayUpdate() or
    // PlayGIF() from overwriting the setup screen while it should be visible.
    if (setupScreenUntil > 0 && millis() < setupScreenUntil) return;
    setupScreenUntil = 0;

    if (!logoActive) {
      logoActive = true;
      logoWaitCounter = 199;
    }

    ++logoWaitCounter;
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

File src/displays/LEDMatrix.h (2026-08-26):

#ifndef LEDMATRIX_H
#define LEDMATRIX_H

#ifdef ARDUINO_ESP32_S3_N16R8
#define R1_PIN 4
#define G1_PIN 5
#define B1_PIN 6
#define R2_PIN 7
#define G2_PIN 15
#define B2_PIN 16
#define A_PIN 18
#define B_PIN 8
#define C_PIN 3
#define D_PIN 42
#define E_PIN 1  // required for 1/32 scan panels, like 64x64.
// ⚠️ SDMMC board: GPIO 40 = SDMMC DATA, GPIO 41 = SDMMC CLK
//    → HUB75 LAT/CLK must be rewired to free pins!
//    SPI-SD board:   LAT=40, CLK=41  (standard cable)
//    SDMMC board:    LAT=46, CLK=17  (rewire cable!)
#ifdef SD_MMC_BUILD
#define LAT_PIN 46
#define CLK_PIN 17
#else
#define LAT_PIN 40
#define CLK_PIN 41
#endif
#define OE_PIN 2
#else
// Pinout derived from ESP32-HUB75-MatrixPanel-I2S-DMA.h
#define R1_PIN 25
#define G1_PIN 26
#define B1_PIN 27
#define R2_PIN 14
#define G2_PIN 12
#define B2_PIN 13
#define A_PIN 23
#define B_PIN 19
#define C_PIN 5
#define D_PIN 17
#define E_PIN \
  22  // required for 1/32 scan panels, like 64x64. Any available pin would do,
      // i.e. IO32. If 1/16 scan panels, no connection to this pin needed
#define LAT_PIN 4
#define OE_PIN 15
#define CLK_PIN 16

#endif

#include <ESP32-HUB75-MatrixPanel-I2S-DMA.h>

#include "displayDriver.h"
#include "panel.h"  // Include ZeDMD panel constants

extern int8_t rgbMode;
extern int8_t yOffset;
extern uint8_t panelClkphase;
extern uint8_t panelDriver;
extern uint8_t panelLineDecoder;
extern uint8_t panelI2sspeed;
extern uint8_t panelLatchBlanking;
extern uint8_t panelMinRefreshRate;
extern const uint8_t rgbOrder[3 * 6];

class LedMatrix : public DisplayDriver {
 private:
  MatrixPanel_I2S_DMA *dma_display;
  GFXcanvas16 *textCanvas = nullptr;
  const uint8_t lumval[16] = {0,  2,  4,  7,   11,  18,  30,  40,
                              50, 65, 80, 100, 125, 160, 200, 255};

 public:
  LedMatrix();  // Constructor

  bool HasScalingModes();
  const char **GetScalingModes();
  uint8_t GetScalingModeCount();
  uint8_t GetCurrentScalingMode();
  void SetCurrentScalingMode(uint8_t mode);

  void DrawPixel(uint16_t x, uint16_t y, uint8_t r, uint8_t g, uint8_t b);
  void DrawPixel(uint16_t x, uint16_t y, uint16_t color);
  void ClearScreen();
  void SetBrightness(uint8_t level);
  void FillScreen(uint8_t r, uint8_t g, uint8_t b);
  void DisplayText(const char *text, uint16_t x, uint16_t y, uint8_t r,
                   uint8_t g, uint8_t b, bool transparent = false,
                   bool inverted = false);
  void DisplayTextScaled(const char *text, uint16_t x, uint16_t y,
                          uint8_t r, uint8_t g, uint8_t b,
                          uint8_t scale = 1) override;
  void DisplayTextGFX(const char *text, int16_t x, uint8_t r,
                      uint8_t g, uint8_t b);
  uint16_t GetTextGFXWidth(const char *text);
  void RenderTextGFXToBuffer(uint8_t *buf, const char *text, int16_t x,
                              uint8_t r, uint8_t g, uint8_t b);
  void RenderRadioToBuffer(uint8_t *buf, const char *station,
                           const char *title,
                           int16_t stationX, int16_t titleX,
                           uint8_t stR, uint8_t stG, uint8_t stB,
                           uint8_t r, uint8_t g, uint8_t b);
  uint16_t GetRadioTitleWidth(const char *text);
#ifdef FONT_TEST_ENABLED
  void RenderFontTestToBuffer(uint8_t *buf, const char *text, const char *fontName,
                               uint8_t lines, uint8_t r, uint8_t g, uint8_t b) override;
  const char* GetFontListJSON() override;
#endif
  void EraseVLine(int16_t x) override;
  void FillZoneRaw(uint8_t idx, uint8_t *pBuffer);
  void FillZoneRaw565(uint8_t idx, uint8_t *pBuffer);
  void ClearZone(uint8_t idx);
  void FillPanelRaw(uint8_t *pBuffer) override;

  ~LedMatrix();  // Destructor
};

#endif  // LEDMATRIX_H

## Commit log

2026-05-17 Initial commit — ZeDMD WiFi Firmware 5.1.8 mit allen Bugfixes
    - Clock-Flicker-Fix: DisplayClock() nur bei Minutenwechsel oder Farbänderung
    - Mode 2 (Clock+Screensaver): Phase-Timer für sauberen Wechsel
    - GIF Standbild-Fix: playFrame(false) mit manuellem endTime-aware Delay
    - XSS-Fix in Dateilisten (createElement statt innerHTML)
    - /upload_file Endpoint für HTML-Updates ohne Filesystem-Flash
    - Uhr-Farbauswahl im Webinterface mit sofortiger Vorschau
    [partitions.csv, partitions_16MB.csv, partitions_lily.csv]
2026-06-02 Release: ZeDMD 5.1.8 WiFi Fork — 128x32, ESP32-S3-N16R8
    Personal hobby fork of PPUC/ZeDMD v5.1.8, WiFi-only build targeting the
    ESP32-S3-N16R8 with a 128x32 HUB75 LED matrix.
    New features vs. original ZeDMD:
    - Webradio: internet radio via MAX98357A I2S amplifier, preset management,
    volume control, station/title display on LED matrix
    - SDMMC board support: onboard SD card via SDMMC interface (1-bit mode)
    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
    [partitions_16MB.csv, partitions_lily.csv]
2026-06-02 Docs: Stereo-Audio als geplantes Feature mit Pin-Belegung und Erklärung
2026-06-02 Feature: Preset-Panel auf index.html + Code-Review-Fixes
    - Gespeicherte Sender als ausklappbares Panel in Radio-Sektion (wie Favoriten)
    - Aktiver Sender grün hervorgehoben, alle anderen direkt anspielbar
    - Panel aktualisiert sich automatisch alle 5s wenn geöffnet
    - Doppeltes IIFE in loadSDScreensaverFiles entfernt
    - Doppeltes requestAnimationFrame in loadConfig entfernt
    - gifAudioLoad: innerHTML durch createElement/textContent ersetzt (XSS-Schutz)
    - gifAudioLoad() in window.onload verschoben
    - Volume-Anzeige: min-width 24px → 30px (kein Springen bei "21")
2026-06-03 Release: GIF preview, GIF audio, Webradio station manager and firmware stability
    - In-browser GIF preview with favorite, ignore and play controls
    - GIF audio: MP3 from /GifAudio/ plays in sync with screensaver
    - extract_gif_audio.sh: extracts audio from Batocera scraped videos (experimental)
    - radio.html: station search via radio-browser.info, presets with logo icons
    - LED matrix shows station info for 5 s on play; off by default; 10 s on demand
    - radio_status: mutex-protected snapshots, volatile radioCurrentPreset
    - AsyncTCP stack 4096 -> 8192 to prevent handler stack overflow
    - Git hash embedded at build time, shown in admin panel
    - SD card folder cache no longer re-initialized on every pa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
    [main.cpp]
2026-06-05 Fix & Improve: GIF-Audio, Radio-URL, Build-ID
    GIF-Audio (Verbesserungen):
    - LittleFS-Cache wie Screensaver — kein SD-Scan bei Neustart nach erstem Boot
    - Kein Re-Scan bei Seitenaufruf (war bereits für Screensaver gefixt, fehlte bei Audio)
    - cancelSdScan-Unterstützung
    - DMD-Fortschrittsanzeige und Log konsistent mit Screensaver
    - UI konsistent mit Screensaver-Dateiliste (Pagination, CSS)
    Webradio:
    - Stream-URL-Normalisierung (?ti= entfernt, verhindert Library-Hänger)
    Build (Fix):
    - GIT_HASH + GIT_BRANCH im Webradio-Environment war nie aktiv — jetzt korrekt
    - Admin-Seite zeigt [hash@branch]
    Docs:
    - Stereo-Audio Verkabelung korrigiert (Widerstandswerte, war fehlerhaft)
    - Disclaimer +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
    [main.cpp]
2026-06-07 Empty project
    [ZeDMD_WiFi.kicad_pcb, ZeDMD_WiFi.kicad_sch]
2026-06-07 Initial setup
    [ZeDMD.kicad_sch, ZeDMD_WiFi.csv, ZeDMD_WiFi.kicad_pcb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]
2026-06-12 Release v1.1: GIF-Audio, diagnostics, SD improvements, Batocera integration
    Features:
    - GIF-Audio: /gif_audio_play + /gif_audio_stop endpoints with fuzzy filename
    matching against PSRAM-cached file list; global on/off toggle; per-file
    preview button in UI
    - Diagnostics: boot statistics and reset reason counters via /diag endpoint;
    admin reset + log deletion
    - SD card: folder upload via /upload_sd; LittleFS upload guard; timeout/error
    handling with auto-retry in UI; unified storage display
    - Radio: station name shown next to clock in clock mode
    - Screensaver: collapsible file list, Prev/Next at top, no black gap between GIFs
    - HTML: ETag + Cache-Control for faster page loads
    Refactor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
    [main.cpp]
2026-06-18 Release v1.2: Webradio-Verbesserungen, Display Text, Heap-Fixes, Docs-Restrukturierung
    - Manuelle URL-Eingabe in radio.html (Name + URL, Test + Speichern)
    - Bitrate in Suchergebnissen angezeigt
    Display Text (experimentell):
    - Beliebigen Text über Web-UI auf LED-Matrix senden
    - Statisch (zentriert) oder scrollend (automatisch bei langem Text)
    - RGB-Farbwahl, konfigurierbare Dauer (5–60 s)
    - Unterbricht laufende GIF-Schleifen; stellt sie danach wieder her
    - DisplayTextScaled() in LEDMatrix (tiny4x6 mit Skalierung)
    Stabilität & Bugfixes (heap-fragmentation Branch):
    - Wetter-HTTP-Antwort in PSRAM gepuffert (kein SRAM-Spike beim Abruf)
    - Wetterdaten-Synchronisation zwischen CPU-Ke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
    [LEDMatrix.h, main.cpp]
2026-06-21 Placement V1.1
    [ZeDMD_WiFi.kicad_pcb]
2026-06-22 Schematics update and pngs added
    [ZeDMD_WiFi.kicad_sch, ZeDMD_WiFi.xlsx]
2026-06-23 Release v1.4 — Timezone, SD Mount/Eject, radio.html UX, Upload-Verbesserungen
    - Zeitzone auf Admin-Seite konfigurierbar — Dropdown mit Presets (DE/AT/CH, UK,
    UTC, US), Custom-Option für beliebige POSIX-Strings; gespeichert in LittleFS
    - SD-Karte per UI mounten und auswerfen — Mount/Eject-Toggle-Button auf der
    Hauptseite; remount mit Retry-Loop, aktualisiert Dateilisten automatisch
    - GIF-Upload zeigt Vorschau direkt nach dem Upload
    - Upload-Zielordner frei wählbar — gezielter Cache-Invalidierung statt Vollscan
    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
2026-06-26 Placement ready
    [ESP32-S3-N16R8.kicad_sch, ZeDMD_WiFi.kicad_pcb, ZeDMD_WiFi.kicad_sch]
2026-06-28 PCB updates and production files
    [ZeDMD_WiFi.kicad_pcb, ZeDMD_WiFi.kicad_sch, ZeDMD_WiFi.xlsx]
2026-06-29 Release v1.5.1: 16×16 Wetter-Icons, SD-Init robuster, Emoji-Bugfixes
    Feature: Alle 8 Wetter-Icons als native 16×16 Pixel-Art neu gezeichnet
    — Sonne mit Strahlen, Mondsichel, Wolke, Regen, Schnee, Blitz, Mischbewölkt
    — Farbgradienten pro Icon; 8×8 Forecast-Icons unverändert
    Feature: Emoji-Lauftext mit 33 Pixel-Art-Icons (❤️ ⭐ 🔥 😊 🎉 …)
    — RGBA-Icons in LittleFS (/icons/ + /icons_small/)
    — Emoji-Picker im Web-UI
    Feature: Wetter-Display-Modi — Uhr+Wetter+Screensaver-Zyklus
    Feature: SD-Karten-Mount/Eject per Web-UI
    Feature: Konfigurierbare Zeitzone (Admin-Seite, POSIX-String)
    Feature: GIF-Vorschau im Browser (Favorit/Ignorieren/Abspielen)
    Feature: GIF-Audi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
    [main.cpp]
2026-06-29 Docs: elabree-Link auch im Custom-PCB-Abschnitt
2026-06-30 Remove duplicate schematics
2026-07-12 change DevKit row spacing
    [ESP32-S3-N16R8.kicad_sch, ZeDMD.kicad_sch, ZeDMD_WiFi.kicad_pcb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]
2026-07-18 Release v1.5.2 — WiFi/SD/Webradio Fork
    - Tabbed Web UI (Screensaver / Display / Radio tabs)
    - Display Timer: scheduled daily on/off + instant toggle button
    - Webradio: station logos on LED matrix (32x32 RGBA, fuzzy-match)
    - Webradio: Stereo/Mono toggle
    - Webradio: L/R channel swap (audio library patch via build script)
    - Webradio: 3-band Equalizer (Bass/Mid/Treble), persisted in LittleFS
    - Rescan buttons for screensaver and GIF audio file lists
    - SD card SPI speed up to 40 MHz (PCB layout), shared mount function with fallback chain
    - Weather icons: 8x8 forecast icons redrawn (11 icons, drizzle/shower/snow added)
    - Boot status messages bottom-left, no logo overlap
    - Custom boot lo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
    [radioart_map.csv]
2026-07-22 Fix + Refactor: DisplayRGB, RefreshSetupScreen, GifAudio-Rescan, clear_screensaver_cache
    - DisplayRGB(): Labels "red/green/blue" jetzt in Farbe statt schwarz auf schwarz
    - RefreshSetupScreen(): vereinfacht — nur Boot-Logo, kein Diagnose-Text auf Display
    (USB-Modus, Debug-Level etc. sind über admin.html zugänglich)
    - DisplayRGB() explizit nach RefreshSetupScreen() im RGB-Order-Endpoint aufgerufen
    - ClearScreensaverFilesNow(): aus LoadScreensaverFiles() extrahiert (Mutex-Block)
    - TriggerGifAudioRescan(): RAM-Cache sofort leeren + Disk-Cache + Flag setzen
    gif_audio_upload/delete/rescan nutzen jetzt TriggerGifAudioRescan()
    - GET /clear_screensaver_cache: Ordner-Caches löschen ohne Neu-S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
    [main.cpp]
2026-07-22 Fix: LittleFS cache-Löschung, Rescan-Button, UI zweispaltig, Safari-Fix
    [main.cpp]
2026-07-22 feat: SD-Kartenwechsel-Erkennung, Folder Refresh, Rescan-Bugfix, Safari-Watchdog
    - checkSDCardIdentity(): UUID (/zedmd_id.txt) beim Mount lesen/schreiben,
    bei Kartenwechsel alle Ordner-Caches automatisch invalidieren
    - Neuer Endpoint /sd_folders_refresh: nur Ordnerliste neu einlesen,
    kein Cache-Löschen, kein File-Scan
    - /screensaver_rescan setzt jetzt auch sdFoldersRefreshNeeded (Bugfix:
    Ordnerliste wurde nach Full Rescan nicht aktualisiert)
    - ssPollReady() ruft nach Rescan auch loadSDFolders() auf (Bugfix)
    - Neuer Button "Refresh Folders" in UI, "Rescan SD" → "Full Rescan"
    - loadSDFolders(): setTimeout-Watchdog (6s) gegen Safari-Hang bei
    hängender SD-Anfrage
    [main.cpp]
2026-07-23 fix: I2S L/R Kanalvertauschung auf ESP32-S3 — Gain() Return korrigiert
    Auf dem ESP32-S3 gibt der Legacy-I2S-DMA-Shim (v[LEFTCHANNEL]<<16)|v[RIGHTCHANNEL]
    invertiert aus. Return-Wert in Gain() zu (RIGHT<<16|LEFT) geändert — damit ist
    swap=false der korrekte Default für korrekt verdrahtete Hardware. Der swapChannels-
    Button bleibt für physisch falsch verdrahtete Setups erhalten.
    Patch in scripts/patch_audio_lib.py ergänzt (idempotent, gilt bei Library-Neuinstall).
2026-07-24 Docs: README/LIESMICH Korrekturen P2/P3
    - Stereo/Mono: separate "Stereo" + "Mono" Buttons (statt "Stereo / Mono")
    - L/R Swap: Button-Label korrigiert ("Swap L/R" → "L/R Swap")
    - Emoji-Picker: Anzahl 33 → 34
    - Credits: elabree-Link mit KiCad-Dateien ergänzt (kein "in preparation" mehr)
    - ADMIN.md: I2S-Pins korrigiert (BCK=9, WS=14, DATA=21)
2026-07-24 Docs: KiCad-Links auf eigenes Repository aktualisiert (PR #1 gemergt)
2026-07-31 release: v1.5.3 — Clock redesign, MQTT fields, weather improvements, UI fixes
    Clock:
    - 7-Segment digits fully redesigned: chamfered outer corners, beveled
    inner corners and crossing points for authentic segment look
    - Screensaver Mode 5 (scrolling text) + Mode 6 (clock + scrolling text)
    Weather / MQTT:
    - MQTT: configurable JSON field names for temp/humidity/wind/pressure
    (admin.html + firmware, backwards-compatible load)
    - MQTT per-device client ID (shortId) + configurable subscription topic
    - OpenMeteo fallback: gray color when MQTT station silent >10 min
    - Unknown WMO weather code: question mark icon via PSRAM GetIcon()
    - English log messages with consistent Weather: prefix
    Screens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
    [LEDMatrix.h, main.cpp]
2026-08-26 release: v1.7.0 — WDT stability, weather icons, The Arcade branding
    Critical stability: enableLoopWDT() was never called — all esp_task_wdt_reset()
    calls were silent no-ops for the lifetime of the project. The TWDT now actively
    monitors the loop task. Three hang points exposed and fixed:
    - TryLoadFolderCache(): 3700+ line reads without WDT reset → reboot loop
    - SoftAP countdown: 19s loop without reset
    - clockInit(): getLocalTime(5000ms) at the WDT boundary
    - Weather icons (17×17) stored in LittleFS /icons_weather/ — uploadable without reflash
    - The Arcade boot logo (ppuc.raw → The_Arcade.raw), crash-screen fix
    - /upload_asset endpoint for PNG/RAW files to LittleFS root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
    [LEDMatrix.h, main.cpp]
